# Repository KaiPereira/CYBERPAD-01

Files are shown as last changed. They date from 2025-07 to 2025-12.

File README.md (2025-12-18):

# CYBERPAD-01 - Cyberpunk Inspired Macropad



The CYBERPAD-01 is a cyberpunk inspired macropad with 3 keys, a rotary encoder, and a whole lotta silkscreen and neopixels. It uses KMK firmware and was meant to serve as a learning opportunity for PCB's, CAD and rendering. 
## Custom Features
- Custom lasercut acrylic top panel
- EC11 Rotary Encoder for anything really
- 3 Keys to program to your heart's content
- 14 SK6812 MINI-E LEDs for backlight and and diffusion
- Cyberpunk inspired case for maximum aesthetic
-  Exposed PCB design with custom silkscreen cuz it's sick
## CAD Design

I used Onshape to design all of my parts. The laser cut acrylic panel is held together using minimalist bolts and spacers attached to the top plate. The actual case is designed so that everything can fit together seamlessly without using any screws or bolts for minimalism and aesthetics while still being secure.

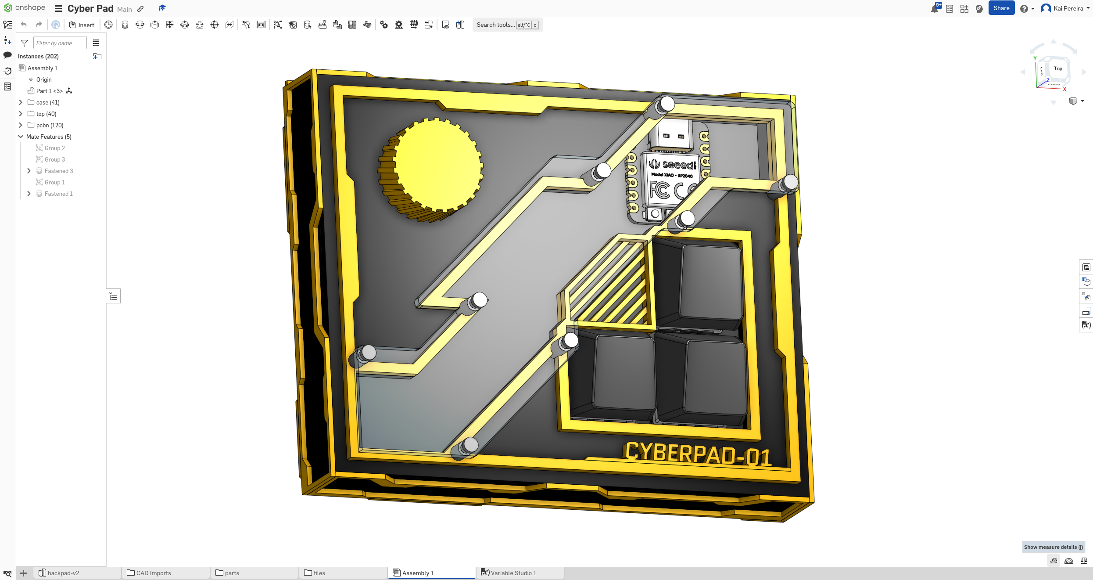
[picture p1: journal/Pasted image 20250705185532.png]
Pasted image 20250705185532.png


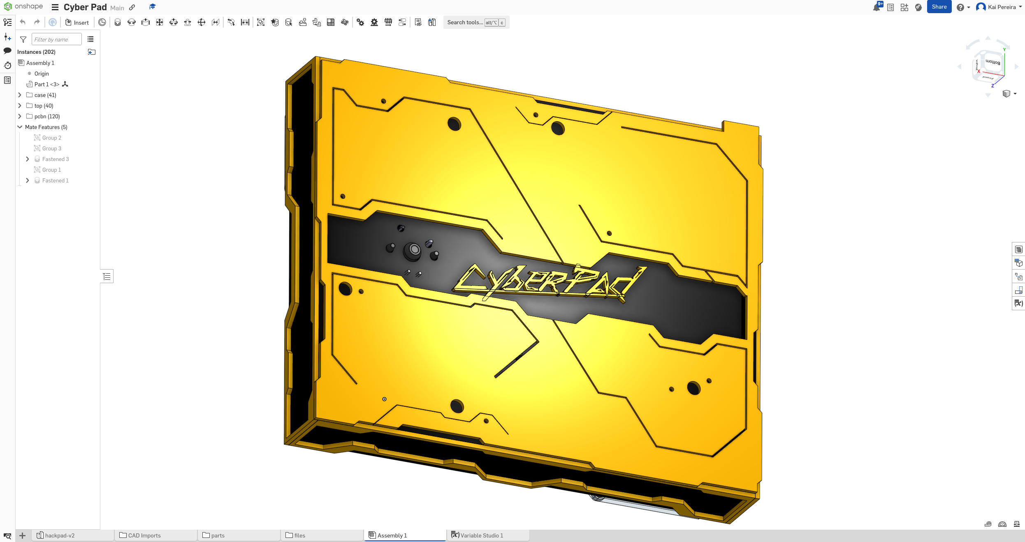
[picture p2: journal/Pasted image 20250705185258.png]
Pasted image 20250705185258.png


It comprises of 4 separate 3D printed parts though, the bottom plate/aesthetic walls, the walls, and the top plate, the rotary encoder knob, with the 5th part being the laser cut acrylic top panel, so it's a bit difficult to print, but manageable. [Onshape Link](https://cad.onshape.com/documents/183c405de5c750134bf8a1de/w/282fa5c96ffeba0ae16f58ec/e/f98acd70bf74a51e29d61d0d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)
## PCB Design

The PCB was designed using KiCad and then I used Figma and the KiCad image converter for creating the silkscreen layers. I actually imported the case design into KiCad so I could use it as reference for the silkscreen which turned out really well.

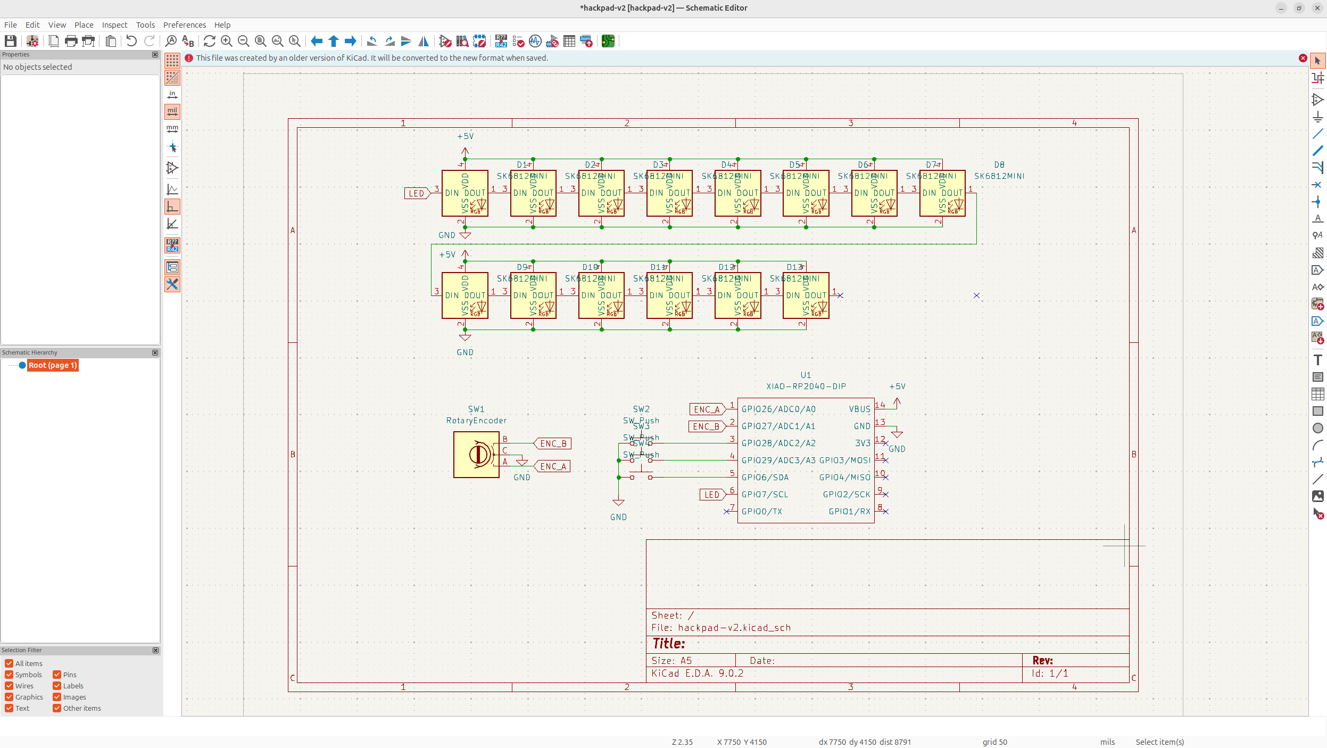
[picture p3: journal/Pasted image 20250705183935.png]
Pasted image 20250705183935.png

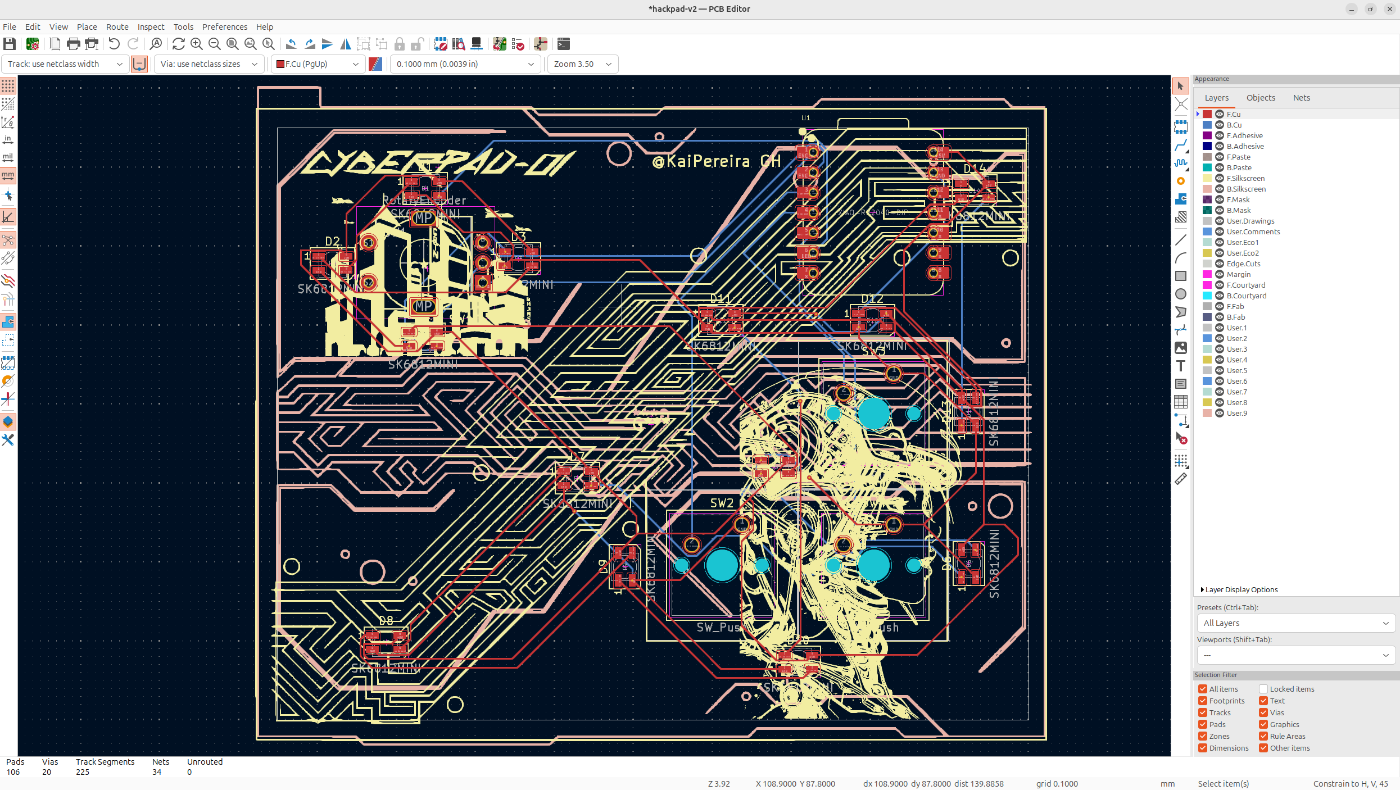
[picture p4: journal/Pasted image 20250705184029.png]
Pasted image 20250705184029.png


## Firmware

The CYBERPAD-01 uses KMK firmware (written in Python) and was relatively straightforward.
- The rotary encoder changes volume
- The keys just act as VIM macro's
- Neopixels to backlight and diffuse any color you want

I'll probably make it a bit more complicated in the future, but I think it's kind of handy to have a macropad for some really complicated VIM stuff.

## Bill of Materials (BOM)

Here's everything you'll need to build the CYBERPAD-01:
- 3x Cherry MX Switches
- 3x Keycaps of your choice (I would personally suggest black ones)
- 14x SK6812 MINI-E LEDs
- 1x EC11 Rotary Encoder
- 1x Seeed XIAO RP2040
- 8x M2 Nut and Bolt, 1.5cm, Low profile top
- 8x M2 Spacers, 3mm diameter, 0.6cm, circular, non-threaded
- 1 Case (3 printed parts)
- 1 Custom Laser Cut Acrylic Panel

## Credits and Help

Thanks to @qcoral and @acornitum for starting highway and reviewing projects. @M0HID and @jamdotjar for helping me with Blender and @cheyao for the firmware starter code and helping me make my first macropad!

Also, thanks so much to [PCBWay](https://www.pcbway.com/) for sponsoring the yellow silkscreen PCB's, they look absolutely amazing and I'd highly suggest checking them out if you need really cool looking PCB's and fast turnaround!

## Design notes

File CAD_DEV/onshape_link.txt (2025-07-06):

https://cad.onshape.com/documents/183c405de5c750134bf8a1de/w/282fa5c96ffeba0ae16f58ec/e/f98acd70bf74a51e29d61d0d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

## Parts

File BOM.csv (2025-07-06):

Part | QTY | Cost | Supplier | Purpose | Notes | Other Notes
From Hackpad Kit
SK6812 MINI-E LEDs | 14 |  |  | Neopixels for PCB
MX-Style switches | 3 |  |  | Switches for PCB
EC11 Rotary encoders | 1 |  |  | Rotary Encoder for PCB
Seeed XIAO RP2040 | 1 |  |  | MCU for PCB
Keycaps - Painted | 3 |  |  | For decoration
Sourcing Myself
M2 Bolts, 1.5cm, Low profile top | 8 |  | Already Have | For bolting the acrylic
M2 Spacers, 3mm diameter, 0.6cm, circular, non-threaded | 8 |  | Already Have | For spacing the acrylic from the top
3D Printed Case | 1 |  | Going to get my cousin to print
Acrylic Top Plate | 1 |  | Already Have | Decoration
EVERYTHING IS SOURCABLE MYSELF WITHOUT THE GRANT

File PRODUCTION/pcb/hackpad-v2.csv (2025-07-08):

Id | Designator | Footprint | Quantity | Designation | Supplier and ref
1 | D5,D7,D12,D9,D1,D10,D11,D6,D2,D4,D14,D13,D3,D8 | LED_SK6812MINI_PLCC4_3.5x3.5mm_P1.75mm | 14 | SK6812MINI
2 | SW2,SW3,SW4 | SW_Cherry_MX_1.00u_PCB | 3 | SW_Push
3 | SW1 | RotaryEncoder_Alps_EC11E-Switch_Vertical_H20mm | 1 | RotaryEncoder
4 | U1 | XIAO-RP2040-DIP | 1 | XIAO-RP2040-DIP

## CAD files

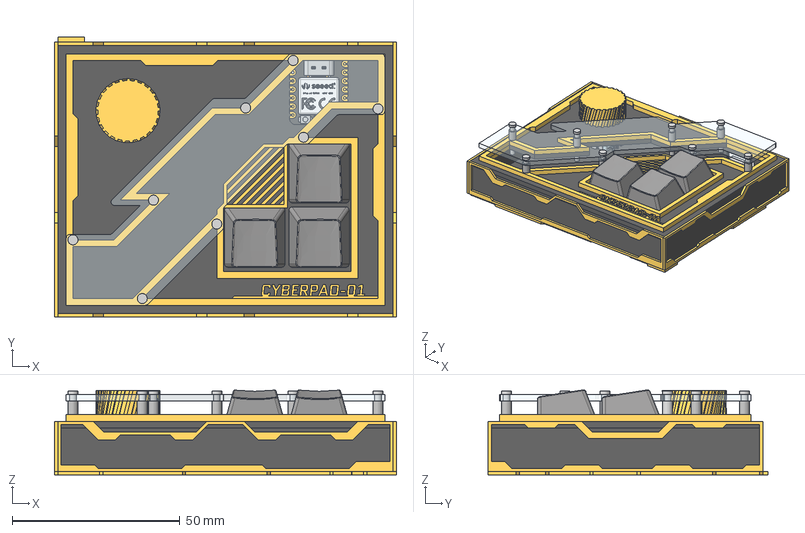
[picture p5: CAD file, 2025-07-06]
CAD_DEV/Full Case.step
102.0 x 83.5 x 25.3 mm
Seeed Studio XIAO RP2040 v26 x 83
Cherry MX_1 x 8
Cherry MX x 8
1x1 R1 v23
EC11 x 9
Cherry MX_2 x 8
_autosave-hackpad-v2_PCB
1x1 R1 v23_2
1x1 R1 v23_1

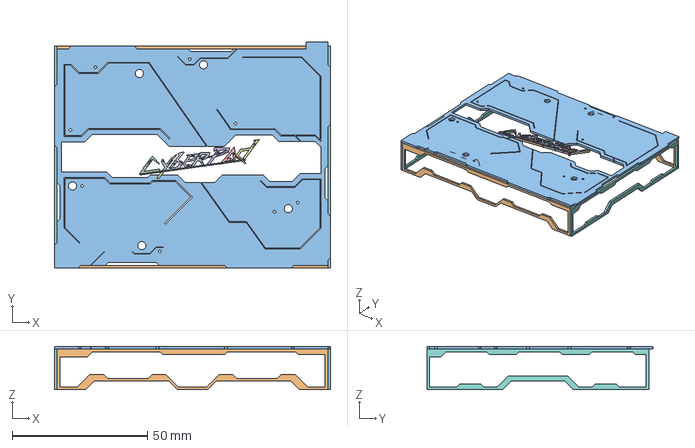
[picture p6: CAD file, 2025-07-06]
PRODUCTION/CAD/CYBERPAD-01 Base.step
102.0 x 83.5 x 16.0 mm

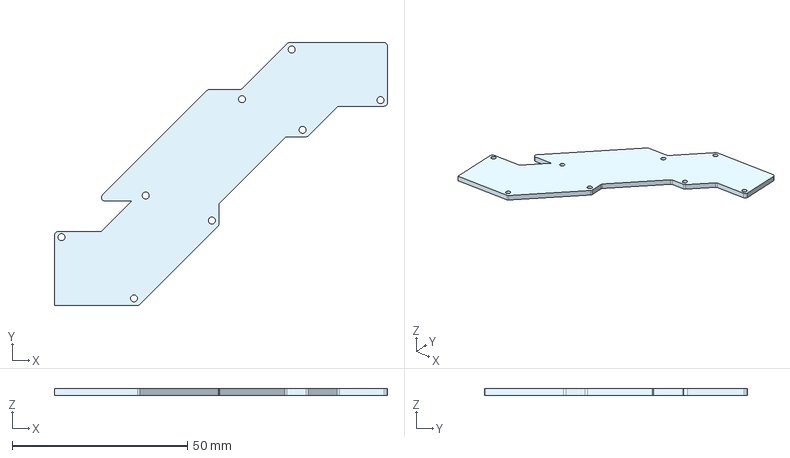
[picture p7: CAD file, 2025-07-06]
PRODUCTION/CAD/CYPERPAD-01 Acrylic.step
95.0 x 75.0 x 2.00 mm

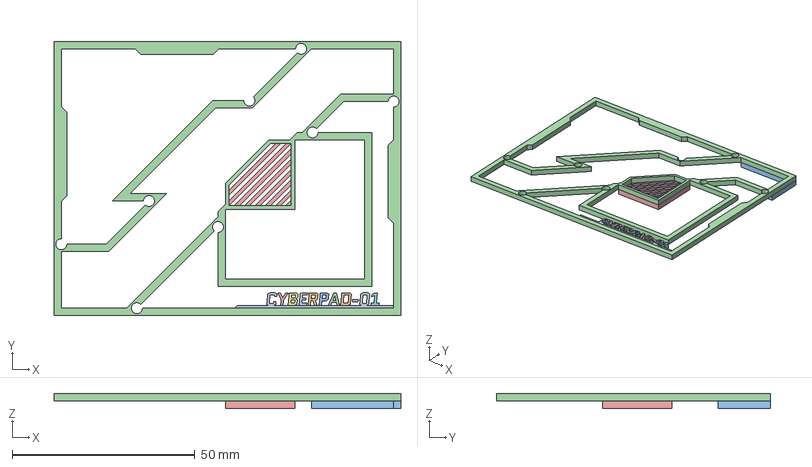
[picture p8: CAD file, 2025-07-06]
PRODUCTION/CAD/CYBERPAD-01 Top Decorational.step
95.0 x 75.0 x 4.00 mm

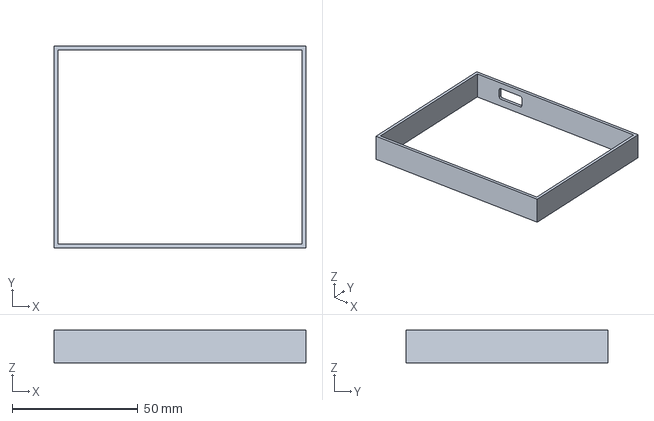
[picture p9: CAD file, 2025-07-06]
PRODUCTION/CAD/CYBERPAD-01 Walls.step
100.0 x 80.0 x 13.0 mm

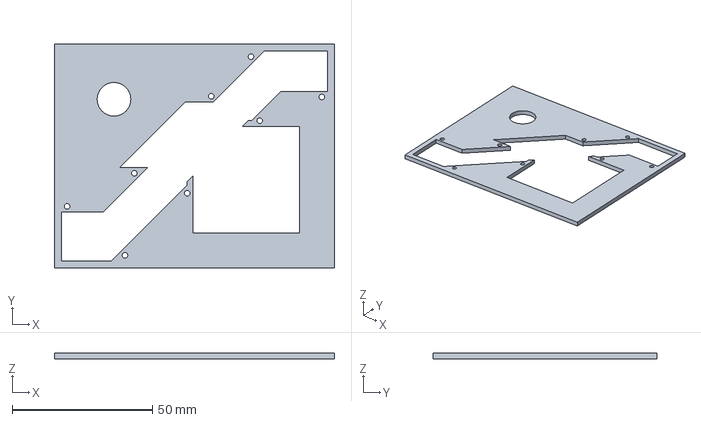
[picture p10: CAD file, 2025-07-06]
PRODUCTION/CAD/CYBERPAD-01 Top.step
100.0 x 80.0 x 2.00 mm

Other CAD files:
RENDERS/Untitled.blend

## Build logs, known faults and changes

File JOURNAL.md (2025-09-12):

---
title: "CYBERPAD-01"
author: "Kai Pereira"
description: "3 key, cyberpunk inspired macropad with backlight and a rotary encoder"
created_at: "2025-07-08"
---

## Total Time Spent on This Project: 29 Hours

## Day 1 - PCB - 5 Hours - Jun 30th

The Cyber Pad is going to be an extremely futuristic looking macropad.

It's going to be a test of my design skills and just a fun side project I want to build.

I really like the cyberpunk aesthetic and want to make a series of projects that go with the theme, maybe ending up with a cyberpunk themed 3D printer.

Anyways first I'm going to do some drawing and brainstorming on how I want this thing to look.

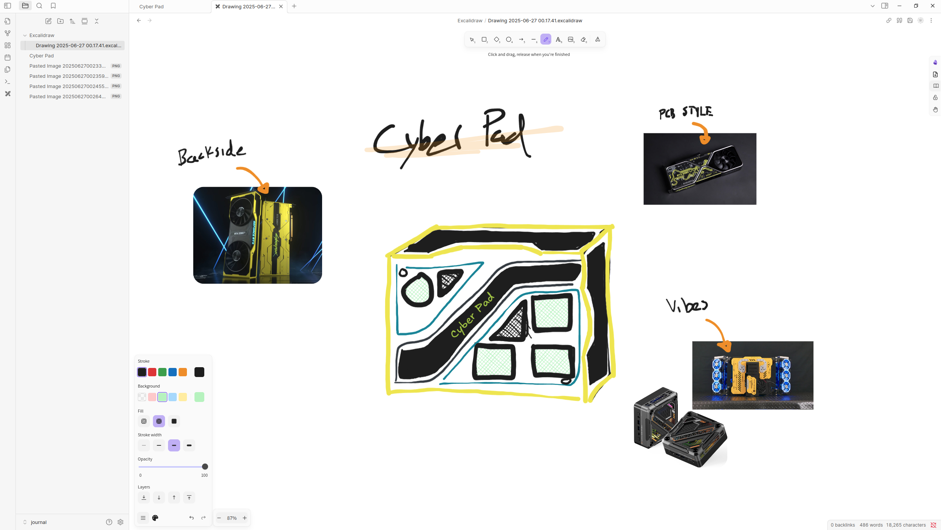
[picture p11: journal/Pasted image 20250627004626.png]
Pasted image 20250627004626.png


Anyways this is my main inspiration that I spent some time on, I really like the buttons like this so I think I'm going to leave it like that. I don't want any OLED's or anything because I feel like that ruins the vibe so I'm going simple with a major focus on the design.

Also this design seems quite blocky but the actual thing will be nice and round.

Now let's whip up a quick schematic. I'm trying to stick to best practices possible and I'm going to do the neopixels once I'm done my case!

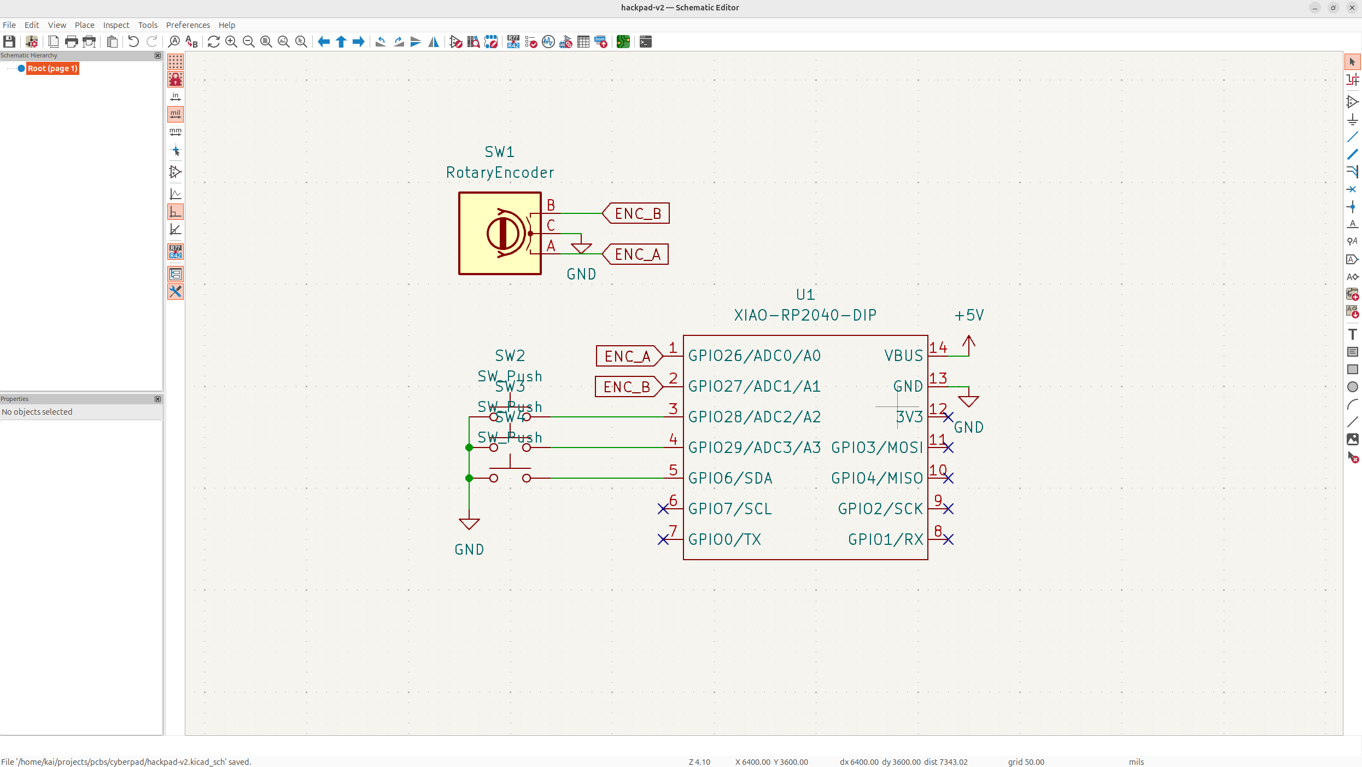
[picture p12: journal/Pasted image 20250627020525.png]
Pasted image 20250627020525.png


Now time to do the PCB, took me quite a long time because I was figuring out some footprint and alignment stuff.

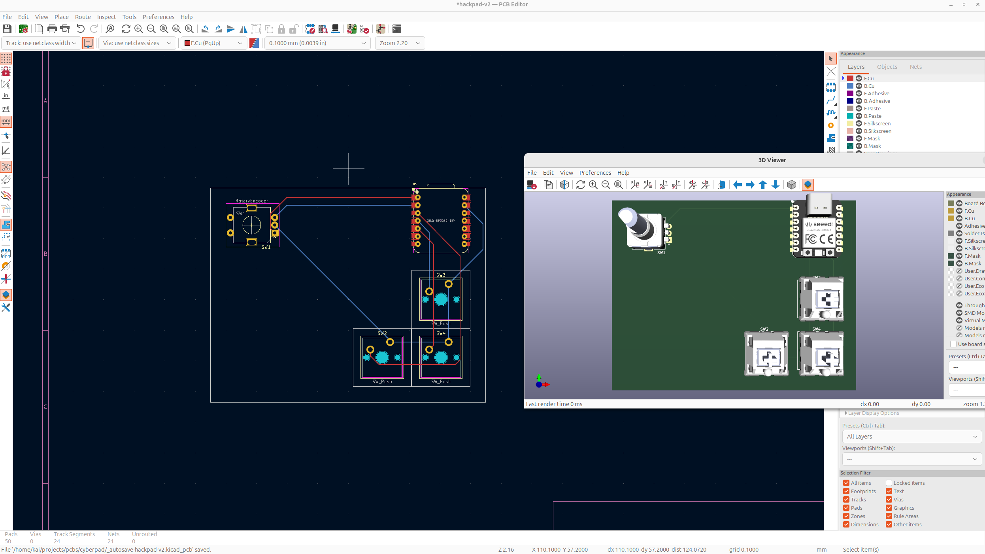
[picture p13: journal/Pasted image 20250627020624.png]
Pasted image 20250627020624.png


## Day 2 - Case - 8 Hours

Now I'm going to start modelling the case, I'm going to give about 1cm total on each side just as a placeholder and then I'm going to model the main interior of the bottom I want to go for.

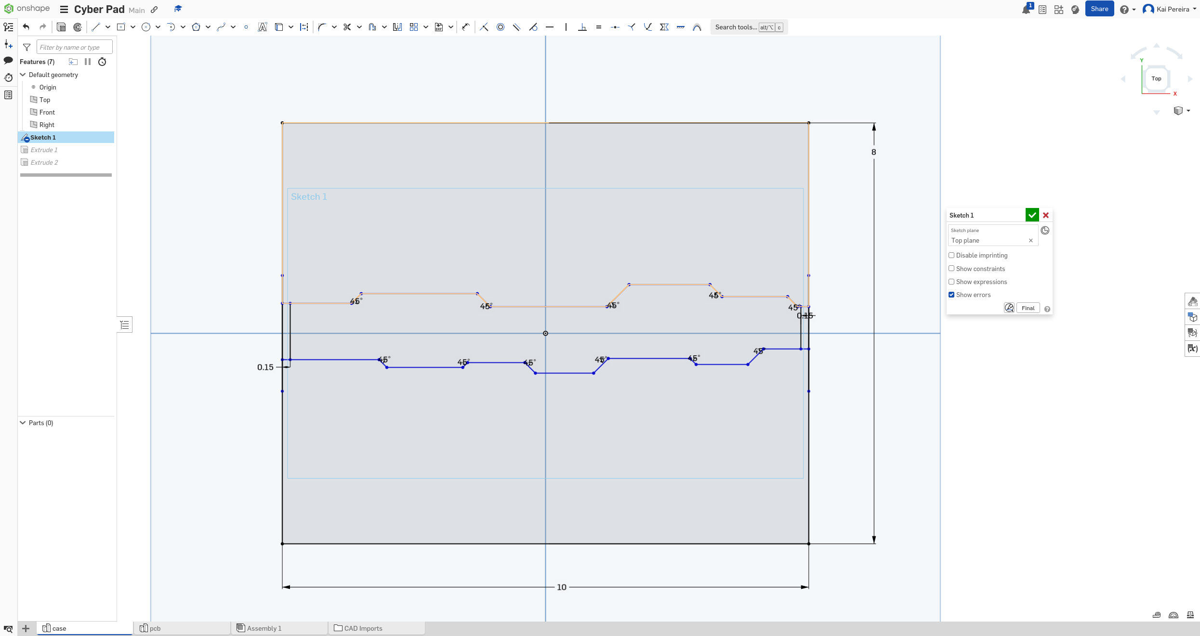
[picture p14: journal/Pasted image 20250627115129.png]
Pasted image 20250627115129.png


Now that I have this base, I'm going to add some designs along the side. I like the way the graphics card is done, so I'm going to do something similar to that.

Now I kind of want to go with a polarizing like effect which will go with the top of my case:

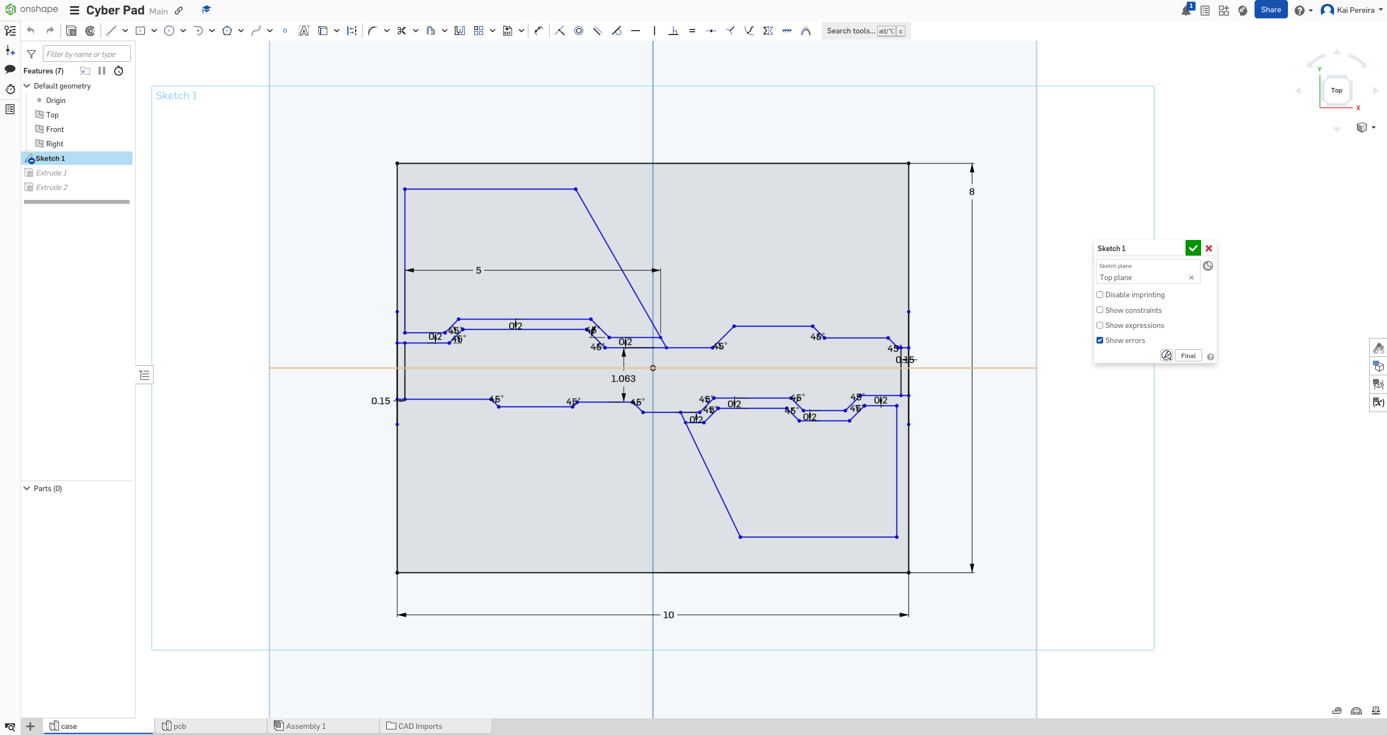
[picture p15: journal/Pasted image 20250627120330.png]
Pasted image 20250627120330.png


Now I kind of want to with with some other designs just to fill the space, I'll look into the graphics card design a bit more and kind of go off that. And now I have a really col base to go off of:

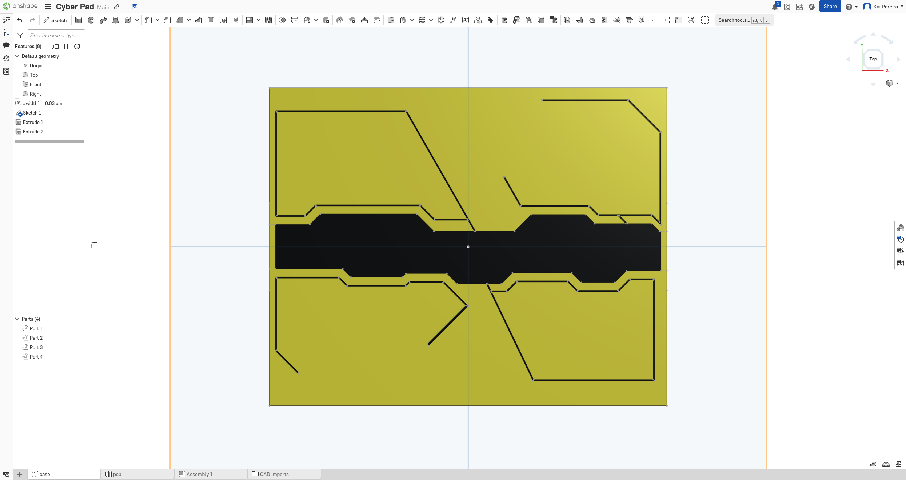
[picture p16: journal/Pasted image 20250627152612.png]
Pasted image 20250627152612.png


Now I'm going to make the shapes a bit more complicated to give it some detail. Now it's looking sick.

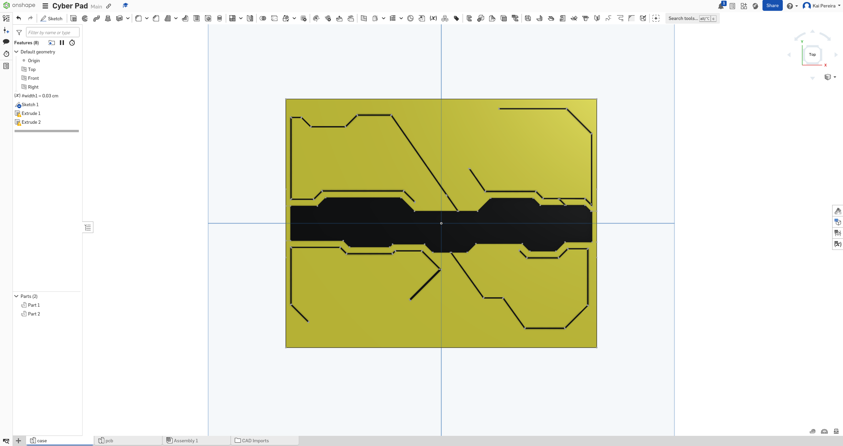
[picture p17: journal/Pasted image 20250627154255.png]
Pasted image 20250627154255.png


Now I really like this style where there's details on the top and bottom, and circles where all the divits are, so I'm going to first add the cool bottom and top details.

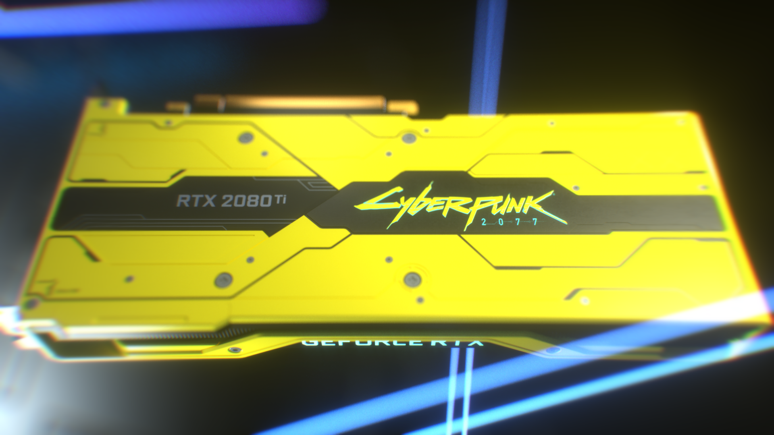
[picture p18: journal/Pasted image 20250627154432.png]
Pasted image 20250627154432.png


And the minor details are really starting to add up.

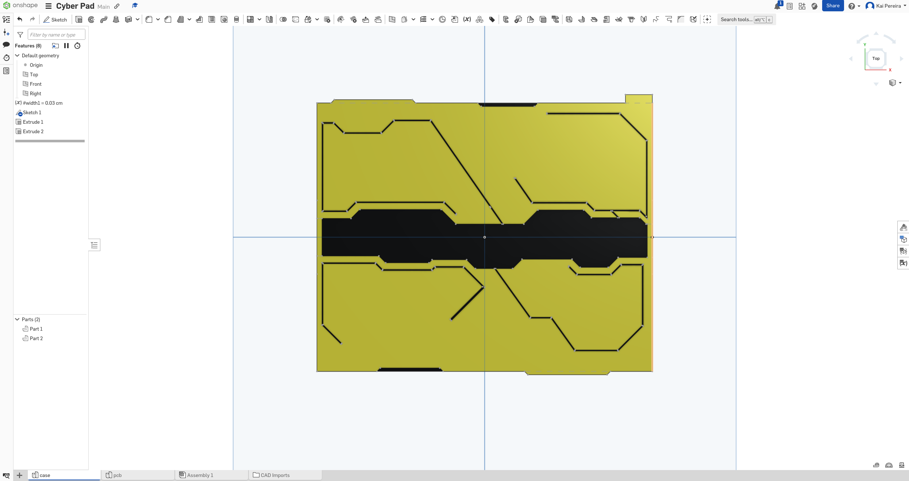
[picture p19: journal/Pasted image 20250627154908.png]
Pasted image 20250627154908.png


Now I want some of those extra thin lines. It's starting to look incredible!

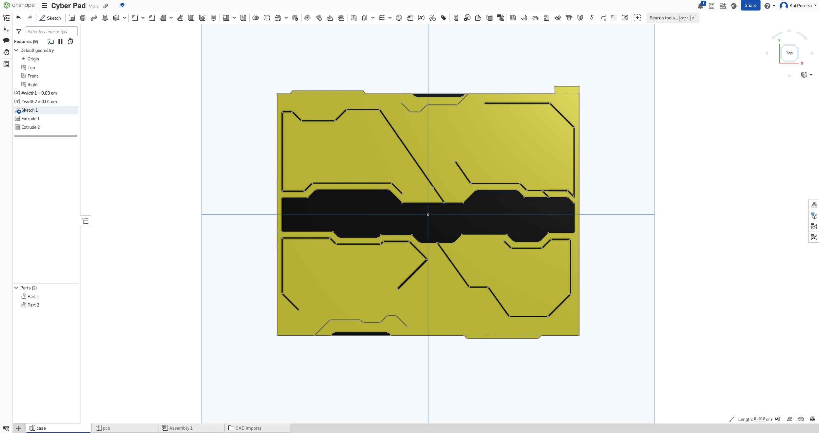
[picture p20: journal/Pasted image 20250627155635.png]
Pasted image 20250627155635.png


Next I added the circles and the logo. The logo is done in inkscape with the Cynata font.

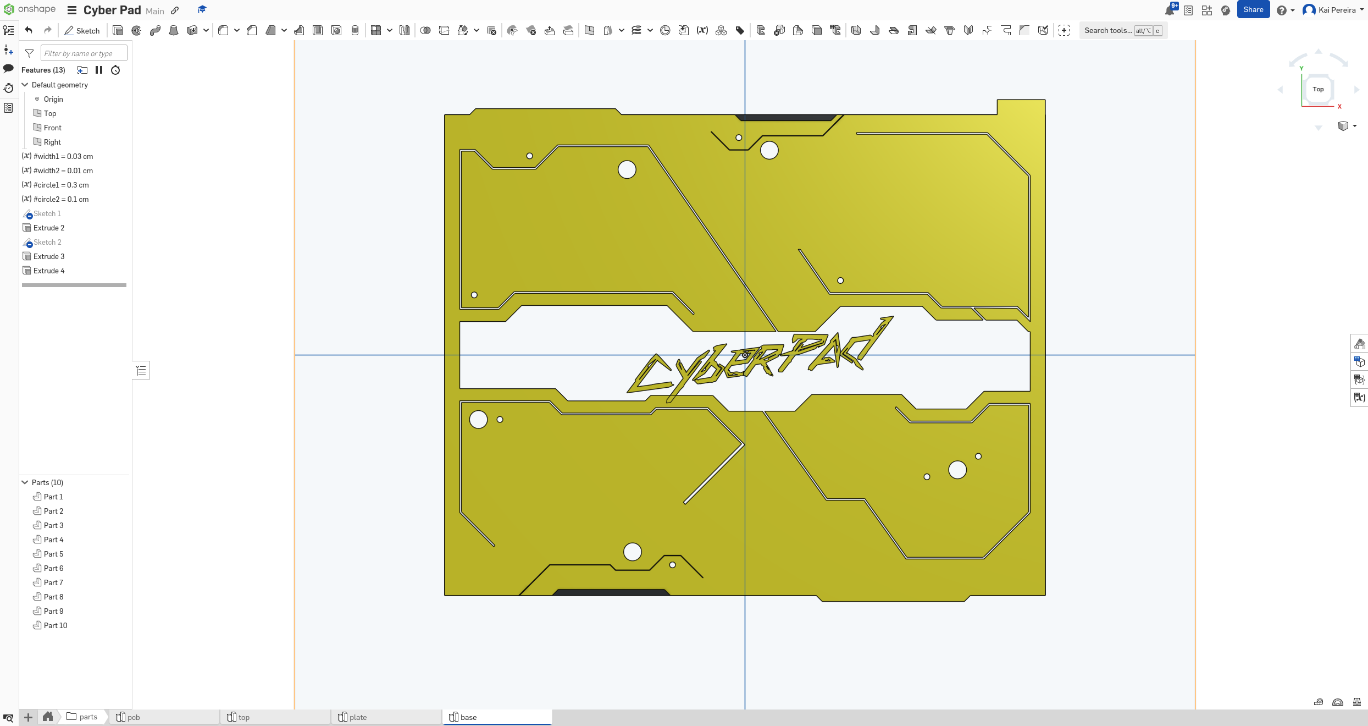
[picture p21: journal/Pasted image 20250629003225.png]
Pasted image 20250629003225.png


Next I added some walls to it, and then created the plate and top plate.

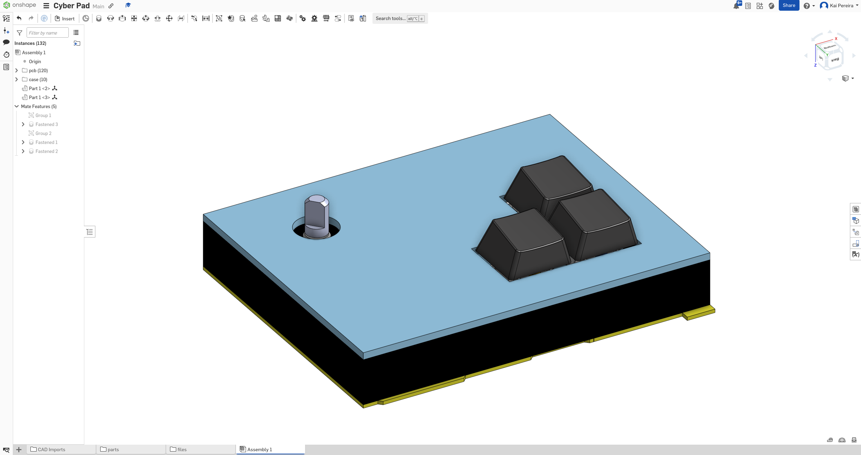
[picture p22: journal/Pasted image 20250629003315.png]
Pasted image 20250629003315.png


Now I'm going to start working on the side designs. I want them to be pretty similar to the GPU design and then make the top like the PC.

Anyways next I added the side designs, I've mirrored each side onto the other side for simplicity and it's looking even better now!

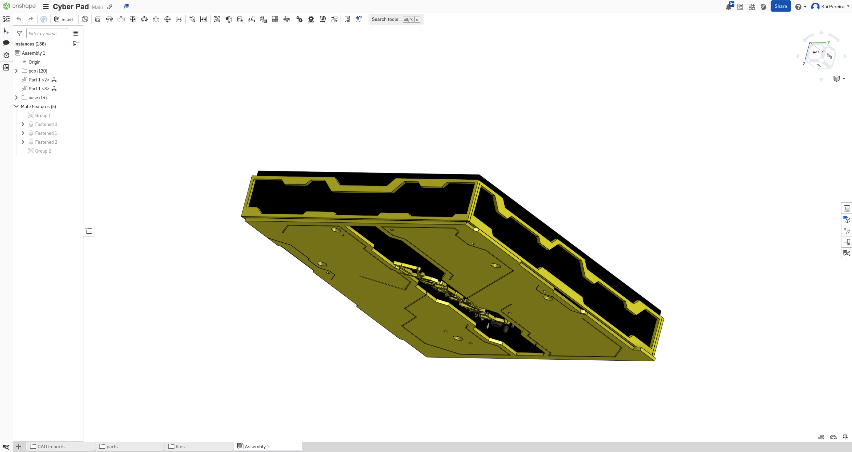
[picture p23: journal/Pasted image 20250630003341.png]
Pasted image 20250630003341.png


Now I kind of have to figure out what I want to do for the top. I really like this style and kind of want to go for something similar. 

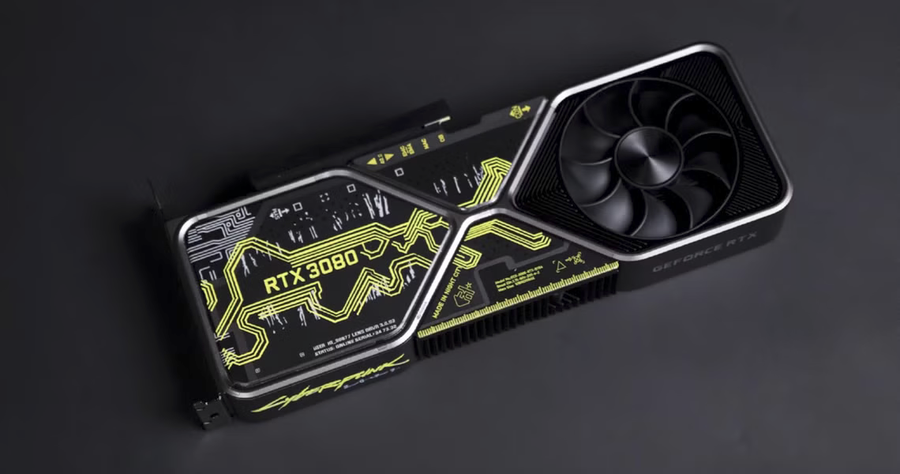
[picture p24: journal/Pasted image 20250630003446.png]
Pasted image 20250630003446.png


I might actually play around with my hackpad colors too, maybe a different color would look better like this green or something. Anyways next I'm going to work on the top. I don't actually have anything in mind, so I'm just going to kind of stick to the same style for now and add more detail later.

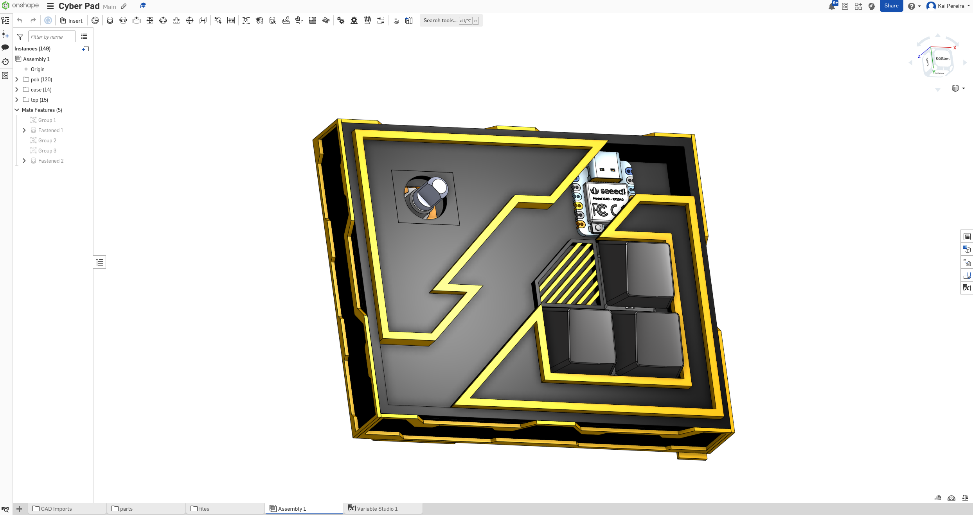
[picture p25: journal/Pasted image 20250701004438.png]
Pasted image 20250701004438.png


And that looks fitting but still now exactly what I want. I really want to see what it would look like if I put a piece of acrylic over the gap now.

This took a long time and I'm sorry I didn't journal all of it, but I added a knob, the acrylic and some text on the bottom. Looking absolutely insane now.

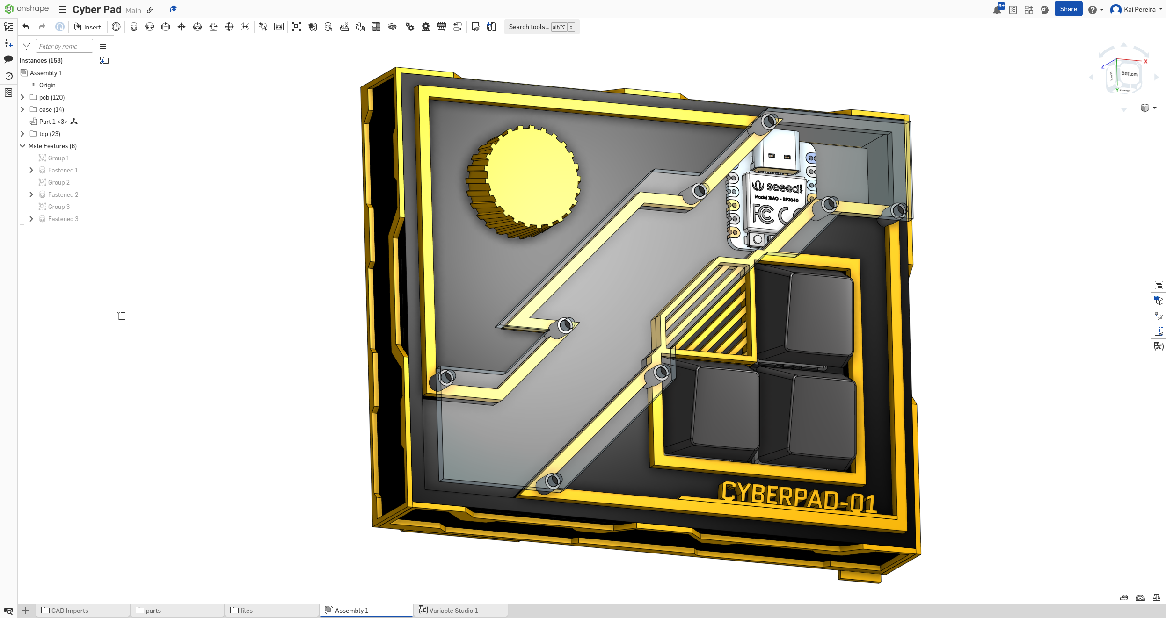
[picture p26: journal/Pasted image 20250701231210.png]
Pasted image 20250701231210.png


But we are not finished, nowhere near the craziness I want. Next I'm going to add all the extra little things to give it dimension. 

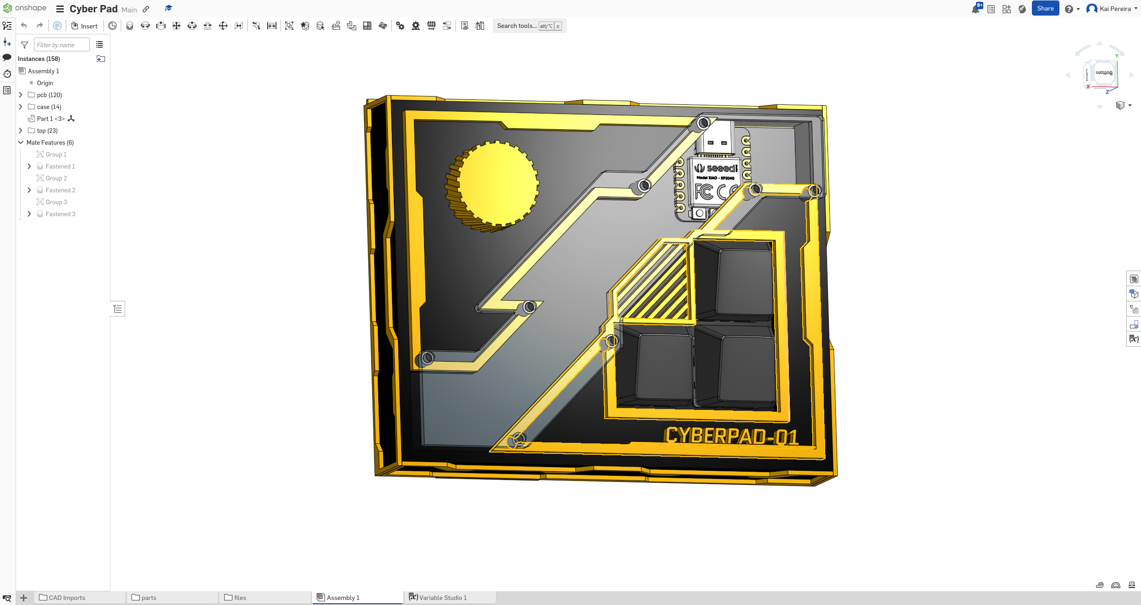
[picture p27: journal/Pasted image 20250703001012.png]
Pasted image 20250703001012.png


I also refined the design a bit so it's easier to print and it looks pretty good. 

## Day 3 - Refining the PCB and Case - 4 Hours

Next I need to customize the PCB so that it looks rlly cool inside of the case. I wanna go for like exposed trace with cyberpunk drawings style. I used the case DXF as a reference point, and then used figma to draw the lines. Then I just add the image properly scaled to kicad.

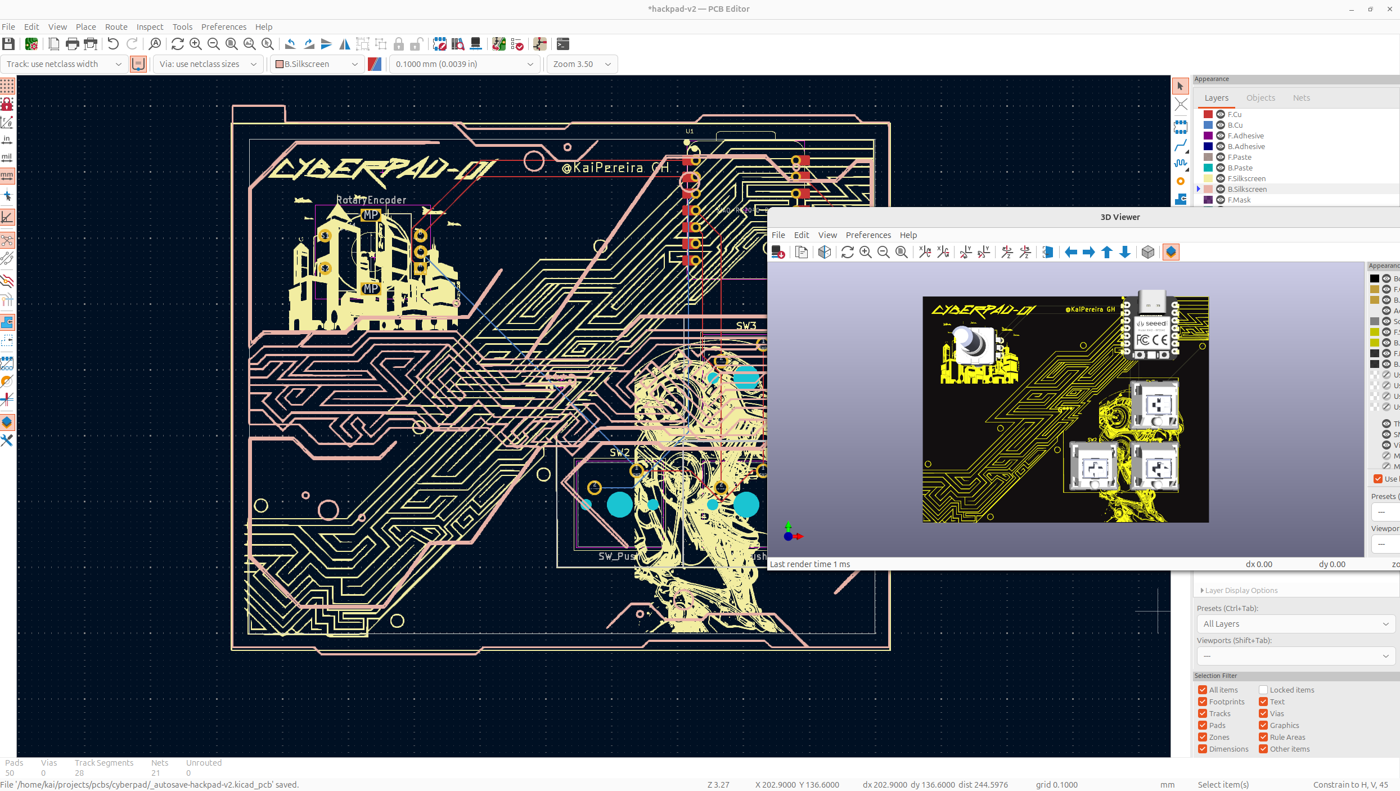
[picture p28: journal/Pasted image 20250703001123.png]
Pasted image 20250703001123.png


Now I completely forgot to add the neopixels so let me do that real quick.

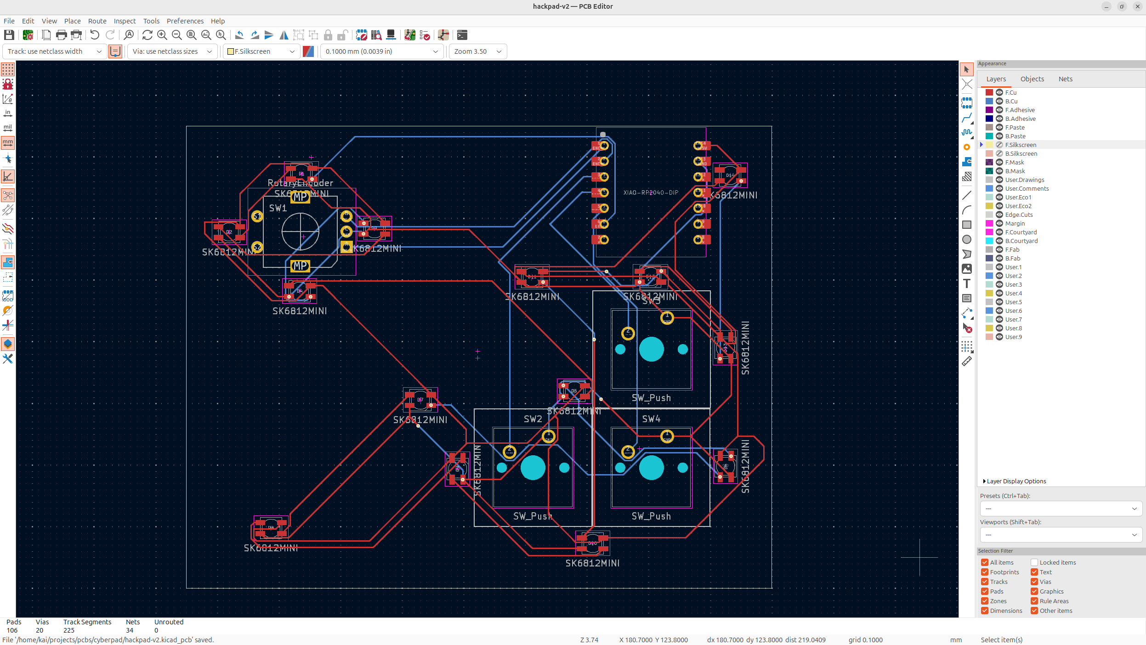
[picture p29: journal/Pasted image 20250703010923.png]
Pasted image 20250703010923.png


Rewired + new schematic.

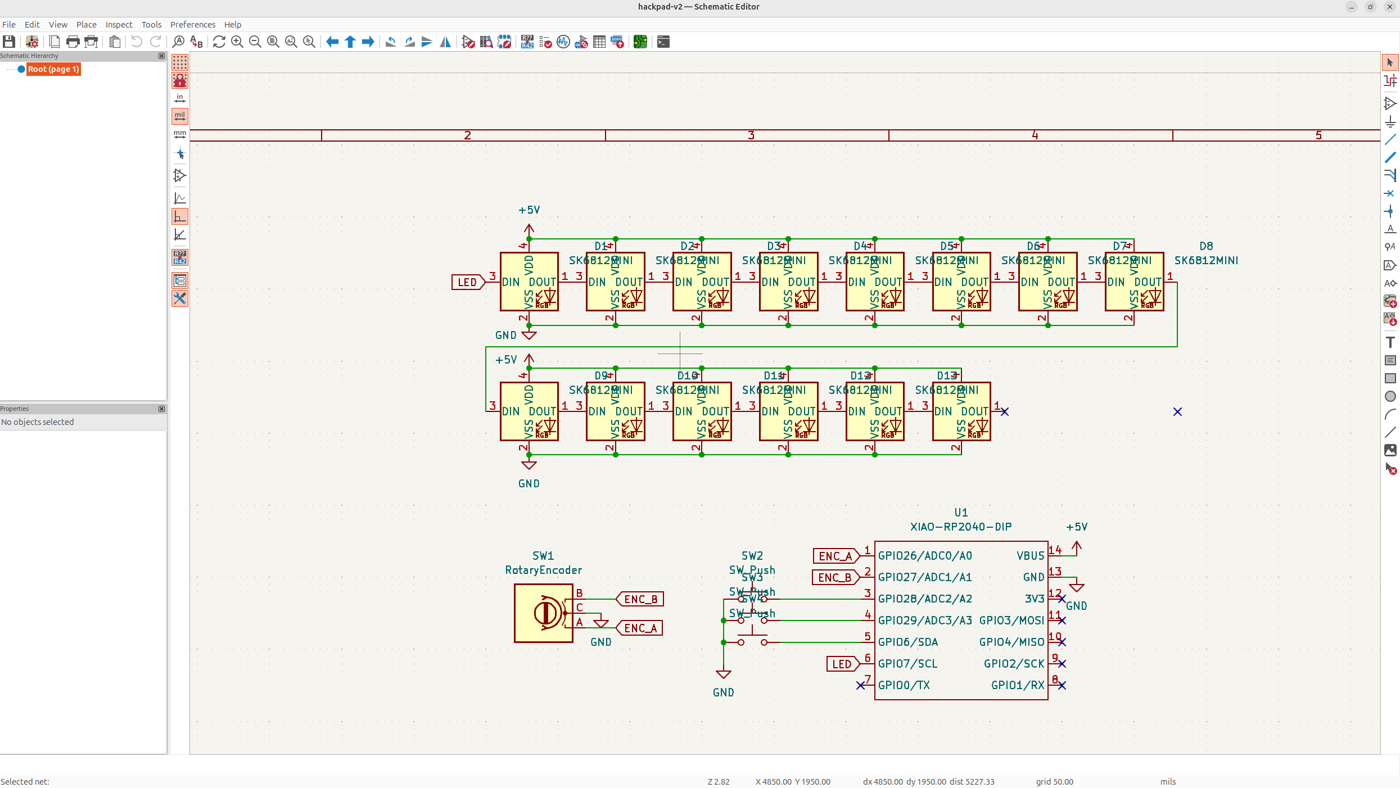
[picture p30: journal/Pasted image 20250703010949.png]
Pasted image 20250703010949.png


Next I did the firmware. It was really simple, just some python with KMK.

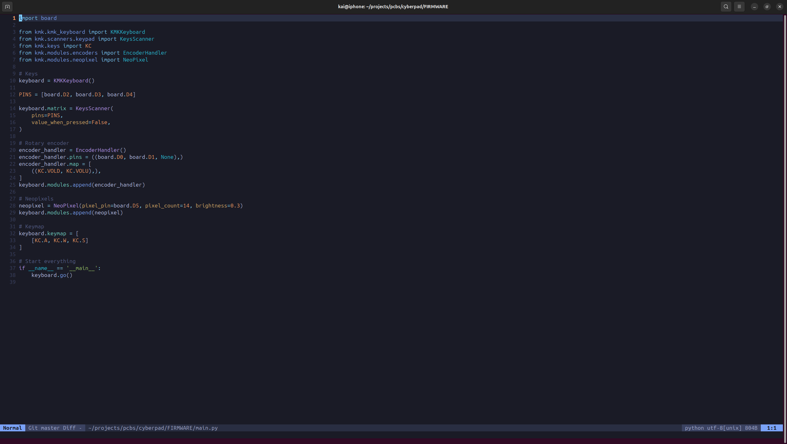
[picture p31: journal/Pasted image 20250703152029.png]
Pasted image 20250703152029.png


Next I completely forgot but I needed a USB port so I added that in.

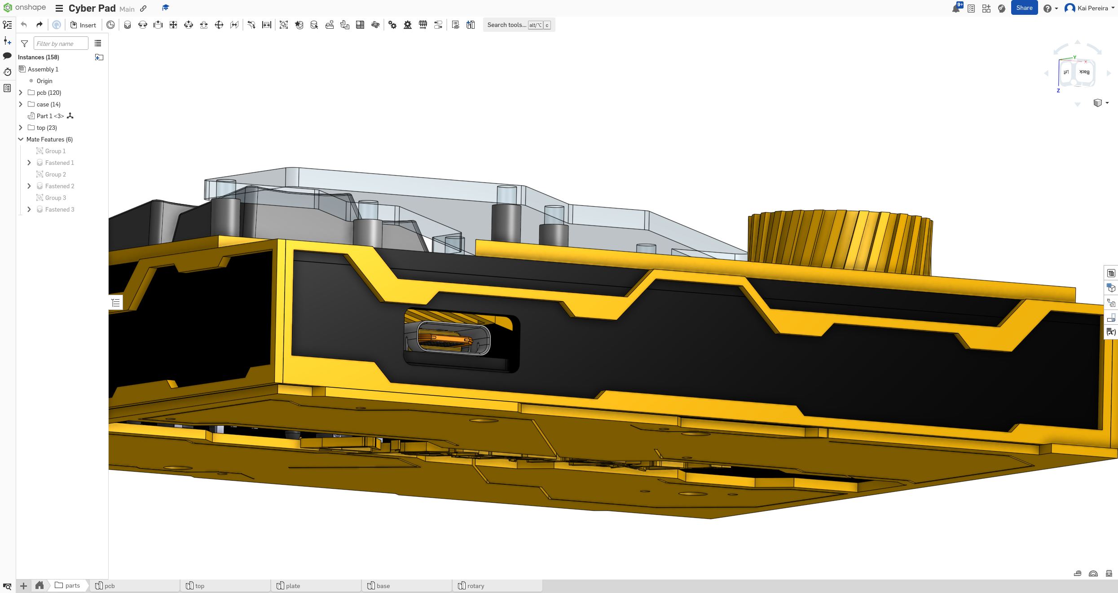
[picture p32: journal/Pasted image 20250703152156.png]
Pasted image 20250703152156.png


Then I'll just add the bolt heads and such, and we're done with the case!

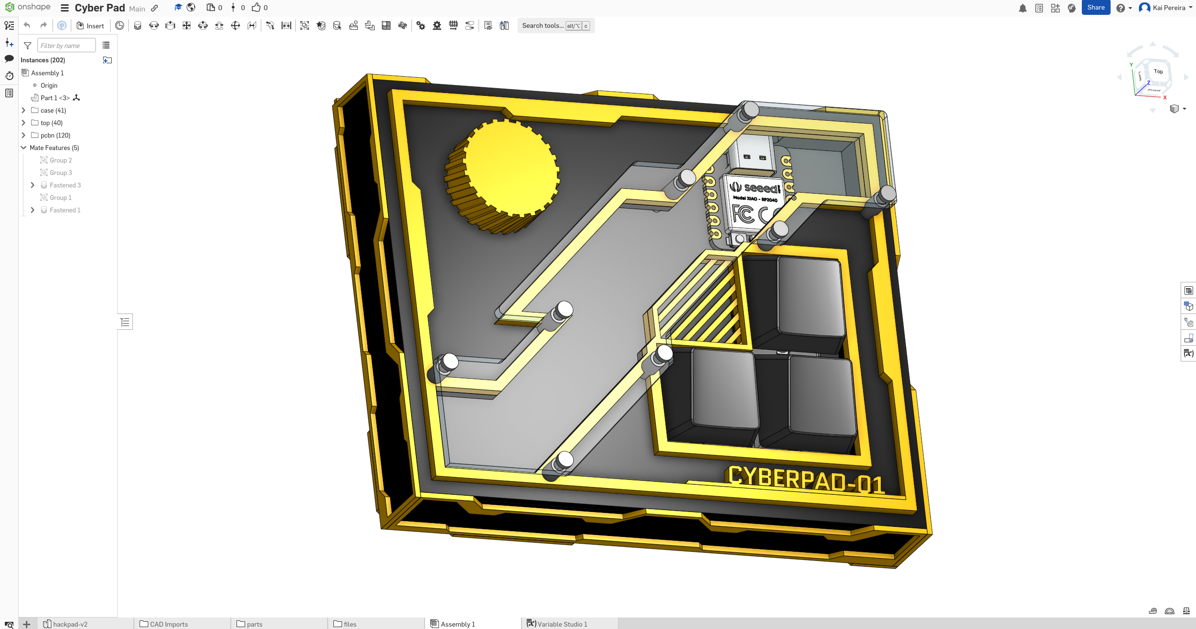
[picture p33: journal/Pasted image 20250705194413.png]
Pasted image 20250705194413.png


## Day 4 - Rendering - 6 Hours

Now I've never used Blender before, but I really want to render my case and PCB. But before that, I have to update my KiCad! And it may have taken me way too long, but after 2 hours, I've updated KiCad.

Now I can export the PCB with silkscreen (brand new feature!!) and add it to blender alongside my case.

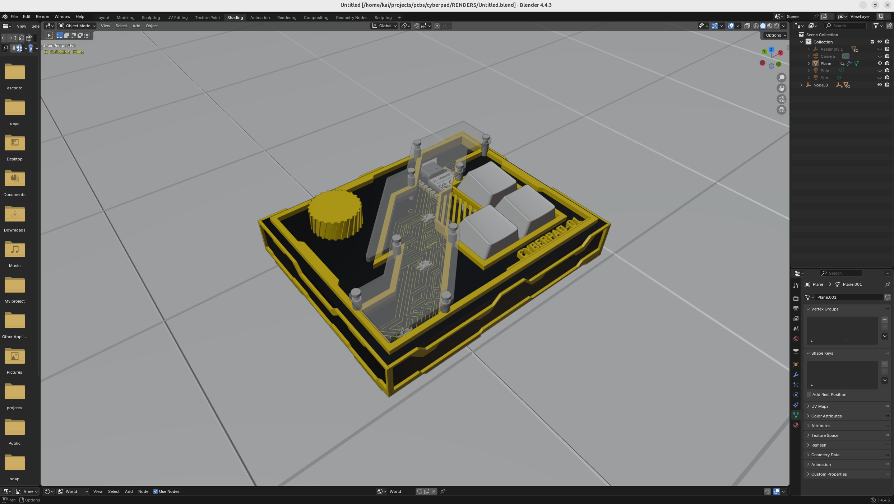
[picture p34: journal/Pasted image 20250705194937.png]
Pasted image 20250705194937.png


I've also added this cool blueprint effect on the plane I've put my model on which will look really futuristic in the render. To do this, I just used a wireframe on the plane and then gave them 2 different meshes. Now all this stuff took way longer than I'm making it seem but yeah that's basically what I did.

Next I added all the meshes and rendered everything, I couldn't figure out lighting so I may or may not have just used the photo's from the render without light.

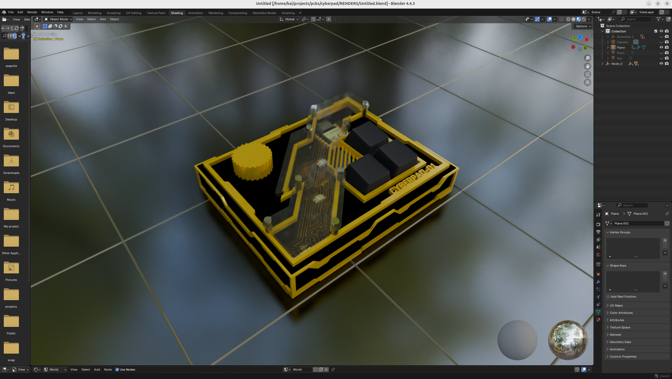
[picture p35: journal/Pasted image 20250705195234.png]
Pasted image 20250705195234.png


And there's our render completed!

## Day 5 - GitHub Shenanigans - 2 Hours

Now I needed to add all of this to GitHub, I left everything pretty organized so it won't be too much of a hassle! I pretty much have everything in there except for the production files so let's add those!

First I'm going to add all my CAD files, I'm going to put all the separate files I need to 3D print, I have to separate all of the different parts to 3D print, but it's not too complicated so I got through with relative ease.

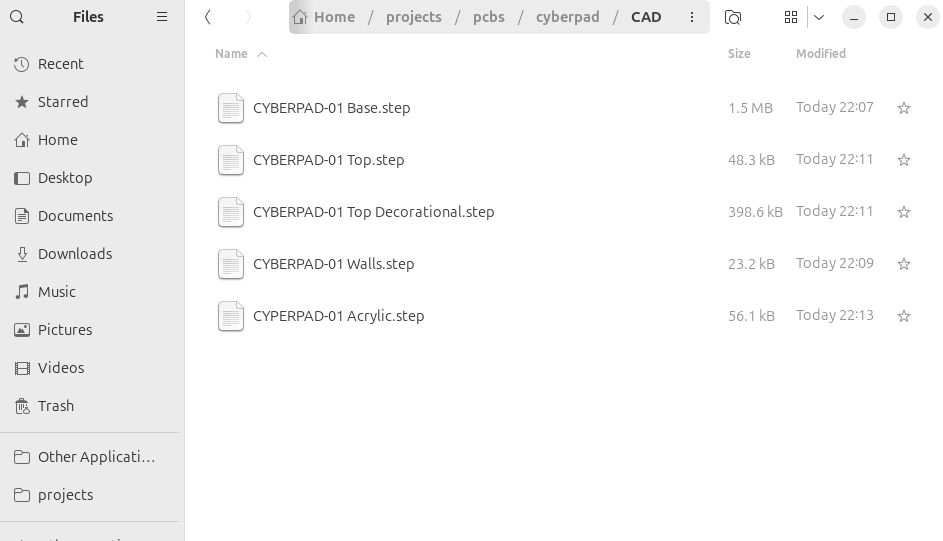
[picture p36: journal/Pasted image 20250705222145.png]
Pasted image 20250705222145.png


Next I need the production files, all the files I need to actually make my PCB. This is just the:
- All PCB gerbers, drills, pick and place, etc.
- All 3D printed parts
- All firmware

So I just moved my CAD folder into this new one, move the firmware file, and then made a ZIP file with all the gerbers and stuff.

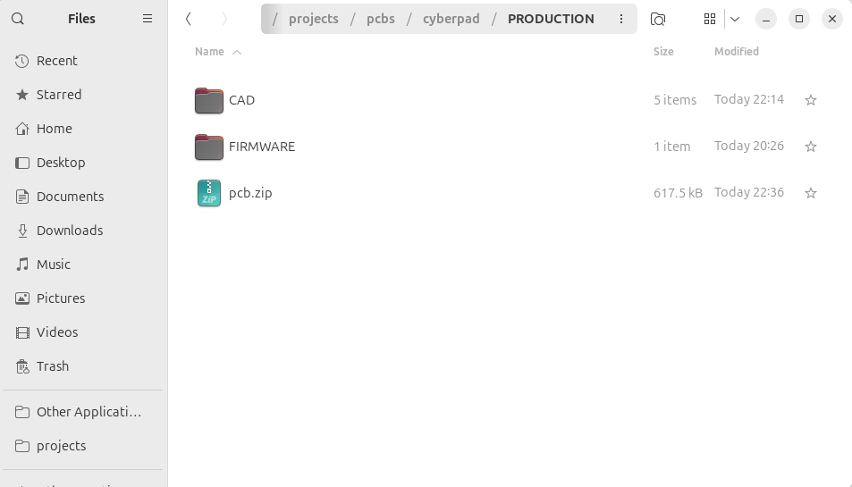
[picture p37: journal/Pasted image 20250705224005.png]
Pasted image 20250705224005.png


And then finally, I had to add a new CAD folder with just my full case and then I also added my Onshape link as a txt just for the people that are looking there. And that is actually everything!

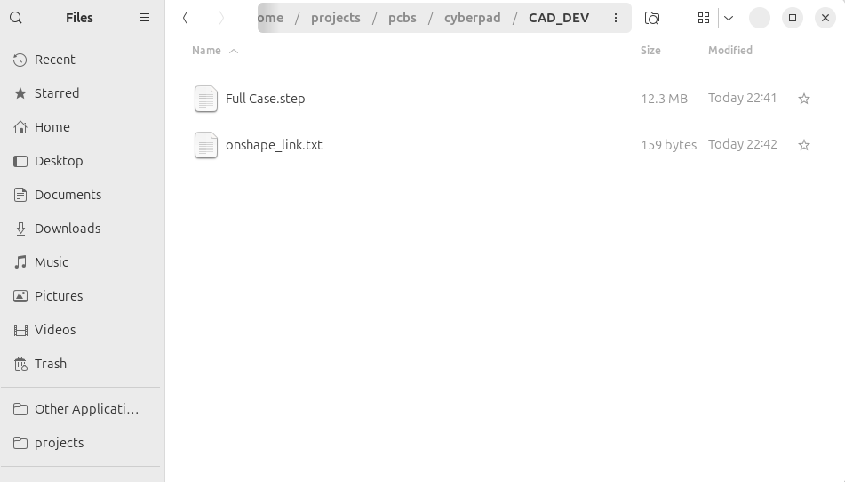
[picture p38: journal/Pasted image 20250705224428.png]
Pasted image 20250705224428.png


## Day 6 - Soldering and Case - 4 Hours

I like to order my days chronologically, but a couple weeks have passed! Now I've receive my boards and just have to solder them and assemble it. So first things first, I whipped out all the soldering stuff.

I like to use my trusty pinecil with resin core leaded solder and then I use some wire cutters to cut off the strands.

Something I learned about doing the neopixels, especially SMD like this, is to tin the pads, and then bend the leads so that they touch all the pads, and then just touch the solder to the pads, works very nicely.

Anyways, the boards turned out very nice, and then I added some github keycaps onto them.

Pasted image 20250807050448.png

Next I needed to assemble the case. I just glued the walls onto the sides nicely, and then I actually forgot to get the top part of my case printed, so I used duck tape to like hold it in place, and I feel like it turned out pretty nice. 

I skipped on the acrylic for now, but all stuff I need to do when I get back from my vacation:

Pasted image 20250807050609.png

And then I just simply uploaded my code, and booted up the XIAO using the UF2 from the circuit python website, and it was ready to go!

I'm a bit sad I didn't get the neopixels to work in time for my trip, but I'll get them working eventually!

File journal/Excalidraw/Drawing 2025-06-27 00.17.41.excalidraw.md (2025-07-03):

---

excalidraw-plugin: parsed
tags: [excalidraw]

---
==⚠  Switch to EXCALIDRAW VIEW in the MORE OPTIONS menu of this document. ⚠== You can decompress Drawing data with the command palette: 'Decompress current Excalidraw file'. For more info check in plugin settings under 'Saving'

# Excalidraw Data

## Text Elements
Cyber Pad ^jQov3WkX

## Embedded Files
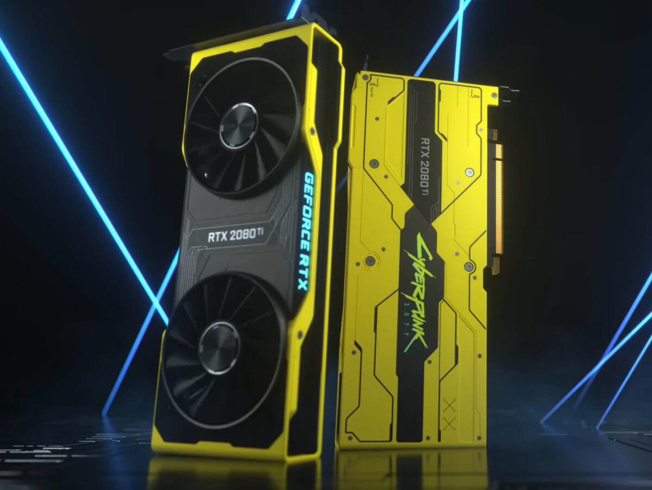
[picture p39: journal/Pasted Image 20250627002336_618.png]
3c734ac1590d5656ee6f02f23bb5e211e4fd1c68: 

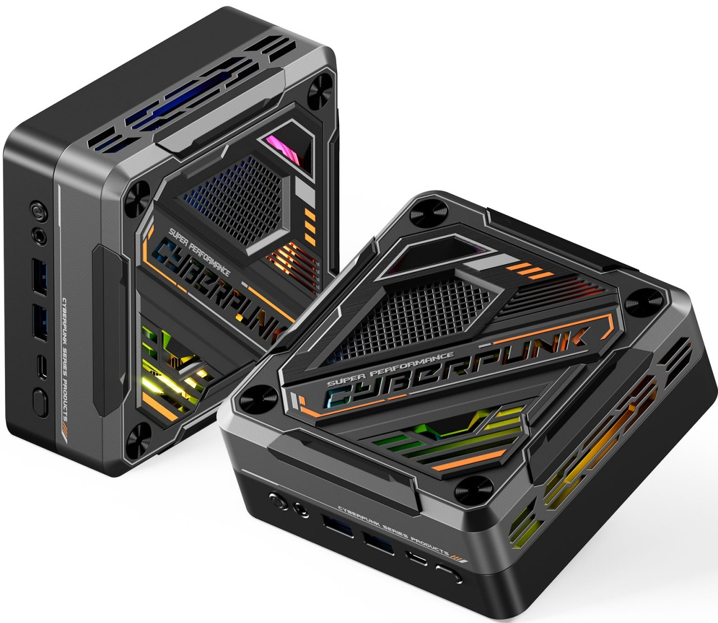
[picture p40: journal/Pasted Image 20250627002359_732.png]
5a2a00264b5a7e55ef661a0aa96c92caa07987ee: 

ac5a94693b64ba3ba6c5d9edc46453bc6e468bbb: 

f3ed05747cb9b0d085393de8ea968cdf033e41b7: 

%%
## Drawing
```compressed-json
N4KAkARALgngDgUwgLgAQQQDwMYEMA2AlgCYBOuA7hADTgQBuCpAzoQPYB2KqATLZMzYBXUtiRoIACyhQ4zZAHoFAc0JRJQgEYA6bGwC2CgF7N6hbEcK4OCtptbErHALRY8RMpWdx8Q1TdIEfARcZgRmBShcZQUebQBGOIAWGjoghH0EDihmbgBtcDBQMBKIEm4IADEAZmV6avpmAA0ADgBFACsATmikgDM+ltIAfQAhVJLIWEQKvsCETyp+Usxu

Z2qk+OXIGDWAVgA2AAZtJKS96sS97YgKEnVuRKObyQRCZWluAHYum+tlYLcZ6FARQUhsADWCAAwmx8GxSBUAMTxBCo1ETUqaXDYCHKcFCDjEWHwxESJEDBDYLpdTGQPqEfD4ADKsEBEkEHjpEGYYMhCAA6vdJNw+CCeXyoayYOz0JzyjcCR8OOFcmgtuK2HAcWpduqjsDJhB8cI4ABJYhq1B5AC6NzmuEyFu4HCETJuhCJWAqOO5BKJKuYVtd7vF

YQWj3iXx4myOXz213FjBY7C4aGqLRuydYnAAcpwxI9ql0eHt4kkDntfuLCMwACLpKARtB9AhhG6aYREgCiwUy2SttpuQjgxFwTeIj3j8QNLS+X3iXSSXxuRA4EJdbvwq7YuObqFb+Hb4rgbE9OXyILABUmJUNt6OV7tV5vD+2JWc8Sf79fk0/77AT9vxfK9AKSACgNvZ9b1/D8Dggr8oJ/UDnBXFDEMmaDJlgwDq1vMBHyQkD8M/DV8IwkosJKHD

P2qACeGAmCUJ4MjbxaRjsOY8DQJnDjqOYtDyIYoimJI6oxXIg4+OvFDqkTciumkmiknvSYYyUlCznoxSRM4kikkzUC5I0ki9gk28kmqEzb2cC4APOay/z2bj8KSHTMOQ0z4NAhNHI/Q4AOOPzAIC0CDiSYLbO8/CDi+SLnIAhd4tYyZo0igzEr2dLzNSuLdP4sSXNvL52PymSSMXRLSo84jbzo0CSuCngcpKeNgozQL3MozyLOi28DiksqcL2QyY

oosAqPK/qismPY8pq0TpoAuanxBKiIDgQIgxEcJ8nW1h9DdccEAABS25gdu4MEhAQVdQigWF9H0NQJxOs9sk3JlCgAX2WYpSnKCRu0wAA1EHuzNI52AAKVwYgeDgaEABVkbgaoAC1uWmcR0DmBAFnIJZxVWNBnB4Gkbj1VBbOqapTnOS5SxuO5iAedV6qNV53k+dN5NKf5ZVUiVwShEkEWRdE0SQDscTxf1iThcXyUpalaXtRkWTZHGeThBUw0lQ

VhVFG5eRFhBpVlHWuUVYRlVVR4bi1HVYEeA0bhNEcLUHdaHSdSc0BDbcay9En0Dhv0u2IQNgy3E38f91BF3iA4ug2Q4OdKbNU0ePDM6YHMOHzDhC31FoDNnecPXrRt90PY8jU7QliF7DIsgvNAh3FEcxwnKcywr6MWgODPIDXDcA9j8V4T3BO69uk93vb61asmVS72CtewHGyacM3qyhtAzesoP/DN66iaesmFKSkSYLr63iKT7qgDF2CmaSma4L

BNvHhBoWvTby50mNUQi/8Cq3hnABS4d9760zvi1MAcCn5XwQRsO+I8ShoOQTfDBiDj5gKmlfXBxkoJrRuJtVUO1vYm0IIdfAx0zqUMCFdUgN07q8kes9GQCw3rnk+vgH6f0awJwgF0fAY4OBHAALIHHRnsaGBwADy1QKAAEF6B6E0BuG42NZjzEWNyUOZNYqU32DwOmZwLhXGZkbNAZYXhvA+FAbgXQUoQAFjjIWpt+RizJOgFEUsMQy1xB7Ikvj

kQqxpNyBkTILba3lJOE2BshSsxFGgHKwt+RxIqAkiOfhJDRwdpqbU2BdSuyFh7c0lo9r2nIH7fhHoQ4+mluKeWhSJ6hiNOGBOM4WItCOANao39IBZ04DnLM+dUxFxLqgOSZkuhHHTlXBswRe4tjbPPBukcW79iXp3I03djo9OnAPcSXRRqlDHg0qeu4oSzw2eQxeg4V53gAqA7qLyCL0UirAn5y1IoIPPjvTSL994EJosMj+29L4fniMQ4S4L0J9

WAUCmFgFf7LQRR8xaf5ybLXmtigBf5xKBTBYS8Bf4VKJTJRfT5zhzgARaNCulGVQJD3imfd5tKcX+Xvq45KAF+WkLARtc6VCalhloUdJsjDtrMLQNdTZlz7qcJejwxe/DBGFH+pAQG6B0YaNUQACSaEYSQqjCDDBgNCbszgACqlp4jQi4Do+A2s8YE0oIYtYpYMlU1sl8A49MrFM3FCzNmvA+aQC5k47gc4/gcABJ4pJZtwnkklkE8U2IQnyzTf4

yJatxQxM1jKeJutEn6zNikiNGTvFSi1jk8teS7ZBiKUaJ2pSXb6gqQSKp1Ci11IQM6DpQcjSemIN6CQuA+h5IDPbEdcd9zxCrK4pILFlwTJTGMuxyKGCTLzAWHG8Rk5mQrPGZZNd7lHiVZARuPY+xt37Qc0cRy+4ziOHOL4blaark9OPVAgcdwz24HPR555nk8q+YfDeL8YNGT+aBR+iKSKAoBaC9K9FmWQdstpeKUCCXcqJf5eyWGiMhWWly4Fp

llpIfJYQ4jYVSMUoYzFAjVGbJRtarRwjzHyMNT/nRminGwDzjw2yyjaKcNsqY/Rvj+EWhYp47JqT8maXsacoyxT6mWPFWqoJkFDV8H6bEtShDrG4MxSM0pnC78wAHBkzhZFJQRrBQubNAT1meJH249preCCLh32E2WO+TmwDBewVvSFYWHM8Si2ZO+bnnM+bRfERLYW2MpbS1WBLgUrO+ajIFDLnzk6JQk8V3BXw1NoqAa1PTnn8LCYU01RlyW6X

3xaHlyTuD2URZU2xIr2HQtzkilF4bvXRsed86hRlnW6Wjda9h+bq0RUULlbtDu+0pX0JlWK+VqBFXsIegYLhr0NUjq1SUHVZQRHKCMAKI4zITpJDRoo5QuADhCGnAAJQADJfERK6mYEgPUGJuEYliUaID+r2EcZIDNrFhtsagVODjubOLscM9xibBYpp8YrPxEAAmS25NmuWkc82E4LdEjW2SORNtx1CataTeAM/Ng2un1tWm2wKfOxOjsSllO7e

7XtXsJVGl9kOhOgHg4TtDu45Qs6o68+l10+OjxNhnEuFGNxoy0yoATJugu0yj1RgGq46MkPawrIQGsg8Dys3bIfQOMXpRDm26jP3D9845pwt/eua5Rpp53JA/bo0p5wOXkg5vMrUeEJ3zjxFhBZN2oQSq584T9Kv4QVm5BmrgFJspfvqhO+tnnCouK6Fz8MeyM8E3rRJqSfl1NVL8nJqGfUtNUr6/RPlfa9NSi2TGL+EeAD8/on0fC2a+j5z1PiC

v9O9z7q750NKGl9opXzZcmze5/l8g+YnfDeD+J6L1viLqW58DbIyV5iBfPl57JtX3jA+owp/QlpyTvfIp57T9hgrPF390q14vxr6AEILmIAq4Lz69b76gQj4QH0QgHYbNQIEAqbw8CIFkakQoERaQE/5X554d6J62ZN4RZUpebBRmT/IRYHAIKP6yYmLMRfx14z5P7MHLbkqipMLrbWibZ0IMK7Y4wHZTwqrHZqrEC8IfTnYlC/TarCIVBQBIw8B

GqkBGAnRdBSJGCYAQiVaSBwDdhfbDAcBsBYxup6LxyEzeqkzlhAJQ5mJJDBqMyQ7hrM7lio6xpoAMFGgeJAis4U5E5Swk6yyhIKykgRJ9BUhRLqyxLs5yj06Vr8hM7GzxH1qlqNqc5GhKg86trqj87OxUzvrC6mii4ba1KOiS4B4AxNJToig2xNztIAaTyq5LqVgGhHDHptGG7ZzpI2G67G6PBDziTmL2Y2FW6Xoh7XodiO6tzO4lFdwvru4nJe6

BprqQ5XILo3LAbrITELwR4dyfLR4WYQKHFqTx6IbNYNRvzoYRbCat7UH0QAGQZRalhZ6wGX5P7YHIZsS4YRZpYgKubfGfGpT0RvGybCbgE4HAHHE3wPGYH3wgk0RF5D6b4QST68ZkwQQYG8aImYmyal7PF3GyR0E4RpbrB4FYlJ5DLwKp5sZkIngCFPqlAHTSqnQCEsJsLCEcKiHcLiFnYNFfTSFCJjoiLow+BfAcCSAgx9DowIxGBwAACabQSML

QxAXwAAjkcCYUDrjPohYWDvsJDtDq4g4QjkaM4UkZzI4jzKgC0DYd4WgF4gbH4Rmi0g3EEbmvjmEREYWuLjTjEVbHrF0skkjrWgbLTrEekaUJkfUW4h2oLonG7OKJUsUTwaUfUusWOlUWHIQIrvUSroyWrmgP0gMl+kuJjrrqKELL0Yet8AcC0HJOWCPheqsrXKHliFMbsgyZAG7kuosZ+mXJVn7v+nmaPLci2dsWHk8pHmRgcRFnvFCWFvObfLO

S/KibJmgUiavACcZjZLAvCehPZKuTRP5oecxIFDCWiQgpWGhmFLvpgQgqJtAZptefJiwcpggi0DiUeYyreRed+ewTxpwWtp2TyFtvwVwWyTehAPQpyU9GIRIejnyQIgKbIUKRUJUHWFIsyLgHKTwKormAjDwMoAaKqRQMyBwBwF9pqe6jqV6nqaTDQaYqTCusaRvpAGaR4ULDGlaZQeKHaagA6amh6emoEi6ViG6eTkJfmuEarNTtEakRzgGYyUG

akuaUpWbGGf6RWhkdztGbkZ2vkQmUaEmdUrMeLoOsOohY0rLj6B0Dmcro0fmUuv0gpguNUMPJ0durMiPHuluoXNWXYsWN+nNE2TbmOfXG2U3Dso+i7l2fMT2Z7n2V0JXFPH+hUSOZsXbuOaUOHjMcvLHtBsuehPOcnmfqnucfpJcShLfpBokBiYFhBD+bJkAShI1ThJcAhBuSUGuh1W/F3p1WFnXq1T5EXp+T5Lgs4NVWRglChK+cNBnmSaCe3hQ

aFueYtYFBQY1hQQgrxKQQQQtW1QQUNcPnnviYCTfFFn8T8VArNT5FApNbxnvKNSZohv1fSiRhhi9f+etKthdFtDFSBXwTtuBQqqwpBdBUdrBdyfBZqshZdnIRIF0KMLmESJUCPh0LmLWc4LgF9nsAgHsBwAANLjCA7UXmG0XExrCVTijQ5nAsVOFI4dTihcUIU/q8XY7JrJEwiSWE7OmBE5oSWhHKzSWRFFq+nyXhmKWghVrBms4aW5K1EtpWgxk

C5drxk9pFEmUpkDplEWXDllCZnuLaJc51H2WdKOUJxdBzSVb9Io5Jj7p64Mp22+V9HqjDw0EKZWIhW26gYO6RVO57LrTdnHIJXzhJWbCDlpVQWjlXrhWQA5V7L7FvKRS4JEkoRRavXf4/L3wnkVQVY/KhY7VnWATn48Q3Uob3yEFF1kxgGvUwHD452b6QH3VvlgF7nl3Ak/JPFt02QnXN1Cb0R92yT0Rl0/z0QN2TBpZj5F2QKwGp3kQV1HUQIV1

PVL0vzd1XwV2D3z0rkwJXHT2bxLn7173blXwH3j03wH0j2n1r13xoFz0QJoGrU4Qz3D5X0X0fEn3v2wGL0b1QL9W1VGRP3/5QL7U8TEKgPkS2ZILT3CbQOf1bywNqa0lh70n/VMnbYsnA37ag2HaqpQ28mBwXZFDw3oBfa+BtBNDdhCC4DoxCDQxfZ1hfbxDED4DxD6DEA/ZUVmGepExGihyNnU37BDJ002IqVoCBpuFWlwpCx8UCV46C3+K83BJ

k5Nx+FU5RElqWzy2c2JHpKy1+naPaX5K6XFJ5HlKFGeya37KlAS660OW6oG0EB2XZGWVhgFnxnORyTmIG5O0FzcB2S+NTL+WJzhTkzhQGjeWjHNkx2QV3rNz+3AVB1voVw0j9KrGpXpmXLR3jGx0bSTl7H5WnyLnPk/wjb2RZ2Mr50vxAMoaX0ArEE/0fgYqwG11PE1Ob6T1v3oonXr1NMnUr24onWNPoqT3DNkxPFjN10/yTP3zoE/KQHn3oqQm

kE71n7+Z3zP6H4oQDMfzP69NgDoFz6LOHOyTtNqQkkqRt4ok7MHOl7hZF3IEzVdMsTZ43Ml0kT2YbMQSfNn4D5BS/PZ5dN/6mRnPnUomLPAs7n7NU3kRNSb0L5GRb11SbxuTtT3wBY4HCbDztRpaxRvybwpxvyXnDMbo3lvxRaEvCocE/XiqmWMmgVA1rYQW4NcmnZ8JSFgAyFw2oUSCVBQxaFIw/BNBGrODdjKInRzSEA/ZGoE1cPA40W8MrBrB

rp+rKsfkiOI5iP64LKSMIVMoJpJo+Gc1qMfrYAGh80qNhLc0UjC3ek2Ni1aNxGBnS1aszSZIpGOsRmQBRm87K1mPpLq2WPAW2NS72P63WVToA7G1zouN63dI5wlQJg2nBWBOeVwreVVnFw4ylmpw/A+NjrVzRM5OxPtnRV0uxU9zxXvofltGuJuZQUZOuOB7ZNbG5Px0QbTlJ2J5dtF22b32TB579tQo9vwNuVz4UEXO30klvMBO50N515944HNV

iQQN1RfB16bBvwv02QVgUGGUcb7OePfP9XOT34/NF2HAZ40EUHnpVWgthYKbfOLMjRXvPsflPsTtnvPs6tVVvtfsTsknhQTvjVAfXH6u/s3ul6gcXuhQfP3sXB3M3Mw4Z6+SkELjZ79WWRJ7LhEsbtIvAI/AolDuIIbCp5dMgKj7DMj4LvHMVhz7EcsRd74cfwdHoQQvgdzu/PjXHqBb348dn5uQNUl6V7DPlil6idaTbMl4Z5vN0dSdn6zs2TQv

uVp0JYZ77O14D4aesUfgae1lCc4Gw4GdF20zP79VuXcervAIdYIRWddXX6ce9tyQISLNnCImucpsVSucqdee9WIl2dgAVh15wpvyec7kBfnCIn3uWTP7Re+7oTme20kTDNyR177MbBpftRHB3P96V4BfmLEF3xJf9QhabVn6M1CQwLEEBeW0vxdPJXkRdPHA33XEF2Hvp2HsEH7PhQvzMcibEFdOuLH31ZL3CaidjsXFn6eEWRNQfoolNRDIQQac

2foQBeXDP4pclRz59cqSl6XVOfzVdPnAUn7MVgne9V7c3MVjjUZi9XnekGsqFRvwkqyQRcCNiSYf7u4o3NDJ4l9cbDjVT2jvZcIR6eWdwv34adGdVW8ffJrObz7MccQJ9f9K9euYH2I8V2I9pYv5n4g+xboLEHKe4K4/T3nJo+J4gLVOd43EMeEfkGGe4vtQw5UEmcs8+RfXkKoPlsA3Mmyq/WCE4MckQ0nbqrsuIVENXZ6oQAQj0BNB7AQhJAdA

gzxDKDDDnIQgE17CVDYDDBHDOByvoC0LRCiWQBGKlnaC1llhucxjJxDyMXUxDJBqWKOGiMRrFjxAJAgIKZHDFiuJwpuLM2ihLgGs47Gvc1gjWDMDaiBAfTKPBFqO2uyWaNlpevuuGyuv6Pi2aXNpZFK16VxkFGJki5WM+zmWhtm0OMRthxCDONWg6pTCmHpgghcvm2PBu1LjzIZv23cD2bd/O3BOxRlwpzziROFuhUxOTF+3TEB3DhxXB3voLLlg

flutrFNtZMZU+2BnjhCBWgbRZCOCJqyXlESDVDYCVZJA4jLoLLECXsHD4wHB9Cw59DmKaCaC40sSoj9DEDxDYC1ncjMB3AOMWCNfAojrRsA4IOADDU5aCkAYIifANgD6DVBuwBoEIKogOCqJVEbAA4PoFVJsAkY9ARRIbzKD6ATelhWZHOG0BtF+kqWagW0XnC7oqYzUL4NoAYELIkqzUTgXik1Y1oy42gBTB+XQICCBBNhIPuklJZeF2aRrZ1vI

yVjoBI+HAaPrgFj7OJ4+7pBRpTiT4aM5aTrNSgkSRxus60bObPoY0jI6VfWBfVWkXyMol9g25fSOuOknRhx6AdfbgA32gBN9ZkLfRdD0hH6w4QEx6DynrguCVl7aLta0l0BoKDI4wXtMKiW2n4dl/qSTdUIsXNyWRfeEdTJulWDyttIKvIHfnv0QBEhPQCuKIif3QB7BcAPAXAAaF/hJB3+uAL4HjVxp9ABo8QGobgFwCRDqQPAPADUJ+Bzh8YAA

oAVORvjvgwBNwCAVqGgGt8peIiAAOIHBmA8w0gMoSSB1AYAfQRQfQARBRgjUpvDwVqRIFkC6KqATYCwOXB1laBsOd2g51KDQ5iw2gOSCVBNKlB2KsyNdFQMsgWcaQy4GLm6zEG8Bk42gVxKxSxyGt7SvhCPuQEUEx824FrBPta3Uai05KnrSWun10ZnCs+aIrSmYOMYWDTG+lcxsXw1p2CdaFfUdJUWr7uJFW3rSOLmTDbxtxGTKNdMv0hzll0kr

NI0JmxmTlhLgGwWKPmwBjj9varZW9KW1yrWMK2r6FIZ7gWRmQDQ6Tf3FkKjqb8xREoAoRUCKGH9ShKI8oe4mwCVClwKcaoJoHCjYhTR72Q0cQC6ALBsAFYBmJoD/4IAKwLQN/poGGEEBgBV4UAcg1KBTCoBHLWYSQwgAChoQFAPoBQFYbhR0YXQPoGaJ+w8AzQ9AfAE0F2Ak1uGoOCmqTBpBCx/UBkewi71eFsUkcu6QEZJ0kEQj+KUIjQf4UzSu

l+aqjJEVoJREp80i6IowZiLcRGCdBafH1i4z9ZEihcJIoNv9RDYODHG6Y6NkrljaMj3GZkEaOcmag64e+6oDJDyKPQGRayy4WHG4iiYT9i2U/e9DP0Sbz9kmRwBZOFGODeU1+etIPHELAySjE6BVIugfVOINZyqECRZiT2GZglfxUCRZqFkpIEl8IxYYKKFjODgSDynPOklwWAroMwKTLEGuyUDwiFIabLSQhL1hrEMeW6AO1GwDRD0BiAlQAmso

GYDxB4QjAJGEYCSA/YpEXwYgSDl1LZjqYNINxPmL4FFiwR7wl5kzUtIIUJB/MKQZCPD61ilGWacSk2NrHIifSqI1Ph2OUoRpuxoZAxroLpH4iBxlggyoGz7Rjj7BKoxwXLlwBGBXBKopkagHnBlxNgkQ9kauP1zriwhwTZdIuEDRlhKwsQyfr7WPGJCeeyQxOKkIGRzRFkmQ9ftkIfE7EnxhTB8O+J3KfjcUlVFDMFHvwQsk8QLKDvVRh4AtMpDz

OvH114kfM4W2eQqYwWPwJ4cpUCWbuUyyn4RRONxALoEIJ549lmRdE6sR23ZqQ2pszNqWATam2ZF2MDeiG1KeL/02mOWWAvVJOpAte6RXD+iNyvhDMZpRkNqd/n/rf5727zOqOtIur1TYGQLYhH1wamgToWj1F4q5GI4QTiOwmTdis0+oQlbpDzd6qVXunwNs6bU+yJRj9Fx1ueWtLpAy0wZITsGKE5VDBVF48lxehDbCXMIqAwB5h0II1OjQ6CjB

JAICI1NgCgDEBno0MPYHAEqCMSFW5AsvDxSND5jayGrU0gzUD78T+iofDmjINFjWtxJDYy1iETkGaCvSyfXsQpJdZKTsR8k3EepMVptpSgsZKwV92NC2C9J5IicdSM0DmtaiMbGOJXx5DuNk4O4jYMuKCH+MeijkrNq7ETaRC5kHkw8V5PiYnikhZ42UYvwGSxRSOKVZUaFNVE5DMqbbfJnlU7Yvj4GwXGKX+H6pezesiJEpqvGTqwZesYJSKFli

/yJQKmbKH5NtWI6fhtqr1eLpV39kk8AutEVZlXWTkQIumCcinlnKx5iZyI+zdEo1Kzktdp6Fc0dlXLmnOZ858DAun13TqLMce97Agv1QIJtSz4t9KOU1LCg9z4Mfc4fAPNhYRZB2/xD2bXLAA48J5w8iLBdVOkzd55rPeBhS0XmpR15JQYZunX6o48O51PIeRAnqkV16p21eqWnIynkR6pBdeqenXqk4975w3G0J9MAoC94Jf0/npdGQlg00JoM6

GkGNgG6oREIMOUk0HmEgwvgKML7Koi+ykAvsspDoNCAhBIw6wKQDMfKzJq0iIA5vKZjsGVbzgyZbwpHNnOjRUz1QkOWRjWNZl1iDhpOREdJJbGyS2xClfmRiOIW8z2xrC/sfn0JGF8xZxlMkWmQdmGSKgss+IKZIdnmSWIQyOcM5X75+N0ku6DcXGmy5tFwodZI2bkKPGmyfJP013BbP8lyjiya6G8Y2zvEttnZkFdtqMLXIjsp5b4wqnPPLmDyq

6CCRZqXI/G9ZcEfXN6pNyrpjdIoBdV6gXXvbTZ/8ZTMBhEsgZRKc5gSurkXNiVeL4l/szOZ7NSVTyT5r+FORexfj9UC650l+B9JWzfSpRvPDBp/L2xCFUJIMuCgQy3CS8QxBwIimaDBCJjAgZoOEHGBgDdKfsUAThugu1KYKCZriPMcqySqEKSxWretoCK5FCSqxcjemWJJEoIj1B1CmSfazkmcKABiklwhwpYW58TG7aFWtpIsa6See44gyQbVl

k8AJFcbFWSPjdrhR5FXRROM8oPS6zS4F4xZL70xz7jRRWVcUQkLLZ6LpRCxIxUPxtIhTzFaogFXk12JuyHqdi3zGgTiklB/uuSrJUfISnI9N5BzALk8Rua/FiOvxe9r8QC5kqYJKDOCWgw/mslv5LLdCWL0wkQyYBKFOARUEkBWATo8QAmsrx+zvZ6AXwMwMQFGAUAjUbQTGAMogBMTyafDNYDaUYFjLne8ObicQrLFkKgRNM6QXoMWXULGZYlRs

VawYXsztBqktPp2PYWc1OZXC8wZpN4WiydJyZUpRcuEVXLfetyucfuDcpwpKsLkzWZyKCHhDFwJYc5BmEsiaLLF2iqKpKMDoGKPcVs2spcF3S3iw294zyROXhWwRd4SKtFA4tfFw9nFrkQOa1GDmgQxmxBeOQXXcWNyYlV8EuenTGZPF45k9ZtZhlrVQo4lLTRcil2anwMbi+zdOij3rlTycek2F+TSz+o88EJjLAXsy2F54MMJCFFlcGNwkQA7U

Z0MmL9gQAdA6JUiYgPQDgDxAzQcADoB0DlJ4yhlpw5wHODdb5ilwEy24KWN1aigKFwk6saJL1XLK1BAtNZYwo2XMKJarCi1Vq2UnqUzV6I7hULMgAiyTlI4s5SCulX6TXVMsxZB6qVnmTj0kQkfum39VeVA1TkwNBbjLgZCawIo8KVsiBUxq5+lbBfgaAWTrt1uUK1NRYq37ZVXZWaw+DmufGjzC1pTR8i4vgYeKl5VdXBLnNsw+LhMJcsrlXVsw

3N1glTfjfJjMyAJlNp9Rcm9PCVPSr53sm+BC2SWVyeIB0mufll7UZKX4onQaTpoOa+z7i85cErxrUjuLZmucsArnMgJubh6lK7KiUt4J886VgMn+TUvwbgz6lkMkMaqRaBGADCXQTQBwDlJSJCA7AeYcwCMA/Y7USMfAJRSlUyqsFRiDrDYQ4ldAH1PE59a7S1UiS6ZXNJZcTm/VSTf1Jq1sdau2XczdlVq8DTao0k8Kjl/rNWqcqdVl8pZlylDQ

cDQ2UiBA7jOsnOErADQyydkgBtyJ1kzISw63FiCMTI3pqIq3k4FaUr8nxq6NcYD9MFLtlDlmNMKl2Zmu43RTHFRxa7ScS023ggWvcgzTVKs2F0XpB857YkoemGbUVW8MdcUupVTraVWDKpcDJF61KQt/JVldy3ZUSAhAQgOsJUC6CEAKAGweGTUA4A/YIQmgJIATVzD4AL1PDAmXWUVWkw3IcOENPTS1bNMLSaObgI9zmVh9KtTpL9RJMNUsyCcN

rBrUwqa2s4uxeywDQcoJHdahxvWuDf1tTLlC9aIiiQLLIYnyyZxissbcrKcoGR4wMYDRamz1zTcRki2nGCxHQLhRMNvy9bcbIo1baqNcxGjeePo2LhNdgeMxadqdmsa467Gy7UHJSWTypstBYtVvFLVOLBNxCD6kWtDlVSq6oWHxWljGYEFQl7Um+LnMOkQI5Nie+aT8gPpjMce5a8zf7ogRjMF6i5N5sOpM2l1ft5YUvWtwxU3SXtVe4qNismA7

cKpNeu7b2y42QZS8rnIqU3o/A9q2Ov2z8DcyTz2b4Gg+vTcxEe0CQrNxiSfepHu24p1pc+f+ghAs3oRoWCEeffJ0+1/gjNXulLGHve1+Lh9gqTFUQjr3x7T9f2qCTxBuYNrZ5P8Yjq1JHl36qSXa8rm2oE5v6BpL+z/cPm3jjqfNNCQGv9NnX0r51rLJlUutC3Q6cJsO9AEYHEjoxqgBNNoC0AhDxAot9AKRHahBjYB4gqpZkG0EJ1Zi5VpMJlAa

XwVFauJVOmtOqrp3pIMklCj9Zzv1W3pJJRq+rTJVNUmC1JbCkDQLpz4K08+UGiADBuJE2DSRksoRdLrdUtBRtPglRcei/Q2k3lDtByQPw+VnCYwvvTTibutz/LcmcTaNbPyt0yjDFVs6MCWSY1Ky01ZutjRdqike7N9sKPvdFzKogSd2t+pyI/r/DQsk8bzcauNwQi9SeqCnNfZfPC5hGfZELdvEC3bwHSW8cR0HugkSNrNkj09RvH1z474rjODc

uqtcW+bH6PwFekqY4b92z6P485ALii3nLkcV5U82zIN1qP5Z6jlUs4qVNaMPNYGCLAPVPJp18bMIf+wHQhunVAGv5AWhlX/LqVQ6V1MBiAPQxWHcqEARqTQHakWRtA9gP2eYbROqAdAst4oXRBgqJ1XqWRDvelOJGK1I4JGfE2g/rlfXzKqFnOp/i0DNYalatbBh43+vpAOs+ZzW/QdTr4OmCBZghnIvatg1iHRx5ypDVIZQ3zDZDbjfcJVlrznA

GYuGyFrrrUNLbFwMOAyM51I26HyNm2nRdttjXW7LZ+2oeFGFX6O6rDLG9UdYoKbuyimZR4un3ryVlSXpAcqbmyZ6Mk8rmsBLLnvqnkTclNpBKteBNQTEcv09kerqFnizzyZTizS4w1h8wDGgKNKwAxUsF5AzR4v8iHcysgPTGgFFQdGH0EwCg19AIMSQLmGWExhlAAoOUsoDlJI7CDzE4g9TEUMnGhknvSg272ZxgjARvRyAAweZ1IjTWcstnczI

pwKClBKgjme1p+OM4ZabWrg32NtVdbhZxy0Q6UAEUSGpdYbGXegFllmhYTTRHpLTCXBXAwuaJhRbMm1nomj0sUC8UuFcSW5TdWik2YYdPEknTD+2uttGEsPK7rDbZjNZFIZNXaSjDHVvWRm44UEuTvmT/CkeykvSB8VHYLve1wWwpjm7eTcwhGeZbneTjnYfe3jXPt4GOpeAfYDwW4Cnl8edSngpoea4IqOJPBjiT36qPN56xU982fk7lfMGe3+l

Ta/pjlXUD9I69ankY55d7Auv2/LgWv33dHi9cFlU2/LVN+aQdQvapeDuC16mpjgC67ByqkR1hOgFgUgPQE0D6BRgcpaECr2GAUB9AzAXAM6dlVKs0AFYIrYzDaLLpyYltebfcLWDHAWBrRd2nNAFGKdJlEaTihqpjD8Dvca6Nzp319Tlb31wZ6rQEVeMc75CMI6M/CM4M4j4zGfHmUmZ0sCHDl6ZnrdYKzMSyITg25DU4IgCyzZWCuhkehvcaxQa

CM4JlLWerMp6fKRuYJoGiTVuRw6uJsYkOYJMdnzZXZvbReMw2W1KT9s6Fc7tpNu77D68W7XeH4FzRh+5MdosnHMQ2aeIrA5dCnFLAKZa8/IqAvmqMinB+RHWVWSpCiFdMD6nvDiwaCjBlxxIvvRZIuRYGFWSwI0ZqL70SCH00lPEIrZVmy5XjLatMF9oszQJ0xk4qWNyPlq/QG67N9hT9M5BjDWTjuspiq/XSkvxgZLW1hcVpkQu0shjwOgGaDu1

NBbF1MwnC9L0IBHBiAQgUYG0CSBQBFE0MGAAcCRjMATozgOUhgeUD2W9jngxDZepYkVgg01tZcL/EOBXjpqxM3iwMgSBroSozUBTBZ0xzvDl09MRILTHMRLjnKpWxOHECHiBolwblSsAVwq6M7aZOqqrZ+pq3hn6FrMqM3CLj6Na4zfOy1ZVt53G1BZwJkXXwsdWl9JddjJWfmdstHB+l04xy8row0bBEgbkGkLNt8qiglFeu+nVGFXSw41teJjb

YCot1GHn0EV1IU8ErBuIU11Js7VYqSujmHDw1kiCcA6wlQzu/vNRblY3jpW3bNBD23CktokkXbGV929lZoLQIz8BVw4L1ZKsdWYWO5KO0Vb6ulWYw2LHAlVbhQ1XwodVuG3Pm0BCWLgH5SrCAmXAJhTu2gdAstvLAJgYcgaezHnYLsZg5wtMbLvGBWjUF+BNBecFoY/JXAbuGdjMG5LOADI4bSUqq8PAvG15P+C4Ps5pArs2lcr5wBMHGA/JvMmr

Co+gW1drxJwUS89qu0vdrur34Endim5ZAGhmQAeFzPe4vZrsr2PyJefO3WQzApw1ddQ2Dju2vuXAD7d9mdnjfMTiRiwAgubnPcrs33l7JUe+wpz/sE3AH6BYB2JAHtZ3h79VwLNA4AdE34Hm+fO5VkLvN2S7bd6FnsDQeE2gHJJT3guGjvFX+r4ka7qg5t4wOMHQdn25lf9vh3/6dMC3M5ECmBoNdsytSNg7khN3i741tdMffJsv2qbF9yyGlnsK

gOv7t9+cG1Dx4V3yzCYb9H0kOC4sqB2XEsCpCGQLgvl+zCgxZ0nu7jtcs9mKNo/J16P5wM4eja5mwcsPsrNdwKJ3ZHwMahByt0ng3Lcfd3xIvd0sBVlYG157MbQticWHKs+ODQ1jn5QY/o2MpHHodmcMulQ4XtUb67RR1DcntlwEnIdv2849Sd9r0ncYecFk5LA5O2UiT/J8k5rteavpgx0pcMY1Nzr0LC68A3dbZWGmJAqpdGKogQAQgzQRqH7K

MEwAUUjUuYPoGaE0AtAYAdqfQAxdy30771qWS2hcCSorOnlJx44C0AKvDxP+CYAaBU/JlTKqnWVmp4o5JupYpLv8Ba9lxpuO1KxTOhmyzuZtMzWbBOdm8oK0tc3kzXM34/pb5vc2BbQJvnCCczOQBszllyQ3mbdVSJizbfFIaGstoxhbJ6t9MG62UUBtOLGYYsWUFbORr2zCTcKyYciugjl0Qpy5FSYHM0nYVdJhFbYp310pg7vts557faqMvf8i

dmO9Q9Tsp1mHSTtojDktoAoBHuD4Rw6O2pcuqHpVuFJE6nnrBEHQ9nO+5PysUOk7sdsqz4tkcL35H4D1e/RFFdCOW7pd9uzJs/vV29X77Sq5ZEztKuR7V5UOcU8ycDRsnUDRV7Vfte5yiH5YDJ6U5dflPbM2r/ewo+9yBKrHuj2J3Y5iE+QnXfr44KnHORhvonEb/R1G4pbhvNDqbwx2G6HjuOe7TKQJ649zd+PPHgTnN13Y8cBORLrUYJwMmTjD

Fdb1a3x5W4LfVvp5pz/2/DfTksDowdbsJ6unJdjdx7ICEsGY5nuhKe3IT+t8GvLCDvClKjzYGo9Th9JayE72t6E4bezuLgNxOIHRrLj9IDrfSMveNnXfTu2Ji7nE1fOCdqPuHNBAK/WtPf9ut3l7r8Y/dphDwlwc4OGw+97cbuZ3F7m4kGk4txhJrk9y2o2sfebuAPwBKgT6+jDHoyrdZXOZO77dQe53V+65/ZmI0mLLIDkXrEGmLctu+7MHr91h

9273Pc5QaZN5m9seGOSP0YMj3c4B54f/Fsbr9P6/QLEEdnpH25zh7TjpRzX39iBzj248MfePFH5Ou6+zuev6PNz7DxJ+gKGui7xr0JrJ8Y98eWPgm8hz1eldaHruan8T8x9znMunHyTthwZ/k9GeC9mHwz7h4av8vqnbL5ejZ8s92fvbrt0z054s/kerPVLAChOu4KNOLrwBsY6AcZVgysLSFKA1DIkAnQLUrCYgKqSECSB0YqpOsIQAQBCA+lcA

AUAgDtaN8jhOW8gTDk96LJzEMYEBAdoVVbPEg6T9dns4NBfpsbxCqV8nbjuiCNVi4VgSXYmsXA5IHWN1kGeecMzWdbz1ZR840sc3VBPzwyzo15sM3+bRjQW6C+FsOq+tYt7WtC8lturcw8L8bfuEvGB3lwatzy5rbrPa2Zt4dnQ8FYJfm7CTlu02yS/Ns8v+zQGBK7S/tuIqOXDttKx54Fc5WI7u1iBK141eyu+ue8KT8g9HuzkHPrLgOyNHsiCe

Q3Sj18bD/9vFgEflTvJ3D67fufsf6PwO/O/JiLvT24kVLD8HB9o/srGP1uSfYkfn2abNzEz/95p8rk33z9z9wx9NeeyqfyT1n7FgSCUO2vjMIa/Yt59tF+f5EHZ20WO+f9EPJCVH398c/w+RPLnnz255h9K+4fkv3Pd15Ecpw+v01u+CD+oe1tzNevh0Qb6msDfjfar7l6VbN8jWLfvX6385DqevyzrQX9U/5qutQUdTmFiA9hc6e4WJAAoeYcyG

ZB2pqgowaoFIjaBQBVEmgRcDLdVJGojgRqBZ8V4NAJAlwlwujXxdtlI36Kx6Pe0PFqE2lfVPplxMO9MfT2owGSf00Q5wdGuevc4W4086lqyCmDo3g1RGehFR8pvsZ350Bp2VCGexQLpbyC8HEi31vgi3M9t5Q1ECHLptBWxNsw1xg2huGuTgtvO/qhrC1/Tf0FaLYhWjb93k2/orNtyjEg5MI55S7itO78Truuwz94Ih4+WXrD3K5OaxIm+Hf8dx

2z0aU88HERyTxmfZXzYd2oSH2VcM8UALh9wA0giR9LXJhy18P/QHyKcfXEp3Y943TjwggYAlALyUM3Gxzido3RkyLoqPHRxo8iAqLFwDnHC8Sa5m3fN2I9D4cX2XRaA8CXoD/HVtxJ4f/Aa3Eg+uAjwrcGAwt1gJAA8V1CY2Awj0EC23CxGqs7XezDLA6AiQI4DGA1yAQDa7UNw7tFA0tzbdvXHcWdd43QB3ECBApQKEDLHaj0IC03NgLMDI3Ojz

Ch2A0t3OFLA8gPMCbA/CBQ8/3c92y4KCNjzKdsAstRr9R3OvzSh4AuRwtdD7K13IgTgYnxSd1HVLFXc34VQJ/tclQX1rxN7LDg6tyOSAJk8eIdexSDWrNIJAQMgm10HsPXeq2qZtHc5HLhD3VLGPcHmEQJU9uqf/HKD93OMA2tqg45jqCevBoKEg6fSmwZ8Cbb8UyDSgxoPEdeg6m36D4gkIKE99XYYJctRgi+xocvA9AL0DXXMoJGCz7MYIWCNA

owK0CSeMm1mD1g+YJn0i6NwLPdXECJxvlr3Lh0rAeHe9wcd8fApxuJ7CEaHfcX7Uj3OAUeDtweC6uYh1gdnKO4Pf8vgwzRUd6NUDxDVssMeX8Cp7BQ3r816QX3VdqHQazblIQsdxhCMPGX3nA5fWVyCCWpZEMCDtqUa06Crffrzd8IQs+xHcoQ8xx6lH7K4QvEh4f4QfIcQskNr9oQixx/gvTCsGXRzDeMAzBzkIx1xCWQsAjmsyPc5CrBlrUX18

wdne4JqchRNSCFCFrEULDoVrH4k+DpQsEnsJa2FODkCP0MkK/hIPGd3OCx6WD0iFIhFgLas07UgLsCq3BZn2sNrWS22t72MgJics3eJ1gI1raS02tFwe0McCnQ2jxdC9rda0OtPQ463d8Avd+W99ULLUz98brdpwAVg/aXghBoYSoGZB6APoGYZcwEGDgAhAcP2cAcwpoDrBSwTP1OFnIHZ3/s5wAa0SBP3Grx2cOLCe2eFE2XdHeFjHCewCCBQk

m0ksAwj0LksiZOm21VO/XVW79XnXv3ed1LAfy+dObHnQn8GbfnQMtvjIy2F0TLUXTMsIXCywQ0XVKExstZZAg2X9ZxJy33BC7Nyg5Ct/DyyCZ1DRcGKth4NqwjUXdWywlFz/UFSrY6NK4AXBYrE7Rtt3vc7RHMvvEgKdsHwZgKFdjPZgPM8mA5AJoDhXf2W4CaHHzl/CQImp1YDwIu3109IIrgIQjhfMHxFdG7ZTxLsP3Ygggi0IrxUGDc7YQIwi

gAk1xLkg3MBzCDJ6DoNbsy7eKG8D/XMsGXQDXYiPFcCHOiKWC43WgOPRYGAiIddw9S0M4CoEXiOQ89Q893Q8VAyYOR9c5SUIBDznBrge16I/QMTdesJsPJCUQ1kNmhFIi8QMCVI/kMpDXHKwOdC4wcORVDBXC51sDNAq0JGxRIgd23ci3bYKsj8PASOUDioGyPLBPApyMMjbHBD0k03I3biTcnAyNx8jcnWSMFdBkAT0kjEAwVD0jx3STyKCkHKA

KJ9VHUnxXcmsfCPijZAwiPnpkglqzdt2rAoPQjm/TCOy5sIsoL3dKg1oPKdCowR2KitxEPhmDT7SR0Z8fkCCN5dQUS4Lqs5oO91LIWolCI1c2oniCeCn7bCNI9ufeV208hffqP09S6H4MYdeonT2F8BoySGBCQPEIRDUGNeaMmieXaaOLk4Q+3wGslQrOVaidopPVg9ZfBD1lckPTaPhCU7E6KvhRPOT3V9+PRTxYjjXUqKd8xrS30mtiQ9xTiBX

orCJftBpakMuBaQp5Sa8S5aQNtcSgrKLZD6YOQK5DC7XkIiidXUIMSDYCOIBLsImTR3CZz2QTXIjdXSiPog5QsuAVCxQ0JR0DfXTAK4imI8aQSBhQpa1ZFyYrSK4saYvaw1CTQmHDasv0dOUdCU3byLhQ1Qm0MDCuw0JX4C83YwLbd2w90LtDgwk91/dTg590FiOwmWN9RrI+WKfdoPV0KNDNQ00P+Fu3PyPEif4YmMWtRQxmLVip3DWMNi1IDGN

UVfebGLqtXqGSM89OQ+SI6lgYuxzpDfuBkME0nY/7ytoG1Z3xYtDfG316xfY5X39jzfT6Jd8fokMP/1JUcMMus0LMHTacIvQPyi8DTEP3QB8QDRGIBqgWGWhAToSi27BelYYD6B5hVUmIBjCbLXxkiwmgn4F6/OaF/hahEhVsJi/OmEVEEwG5wUMGKHgWZxxLa4zhQOo29xjBSyBSwWVGbAcJUsWbcbxHDYRMcOm8Jw4f10tpwwFyXi5wu1VW9QT

cy3EMoXef2V0pbWWV2MjGBWUjopFbUPJtOLFEwxctbZiym1h+W9gLYDbGw1P8wrXyTjVnvPZxsJrbal1ttHxBOmStX/VKwIg/wuCKB9+Hf6OACKjYSPnJ8Y1GMUcGrAyMCijI/ZgR4/IjyLASt5GKPr91NBd2iDl3WILSiMEvzCaCKo1kRZFFyPYMai+g6R0XIOHUsCuCuokeJw4gEweM4dOom4J6i/Pb6jjjfpBOJC9ffcGhTj/5LCWi8QxG1Gh

hoQAmiEB6AJKhgAzQfQDYB1AGQCqFiAGdGriIbV0wOd64/+0GJcrfHiL9qYYYlg9W7AaAMgi7NxBxsiHeh3QdSHNsOoiJXMePuMJYHvxYN2dSM0m954of1m9KtFeIW9JwwE2MtoNDM2HEwTeDWdVITGFxQ1mQPbxV0E4WvDnAkqOsnQ4tdCsnw11DX+GXdPTFsyfiT/G8Mo07wiAF20P4z9Fe8Nid8Lttn/L8LHMefGCIl9Cfb72/8+o03z/8UrX

tgSC67e+HOkCA6wL9DqkqeROCn3A0IaTZMMOJx8ZQ1pPgZVI5kP0jhk5+kiDkomII6x9OWZOyCco1IPasd7FZO6Dyog91aDjjLZIgRKE+nzGDpHL/1kxWE+hPYS73J+zOTn6OhJvdrg65L4dfvKUMFdQEl6SGiXgznzftQsagNgiwI6ek+SOfV+3Ch37K+Agja2Oh02B/7EhzgcceCFO7wYGWaNsSiIoqJIixAqB2sTYU4m1RSao9FNEcuErngad

fNcpR98k466wwtbrWMJh0undADNAmgLGjlIKAGABaBoQaGE0BVSRRFURXgKRJ4BVSJoELCWJLqPzs0bJKnNwrxdiV4tywYJ2VsywVOCGRiuUS2ZxIY4oOk8hg2nXcJkcLBI0jwRDv3T4XnKeLG8f1Cb1HCYzbS1nC5vXgxnCtldeLTMgk0y34UVw8JKst1wuXFlkkYGJMVsR8K2g2ATvF5W4sqzE8N5FLEG4RVsrw9UQMMiXN+Mv9F+RIC/RWOB3

Xv83wx/zhVPwhl2/D7FF+FwjeAt/2digI4fHsSMUxX1eSAfWBGgTNfEtPzSFIjiKpiE3N5mOioI+vW6TkE23wWipoxtLRVnI23g057E96PkxTIwq3NDh9XtMBi/ApkJbDKQiAIyjoYlVxqltU+9hVSEorILnTx0ikNijCU2CVVMgdPhNGMBE/3ypSREjOOl4hADoCRgEAAmhxoCaJGHRg2gUcGUAmgIQDtQ+gB6FWB1Ew4yFSFMEVIxDMTbd0xx/

UOQOwd2BZfjOAcU45zEtmAnX1IVrjKWMPcVY7sMDM31ceINT6xIcJniJAT5zNSZvC1J8T5vPsOMFvEvEWW9p/Nb3F0NvMyhdTIkjcKOA7UT1PcZveSsHWdUXaszfM84Xf14ABkC8WfChuI/wPFckyNLNlo0p7yv84HBNLv9Xwn+PKS/4jtiqT//ZFTeQQEgFJ/DwUppN/9hmNAkLSCUohMXTZA5yQQTEMdpPUCiE3mIoCLA3rD+S6kzH1cC3I84M

ihzMlX2ijV09SNCU7MyDOhISE3ZLISagwTRcz6kq9zYTh424LMyIM3zJzlkUuFNszgsyzOR4VovNnJDwPCLNqT7MtELg9MQ8SGxDvMyLMz1A4okKN8gsxLNcyDmE4BGgaQ85DBiDwhLJLSCs5qCeFbYuSFrJwmNyB8UfMqLNlC6Y+UIZiUgprMyzDQ9mK1CzQ9OWazJ6N0NgyjrVWLyzKskLMc0hYzsK9CN0qlS3TzrHdMqVyUqMMpSYww9PusRE

YYD2A5SAmjlJMAE6FZBmAfQGhB6ADoGcA+gSoGEA7Uc9TfSiDJi21ZPeCoPLC5oP4VVZi/asLMhawq2iWSq/CrVKB/TY2NJjGYxxMYNnEwcNcS+/DQQwzvnReIIy8M3xLwzFvQjKn8tJcF3Fkd41cIiSF/KjJBhaMpdGPQl7YgNYzPLJjKDScYJew4FKwMfhyTbvUKyjSENIpOEyBiL+Kpc3vFNLpcONU+FuTONYCJLT/wxcmzS5XOTNsCvIygPn

IBkqD3QSlMm+ByDcore3SCKE9zJaDWRKqJYT7khhI4TmEohKucePVz2eiiE2vHdjQY+kJQTMMOGM5D3HRGLGxDcm2JUg7Y+rIdi7NIHI6zxQ3NSJi2skmNdyTrAHQWyvfFC0TjIwwRLANU4jpxpTM44Q3oAOANoHoBcAO1A6BMAeYSaAzQL4GLjlAaGDrBEAaoEFTNEo0meytcV7OWsTjKsHsJcxEqB0d+kSyCoMXCXd1pDSE/qy6CAcjVRkZEMp

xOEoIc2y1YM1LdDI8TMMuHOwypw3DPT5kcgJPnD7UxcMdTMc51K2994t1QFB8c0swUwjdUFJRNlDcIXKduItyD3F8Xa8P4zdFHbXfjmcmkAyRv49nMNtU0/+Jf9iOOzKrTZMlLAbSU6JqBHT6ojNN8xYEqYPCC+kuc2bT+Yl9zvzPkSXP/crYiZJHUB0iOIOTT6XBKXcyfBJN+SYENZLyD2rayR5ztkuvI8yG8n3TWZlcw90RNMC/o19ykLbdIDz

+ElbODzwvYROXVNsn0D6AhARREBt9ARRHwB4tCEDYA+gGVnwBJAM0DrBoYHPIez7MYO1MTLaezHXYVuAxImppU+DxRdFwUzkVTH1LVkGzLnaXxSyLotLPoNW8sHPbzDU1DONTZ4zS3HD/1EfJ4MAXPxLXjgXQJOENgksXVCSJdTbz3irKKjIFTtwpXTkN1QUNX/th4MnLTZ62TFzVoLcC/mu9j/OnJfiGcg/JjTHw4nx65jtSOkHMgii/Okz00r/

Pdy+c0KJYDFMzNNVc20hEJzSgEv6LRTRAzTJlzEEctKIT38qSOqNmYnSKMyu0hwKATACjwPcUFCsdJMcJ09dKrpGiiIKgKUoghOczushqOOSpHW7nGyUigrIuSHkxhMCy2i3osgZ2fEaK58S5doogRurLaJldDojLPyzJsm+CULzogPlUKKs4Yo2Kt4LYu/SdikfB9zqWHhPpYlszU0C01s0POpToDWlIgAQYL7CkQ5Ed60wpnAeYS+AQYFoG3UU

BbAGcAPUu7JdM+CuMFOBfUJ5SSoQEXBVbjDEq5xrCQEOsN+ze4x4COS5gxn0uchc3dCG88M5DNoUu89xNNTYcgwv8SjC1rVXj4ciAEg0hbBcJn9SMufwltZ8lDVuy5bFfxcLE4M9CkKUTTwr8pTwlSBhxYcVyXDTYVPfKJNqNITNjTOLfKTEzoimlw/DL8mTJALkVQCM/8ICm+AfyUCuqGEjNSyYFKKootUrswf8hcGCiDSuotsi/8pUrRRRkzt3

MjX8lLHmSSfRZIp8dS2XIQK8oxExaTgExLIFysCnZJVyMC+TO9L3kjJTRKDgjEuSLnYn0rSMegsMsvss0lTJ4DhclLFDKmouMoyLlixMv+1zi4lIANiC3dNIL909bMoK4wkRA0JRgBAzNBCATAFUQ+gNoAMBFEL7FVJcwGoHoARtYEsYszeXvkHj0hVLDasSvQvx4t6KRZHnsgqNiV/gWMpVN74u0xErsSIEhxLZo7jDQsUYXEzvLcT+/OeL7ySS

0wpwyrUikoHzR8jeNpKSM6wrIybGbHKZKqMyVVZKdw1f33Bt7YeH94/UtNlUMfLdJIl90CYsACLeM2ItFKHvC/wlLHw6EqrBSk5tl/iIpBUoSL/8qPCmLEiz5FyK8U/IrwLR2QYN940sOzKjL4GPUtrtD/U+AUyumCmIwCfA2/1Xg8K70L5jKAwMv5zgy7/MsiC3GcojK/Y6irRQxYktwCd6K8iCxLDA8WNLd2Kn+A0yHQ6cpI0C0ucqLTKIU60n

VFsvMuWyg8wsruKNsksoqBRgHgAoBcAaECgBuweYQJpoYeYVzAmgEGGGA2gOhjYA5SPHPbLFnDwmBFyTAu1+FPQ4vOWczkdWQGRyzGwneFrS5x1tKm8643QraA0HKUsmbLQshzhwnvKJL9Cz402V9lHm13KTCykupKVvI8q3jlwqfIG0Z8+wrdSjgeiycLT49xlTh41D8h5KiwNJN5FGzKbUFFhS/Q1vDOzACqisQEY4CVFxMs/Ofi4imxWzUDSm

/NVK7S4rA1KDS+CrFc3o0dI6rIMbTJnThMYjiwq0YgarIxjM8wJNKJq3jBYqiPEwNgrHiA2LsiDStyrkiqA/4MjKPKkiqDK0iiULAKdql5JSKMKiaHErAvElMQkSCmSujC5K4svDzpedGEIBoYXMAFAWgKRDNAOgS1EVJnAI1D6BoYOAB4BNAFwTMrivUmRKtqg8mFH4Jy2EqigdnT8uchnIa2i4s/sms1OAsAhN2LJtcEm1pptnRrx9V0CdomxL

1CvyoeNQzF42nidC4Ko3LiSsKoA1+DS1JrR/jbg1iriMhKoxzwTLHIoycctKo60T4syXuU8q4sD9tcNMER8KBY1Jirzskm713yKq4lzBVY01NxfDZSsCuHMIKlqtmrzkhFPHlriZmN8DNaxzC7S23LuU6KnSyIXjLMimV2yLp6IDzLzQQqGqEqLIAzJR9h9F3NNjOsxBJ9Dxc8fFOB+4JlEuBT0c5BfzAEedLRZWBPRzjSMnH7O2ogU2Yu/d2oew

hkDoYmS2+CsU34I/R2oKj3JhnIFVnqsKxU6L1ynozT0FMCPZu3lEowNynq8VqIrI/IQY0rNNz2oHt2O43KZyldEU4e4hqz7curLpC63RuvDqL7Wsm1D6sk6mGzbQ0bJ2tR2JuoHrW64euBJfatywD4FxVoh+4p6oYhnqP3KBBOBYcM7moEOsZyD4jJ6/urXqh6jeqWl+BBTChtlwGyVCccWS3g6s6yRsyCkP0RBl9rjgRZC8ZIhKK3I4dna8Q/QR

3S2nXZn6u6nPrKscusqxYoSulHYf6++v/qn60QrqgKDDGuLAsawhKga7673lgbAG+Bt1Ld3DYFdFf4T8qvFvxRBrA9kGiBuSTXIDhxK9tnDkIp92oEhpDUyGme2zp7CPGrjACaplBnB/uBhvJgmG7GsQxWGw7XYahkQmq4bY4nMvjipK64vGNdTNOIaVV1OUlGAmgCiWwA1jSoBmciaVRHmFcAFoFwApEPYAz9QaosNThLeVW3MRQG2KElNBGJih

HwK7WvGW0SvWHEdrJy1wuyzvoqsGWSNUq0iGq1UmGIQzFy0moiRyalZSpr5BXvNprpVL4xtTGa302ZqUzTrSEMRDEJO3jOa6fLsKZcKjIOE2kNkrhNfBFgJtdicwNM8oYa8Wv6tTEv/Lxdac2WvyTKqhWsAqH65NTZyykjnM+9IKy0v2IVS9lwNr0ym6Pa8XSg5n4r+msauE9+mgiuWCA3fpvmrJAvl0Sy4AounWrBXcZK9LK0r21JDmitdNRDcK

2ZtWb96U2vwTYCi2ozKkI4+z9Kqg/ZI4qEy45qwK1g1MtOSem/aKubp6DXKuTeHZCMtq9PIdIyUrE6FIYcUU4SryLjXNiKm4Ys+2qSpnGj+HsSgW6eiWLemrXGYiAW/B1oiz8I4vg8TijSIha5yqFpekHo9Two94WhCsBakWsnjcbDfSISojMWolpekCQ/X3cayWoSOnTfGg+oyVqWr6NJbPGrUoZaofJlufkCCz30uqZ1fMpurbiigv1MqCiQFG

A9gM0DlJNAIQGrLHsfQGj9MvSoC6E6wPoFsojGoVLzziNAvKa9G8vBRsaWBfqwca2iJxu8oeJN2sVD/7RQrOjji+X3b96bXEpDMnjMMyNS6tE1JprQqyJvCrBdSKqZrrUiKrMKx8iwodTRbBkopFUq0RSOBdRY+MV0sqpdFcRLafwUE4UklIUKqj0OVJqsRoL8r0N4hY21qaHwqK2sl7EKIpVEYi68M5z3ddpoAS2q1APSKLm95seaaklZq6aOWp

OsZb7PbZpbbNImtLKdGIoFi6rLHWir7sn8ucr7SH6PZpgK6G4IJRiP8nHm+b8bGxMJq3KMipMyZqxYr2jEIuNK2q/Yo6sOKbW1FrtaxHfYNubabe6P3bUsj8qBYcW2zzThVg49uoTBih5jtysYx3LrdEoFaoV9Xaz3JNjLW55MC52ko+0p5v24HOag/2nqpb8aIsaOvNgOjrKtbcU3qsRaoO86rDCpGlp2TiQ8kVqD8HqkRCgA5SXMFhlsAKRH0A

kgM9JOg846oAhBeQRMKnEjQfYyN5SBZQAOFQ4Q4DWsW6n4BxcFkCpqpgjSNOBScWREZWa8tWSuvnsMfOt0Hg6rNsJRtRQrgRk7uBR5wdb9U9cr0KF47QrdbdCwf3NTomncr9a9yrTpRzzCpJqsKUmsJOSr0mjMhQ0aia8ucLcm9vl95ayBshXE0XLyhfLycx4AuAfgLK3jQeMnNqjUQi4kyqq0hXitHgmm0Cskz9YTUQkBtREoWP4LKaVWqAFgRZ

Ca9sATQBi0nrZ+uLBqgCdF+KuhWsmwBVE33ni7NgTQHl0wwEYXpMxhH0RfkAxMPIeKI8poEURcAOsFwAYACEDrBnAbAC+xoYRREqA4AM1E0AzQbsAyrQbQrxrjIbSgRqrBXBayGRvKf1DkgnhdgU7jIhFIL4c5CmtCIca7Dbs27w1K401ThGRR326Du+3R7D/sx1uUsUMwKrQywmkKpU66awwuA1jCpHNJLWatHOSbEq1JtM7GSiNtl0jgdVqs64

2hODSzGI83Fw0qeLXSDVVojuOzaU038oKSmc2NJtpFuEtodky2xK0qS2mwBOnoEgY9Gx6ce9og6w0K431x6ietyxaz1S4nqJ6aQZ5jsbZOrgXMcDXGntk6Q4tpLOAWe1npZ6Aed9oO6ue9GyQ587Tbv5610PPG49V7EXpF7V0NgIGhJeqXsl7lrHd2p6GejGyBYmrcnux6P0AumF7Re0XvF6sChXs4FNmo2KeFaYI3uN6je6FkLE2ei3o57YCING

l7be2KAKKvmvnv56Nu7btAkhpVgW579uo7uAQ6YE3r97TOBLHPrNesXtcIjIdbud6tulo1Akbeu3ql6v0KPrXYPez3ssl8uZXpV63LICR7dk+lPrhYse9PrV7gG2Prj7jmOIF17lxC6nD6I+muxL75ehntRNMENPpV61zX3v97je4qwQIg+4Po/Jteh5nN6Le1nqt7h8Fvtb7Te5vHph++9ntd7127Ppz6iCcfon7cPEnkr6q+zxjH6F+yft2Da+

hno6w1+9fsX7ClXfvX7B+/qEt4i+mbRWI28J3qr6p+zSJX7q+/LmX6I+m/q6p5+hfqg718R/ud7n+/9r37LEGkl5aJK/3NJSIwm4qETJjdOLFb0AUYDBhVEWXkwA2gVUmwB9ANrq+A+gfAA4BVSL7C+AsFOjvBt30zROqyrKjJz959awcupgZwEEQrA/assDbs2/VGr763+ihs8rNU2rzL7Fe3yuG8zu/ErXLoc8Js9bi0O7tH8aSx7u3L9OoNsM

6lwjmpM7xbcNoya0qo2hjb5bdkqjASyEfAUxHOzyxc73lGZDzY27XcTKrc2s/3zbaNKKyZRrgkCo34wutWviKNapaqvw8+lXrKt+mxvvJ6nB/K3T68elzEjsPBk4vp62BpnpekHB1wdlchIkfuN6FwNcy37ZOv3mWgr+6/vy4ohmTpiHbAs/vP7TqZCrCHaYAyEaxO+rvp77MK1/v76fcJIJ8G1e+IN/7ihxoLYH0CI7kKGLeyoe6DqhnfrmzvNC

Rt4TUOkA1acMO8AfkaZjQgEqAoAAmjtR0YYgFURsAbUCNQugZQGWMOAI1EIAvsQxuG7SafAYeyLgPYM5C4wEgeIrYajMGCc10D8j9tSW1Grm67++GxxrS+svtRNdUhTqME8SkJrU7qa5Tq8T9yskrH8VJUQYPK7U4NonzQ2nM0+65ByNvmdMqgWrvLLbVLCrB8qjwh5Kg1RID9taQ/WxlqI0uWsEy6m0wbRs6qlWqsHbDNNNsGoK+wZ8G3B7po4q

CRkIfcGPB5+oH1EhrgWSGC0tgfMcIAzIY2BsGl/t/7zgQ9jiHne8wZSHUhv2y8DThrkf7Su+0Xol7Uh2XoP755JPuT6BBMoLpH0s0AqFHV7VdF65T+1IfqkD6DXoVH4CkkcgIXB4nrKGdesvppGf4T/q/7z5Q3rCHshzevQRzRkfstGjIXUaJ79RwFLqG2eys0wQTRgXofsKhi6iz6Z+kgiRT+Rt0cQQNRoUdQdAxn0clHk+/0ZekPRjboFG6oBg

YX6DpWMZrt4xn3ptHW+pMuKwUxg5yDGzjWUbDG7+tMcwQ2pHMcvYu6SMc97oxx3vDGB6FUbP6dpDkf57ixg5jLHV+qB1rGtY1kff7sxpsc26Wx8xAzH/e4q0LGV+gcYuHde7xwyUY+s/qLz0Yqkb17lOesdj65xn/SCG9RnrGnoQx4PqVHZ6BPrPaFRwDvKkBfGftsdnmB0dx7+RZUZ5HPm5fAnGFe4ghnGGxhbiHG/eu0eWibxh/r7G4xoMeBFP

xzvGXG7e1ceiz/xn2tPHve86krHue6sd8xQe3aNPGKHMOu1GSPQ8Z+5h+20eZHCshOpdHWeoMf6lR2MsYGhzc0oc3GCJ78dTGVqe8br70uQiZWp0JzMa8G2eciYOcVqRMYn6exwatonh6ZibUc1uNifqGKxhCZgm0UWmFfGTe98Z/htx4PvagqJmnqgYLxnHqdHgeEBjEm2+vKV9GpR4hDbHNzHiZbG9u08eEm4K/iddGLqKSc16G8BceahA3BSd

V7SJnoxsmVC+yFknZOqceXwUWZyZk7XJzLFyGdx0PtcgPJ2nuhYNJz3ognAuAKcXGQsQCdt7gJnBssmWIJcZ5GYp+znXHHRuyfywnxlcb1bkpkiazL/PC4oEBgvQVtAHuhyHQgGFKqdEIBkwiEB+xnAAmmNN5hS0EwBYYZQGUB5hMP14LOyjHCDRPQhZBUgETYYhOMitJDz95407OxKgXK4MmMmB+m/qkBOvMyZD7BvEms4H/K87tXKoctmz4Gbu

r1vpqATV4eEHh8p7tTNEmywskHIXLmpSqAR77pdQ/ukEZ6Rf4JJNzZlDenSfLeSoqrL92OhEcCLqmvNvlqC2utgVFla0trlKKknEd5yiR4HxInSe4uhSnceikcJ7yR/HrztZRrybgq4puntkhVJo3tLAXawU0xmCbOaAzwppjfoZHMh7GZQ4eJ9seZ69+4/q30op23tPwqZo/u/7UIKCa57DJtvRwmN+jEh8npJ3WtOHBewIz5G7+gWYS4YZxSbS

m0UMsZFmKocKfL74OHielnwuPGfEhGJgod/6aZ2FHonhx1WdxnGRsmds5lZkccTw0ZmewNm9ZnWZFzc6Q2YtnJMByZJ6yHLWb96jZ1xRNn6+4ulln4p0JUdnxJzCYTkTZ0JSJm/+xEjtmlJ+V0ImgxqvDDdEplYm5nUJuTWCnue6UbTpWZg7vZnMCeacVG/JjjApnLINPV3t1Z3Of9k68b2bb6CZrOjFnbJ3vFdmS5Evxyms0nweDUE9EOft5hAp

oZJCs5CH0ZHPTUJQznu+rOeARlZ7ubViZ+pOZUDuxkuQymgJmOf0zx5gT29H0WXSY4nMCEuaN6JJ2/qLGl5i8mrnYh8MfKLd542eRm4sRefS5rZh+IUj95tJ35m5O8+Y3mB1FOcUdR5p2tnnD5XUs5mWezefOSPZ/XoHmu5iIetHzZ34kHm/58rmtnAF3+fFDkO5C2AHA84qfIKehsLVXV6AVRDtQfsH7DqmEAQEskBmQFQikQ4FOUgT9syDVtzy

dnc4VhHs6gsUlTSYcmH4FBHVWzqszgenjAyXCKWe8p/TQOb/6OB07pWnuB9afdanhzToDbtO8kuiqXh57rBdXuqQZsLyMi6fM6qMquJunJFe5Ua8z7b3u8sXlMgh39Xy3kTasxUy2wMHfOgTMZzD8+HuvFMcU/Oabz8ituraWoyGYJ7FPQ+f6aFXc2bPm8RtEnYWNZjHrxi35/frJGPBynsk9nFm4grnse/xfsXLh02dbn/B9ucKKPZmoYhZgl+2

b8Gy+gId1nSZgmdCHGR4BYtDo5nTiKLwF+9gTmuex+Z/nMlt3IAL75yyROYx570YcdUJ3ceqW9+j+eJIeZrXv7nnMY+a8NO0nJaBZUE8CbmYX5koF7mbSLzIyVm5/JS1GEZoJQSX1pMZZlGoliZfz6W5q93AWFllXoL7Bo7xbZHOlhBg6WBlv7Tpni+0lRaWFp68dFGHe3zEKXDuqpYLrDx/IanlJ56Kennh8S6WPniJjwei5vFjxeqy258oepnv

+wcd/mSZsIf1naYwFfTtAlw0Ofnaghxa7Gal7wYRmoZySyhWYl9ha2WciledH70VoBfEa/c/lpGNpK2BYmNSp3oceK7UM0GhAOgCEBaBmAL4DNAvsCgHRg2AbpVIA6wOsAFBwiDqewVe+D9FOBtcccpisy4Shd4ACPRmDNwm41bURsiFLVgTAFZ1hY1VowE2c4XFO6SWCbVLQko9atpgQdJL7u2Jv9afWwNsPLx8ukpPKw26WSozVSBfP6IqwNym

zqXpqcDTbvgTTgl9GF4USqakRmpt+mTButhpBEexNPqqLFxqqsWr8p/JhXwZkpeBX0lg0oeXpesUd8W1l/HtqXbltpYGbD5/ccGXjlzOdo5Pl7/tYHwlhdIPpo16Xoi5ZlpaVC5ZVqBCGW7lt/MrXk184BzmtqRVZ8ga159i/mKWMZYoJ3F8TRrWNqctYahW1ntf5mKsftZaH6nXFdzLoF66sJXZGmrpi90ADAWBqfsI4BgAywUgAwHhgDMC+B5h

TQFURiAGEyIW+Cutb/qPOpbtNCHeZJwrt4wY0qGRxrI3VRrf4A5cl75Akm0LWZep5eO7FLZabJrnWimtda3jdTs8SBF/VaEXVKEQZiqjp/aYkHJ897pkGzVtKqjZFBnJpLM3OwNHJd8tUWuvi2M47l25ybfRcJdDF0IoC7k/Y7wsGwpSxdabcRqtvxGEVuxehXwlt2eI4MVlWZcXKN3jE7XH8jux5Gn100oqXA0UTNcXzkmcmjLZRxvASXG5/+bS

WyHUTdCWAx4We44pN/apSwX18+1ZiE7Buek2lzHja7x5NoFkuX9uqubbn2ODNYOGvOlDDim4ltNcAhGNoecTxW11PCAWylvfEY32+ue2RWejNjezwc5r8cHWPN04cpnDzXtY+YH1tIeeYlNy2yvYgt+3vSGejULa43At7pZxXCCySonWipmRoD8Z1kMWVJMAaEDtRSAEGDaAlhePMURiANoHiA+gAmlwA2AEG1o6wbIr1OFLbVgSxMPGzxwHJrG+

MkEbeptWR+BIhQTrW7XlnbqtJvlqJaVXbhp1ueN7hv9ceGNOrDL06EcxM107BFsQcNXvh41eM6pFs8u5qLytKq2nsmm8uUHr/SyU2Anp7ogdX2YOQKsnnGypsRGRS5EaMWwiqK16sYwEjcdkWmtHoo3PFjJQSWKR/ptbX6N35fX6GhiGZ8H1N+5Yi3Y12kaiWW5IzeGXA3TZaaXVkuue5HZxi/pAXGRteZrc+l3+07GIgjZh43Qp3NeSWr2qHfqW

j5ezYs3pU1zeXwS1xrk82LJ2Ue+DfNwuafbG1j8bOXm+5WbR39lnJZfHUdzCdxsGd/LkY2Od8nbhX7zdnd527ZtnZ52chupZGXoOqXZ3nB1w/sYGMlzIayXh9dhaDHTzbxYjmftjTnDmB8JzbLnE8fXfzmRd/zax3s5/ncv6LdpyBp2R1j30AG8V5p06H0OuBeJWEFmYy+BoQTAAFBMAI4AFAk/FoDlJ4gZgB+xsARRDaBtjRIE5WjEQR34FSrK8

U/RjgW9UppwoGharBywabSC4VNlxteUWBVLkWQuLJD24yvGvVnW67dbE3Y6WJ4bcdIRvDvLoVLu6AE2nnhmbb2m4q0DdEXwN9veW3jy1bdPL6Qc8q+6CzFiEtXxGVy04bZ0knJeUTNqfe0Gj0fskWQmUF1d1Qd891Z+mURv6YTAaQSfeC6k0iTJe3QZ7nNarO7DMBbqL7et2NFnB4J0I1r167lS5xqF2wvCz93KzNxd2dOyXtfUlSBLBDnEsAbtm

zGcAOdE29yPZHUsaEux7kG33lq4MZj/b+FJ7H/YKWPe+HAbMOsVu3vxvXB+s/4A7CJkfbJk/O1hxa8dzuLDYHb5i+EreCn1csGNY+TsbeQhZBoEK6pge8NEDqxGQOsTH4GPsAGzuLdt4wL3DPNLeU/at4X96MHqlWGjrGah1FVODLgCGhqjwP+rQg+xMlxMMbcgBkLIajATWhg9hQTgKmzudmBIshctIp6FIWRa2FSBUGiJ9CE0OXXFVjUGDQPQ+

RbUbRLp5Ch4MsHe4dyT3magaDw7QUN9hork7sL63jf8cqBsh13dc2a/hoclbIHnsn87cD2kUQPaoK7w4gDg7MguDzmPj6gOgBwhG2iehJScDZ9QZ5Dh4er3jBayMfvJ8bXOkKHgL6rc0t5RDuoSUMt7S/v/3FkaOxK93TdCHW6lD4eCVt12ZJ2OZobcaZksj3KyUbxWjy8RUPOjmXyahJQ62Xms37IMNB4L1m2XXY79s4DylWLBY/mQSoQNDpCEI

asP5Lkaxw8RCw62kNhHE1FSFKsl9Kx1jBuD7rfsccCOmFrIDZaMD0czIMQ/o5uveJMsRDgCXwxYmJ84TrqzgEUJa3y6SI6rBojn4GqDpcwU26s/j4fkayk4QfWSBRQkaGTgk2n7ml8P0dQZK9U4RE7nx4TpKkRPjgArh+4CQ8KGRdApE0TuFcUewmKPLgUo9Xdi6t/K9Nl84ZaeB0CQfSIdFkWEbnBtcEmMiFnuHPwWsbnZ4Ncs58Ih3qPAD6hpJ

Ym/J+ysRzDHut7wejm0j6PqggY/JZ87donunSnFySgOUMFgVCZQ6EfEO2ywYCV7YitcxDLDF9gg7/ayYFY+y41ju+OeCKCT3gwPwDww42AtTmyBAQK7dWRtIaQjrCyGG1l+1QOzg7e3vxLgKgXOQjjushOPfeHtZqGk2YsOo5iwVPCezhiDwueFyfJDn4tZXQYnmQflEklEm7jvI8zcnjrMcgwRocOq+UIR7kMHhU8W44VURGx484E+Ak4FdE5oL

DXiniyVPCeCEOeNO/27jm5mHgqBN+oWRVtJ4CHg8uID04bjvKEu3qjghuTphltEsAyc+RAo9TwJzwnNDoxrGMFnP7l+wnWO/LZbQOtfV908hPFrB0RNDQRcCSK0uGz93BGZCvLiJO3IBUWm0cqvgKK0wWxNh+VKwKgdTwHzkk+fOk1L+AsQbnGhxYsIcdvQZPNgO4+PQp7QNC/hS6n1xFCsPS8M0hS8zE2TgkCzUOiX+k6BubM6sj9FW129SU6ms

VtEqA8L0eQ3tXcufD/fGoKwS3mXBk/WHH7ha2iUI4cSwCk3t7owTgRRITTjdcVEfeNYZbly9ioIem5kdFpCgTgLDV+5DderMpZ5mw1tLt+rOsiDqU9XlBoWzHLA995IJMeROB12Q3SbMVZyvGchwS+v2ThwPbdxuYTG4nwzBFRJxp7ivIVGwTcuHRfd0vBuIhzyqbSDjLVdEOcs/lEODkRrbkSF0p3Ysjda2W+Zmzsg7bPVDvFjx5SvKC5MvFkQ5

2+Y4gRcBoI+vQ52y5uI2+jiAKfaa1LAU4agW+Z24oc93FQRNXoOlfeU/u0OrDgZE/yt9ec8JtqOZ8KGRDgW+iA85U/x1dOgpP5iIdLbN+oYF2G2+hYFdFwKQx9epyvAGhVTzxh4dJtBgSnZ+BXD2+EE2uMGcOt9fPY86v0SoOy46TwvCKzjS1Q5sk6rca5LCbXBDxbtVi0ZdL73Dug6/RyTuCDfOMnFA6d596pXvVC6hUFMX2Wg9ThdsBRPpBtJ1

nLBGnppUjy4CF+vZWwpdvDT3hTgy4LNpVZe7GBBt6dbbg67sradTj+iaCbOpLzk9tg7PwrnNOHUUb90EXU4gLvvk2sirZdAhYuvexuyHhiDJzdPvDIN2NCpSjMG3P8sI3OCPrVir0O3S8eMEF9rLuQLwTROFiH4E6NE0LrtET9Tio9TcdIVQqFwQo7WY6YMyDHPzkAt1wulueC6vqlk3ssZ2Xpe9aeBaBaR27TxqAhS/RmDkQuQ4QuNZiDRns+v3

lERoZmZKg763C4+P1ByBzSMWBfsgG8GyNvwDTdOCg2jBcxQ7dtc3mdAgKtTLx+qThFUj8H6QKLlyjhtqL+BCK0CZxI/7JOYuy5sho72mEou47hMDgYQyxO7bs1B0uzV7fDVw+sOjdFQd7d1pD08shU4CayXE1hjElLvrZTYArup7dBE95ES7e07iGyDEl3d3rzjNnBP0dBGSuGzMNS2vis3wz7vzgOjSwah78rhHuGNbD3OBBBXu5BEPymRXO2ka

9BHbjvedXUOBvceDKjv4j9e/RtNDLe/K46YBU4iGo3EsF8NWL+KbPRYbTgXQQer0Dvx6CaiOb4Fptdi0SPUKpKnQRneXNzEOLDx7e2YhL/dwVS5kAaHQR89gUohHQDjPYxJwHyvcxP4bGB6eE4HovbkgS99O+QeRLliYS2+W8dauqUtsLyJXIvElYjziQYYAFAjACEAoAIQOAHIoCaPlLaBFENGAzAPRfdc6neANygSB+kAg/fnXLMgysJKsU4GW

srhCnxHxT21buZwzIUxt24ut2V0a8aDTVIHOOMr5RHP4k0w/k7ew5Ve4Xxt7vKu6NVlvYW3ZtqKo73W9sRc3j0cs6bSb/h2RbdTmoUfdmQPjgZDPQt/DDa0X02jfwMcoe8/Jh7jBm3UOBk/Rpr32Gq3JKDXFS97ctmbIR/f4PRDpNWnAZrE/ZJ1Enu3j/qEIa/fmPxrLIbf3Me8wxye79nkIpJfa7s6/3f4O48iGM9/uDFPa2ZjbAgnhJOEkO5Ak

nSryp0nO9gPezg7ZIPxrV20iv12Eliae62NdFaf+vLTiYOkn5+vfq+A0g/6eBoRjiSoROGQ4tODrJS9Qb+kyZ+TgzbwvdyW/Z7SIodl3XD2v8x7GHFkPmr+Q8fZVuePczt7j4sk0d4Ctw4SSPD+g8RJneCsJaslwegTrtrRnI7rP8jzRy2O7DoS29PLbc6/ywhj5Q46O6NKGc/Ahp2k78POPSsDeZ3n8mE+fjDhgV7xPeCEbYuKOOthnBDN9yJBf

SsvtozwAV7xiAPMjwp2ZafDmMERfob/OtxQ2Tpw9rJmG7k7ylsXqI+kZQTsweFOQRZyQaODfegQMhudil5K8qXsl51O0bda4NPPQy/vZP1Trk4CtU8SIK9PQ1Enr9Oe8D3oVOtzpU8tPQz889TOfcWRXGO8DtoXsxpjzvhrPKj+46LPGzrLk9P9h9V/S6By4lCsSK6uxyhP97sOsNfBHY14ePU8VE8EEWA6Qqzb2oWs9teGzlS8s3fzp8+jsALzF

l5XfVC8S9eATndggu7ef3hgv/uNc7g9pz9qp3Y5rEZ4FOSdFiFvrB7iHFrZsHmi/VCDnH4FdEOLFLljeQneN9uuwIIi8Ed6/Ui8/a6jE4DfqCbRfbyrkpFgUYibhT9Gsk82IlieERMrqPrIUazSHhrFDQs6hKvznbiLf+TsZ/jc7mE4F6R3OxfpTgaQN+FQuuLBrxYt1DkKEdOwDhDxdOtL3tg7fpTtQZFqZqBW4yt93MkNrIy4XqjouFwQw9LAZ

wLtv8hCxT2dMuIRizh24R3tU9ZebrtiWzxup79Bis+LkQrfhF3rcREaV35NtMhMzgB2agczmRTfgeLs076t368ajLOezwvYJn/LvdhBFBkCR8OczcbPCK0sb/YdpC1nFI4vZL39S4gPOrsK/Rr5nig+LIHTtS8wOuPx8+PZDe23ktsQM5a39Ovnq+qDOVHpK5z9UrzO8HqW7/CriAAzuT+UeN/Qq8HP9tLR7KuZPxR/CcUgxUxsh1H4q4M+xzwh8

d3iHgVoJXUtg9Purau6XnwB5haQCkQOATADYBTRbADmGUxAUHRgfsBlZkNuHrlaoXB4mXwAbeNuFEZfYaul9YFQmU9AgdptCxKRwL7U4BqsVZyA6ZHLneF98PrxJF5azrhvR5G2uBwx/VX+F6bbMe290DSyRDphJog2TpqDekHbChx6pENwmMBcf+T0y774UTRtLUW593vhOOEOLyz+Voem7YI3URoQvAcntlHo+9XtsGbsGHqVJ+f2k1ORRwDVv

gQ6SfreW3weVKsBY/aOYcB/a2/0nwUVl2RJsp8/24Dqp82+BiNJ/P3zv59n4er3jS4x87vp/e2/tn3b47sRlV4NvOZFUvHieHvwQ5+/5mvg5B+kn9Amfxsng79yf79x55v8fgF58UN28WH9v2jv6M6/NzjmcEuPYoA2T/2BXup5clnmX3rFeMjhMCyPmISI6J/Gj+p/I5SvcM8qfIz3cWZnE65p9Gfl0Np57fYJ3N6nPNzlOrntLgYt83f2n0gj7

fsDgg9XtjgIvHZ+Rfrn4PCeftFFpoE2tyQwv1nDzdAPOPl04U308d2+7sU4AA9kPfZ9A9e+uP3X8gw09vc4fLzGqa81+nT694iYLfsjAzuW604q/Oc7kj5e/tfp366ZKBOl6eO/65S6Lwrb684MgAfwVaSlkgAoJtdEk5NhIO/vm899Ow1DuWhs3Icw3OBSyEdwT+w/plGT/I/vHiGuKfEa/A9F9nP6crw//P+ulAboUPHLXJV0/WXAtxP8r++vA

v8BuEbn4CRvvU73HL//vqv//pdb7e0rzmbn497+k/1v+r+XpM422fUK3bmXurnpv9z+I/yf4yU+HrcUbOQHqDn5eK/vP4n//6TYFP7dHfR1+Frl2meb/d/99xX+mjAjyePxDsNW957fs351+YjVht/gcriaxbrH/n38gOdN7K6Kf2jkDJe/LX7CfZ/4JYL0z2HUF5OHH26NPYX4bvBX5PKK9pXnAR71eISxRCXeywAlp7wAsX45SXc68NMsy5iN2

gD4OX5wAwU7YA4fSDxSuouXTgTe8dvTDPEgHc/c8YUGauzJ7FfhX1Gi50AzAGkApX5wVSSwInMwbInS07EAzgEMAhvCjWfpD4nWW4a6SvBCAzn5cA0n429UES4nX1IX1dAEc/Et6K/Z5ifCa2gpOAUo0gSsJC/NQGi/bgF74ZcBUCISyENYqwUcVQHy/OQFt4Uvp6ObZzLESM7SAjgGyAkQHG7INBb7RGqZ2YshHafSCuA9QEIAzvDkOFYgLPOVL

29QmYBAowEhbb1xipOFBtCe5zWA+gEaAzvBW3ehLN2ZF6WNL/4gA336d4RO77XDzqE1Zfb+Qb345An/794Vw4MLSQEm3ZNa2QUoHOnXIHj4ZK5q9bUKd/ezrZAhoHlA8fC7nFqzJ+SuqgHDoGO/LoEPMQNDglPU43XesgD4U37f/DHz94IrRVvLQyhqR3ymQeoFDA2YGJ4T9J/CFohR1Vl6DAt77O/XjA1DNe56AifZIeKYGrA/YHPMdVhmQU0Lz

HNDYzUC4Hm/Z5hGkBDy1scxCbDeuwPA4AGdA9YEPMExqrHKGp3xDtIhQR4GgAxPCRCFRzJ7TS7XcHfYlA74FrAg4FNUc5AgNZexL8EaAr5L4EO/S4FZcL0zI/ezDL3C4Dn2PYFPArLjqhddiNxQVxbiE36ggxoEmcFGwLPfC6NxGLj6JbObwg7EGM8J4QV+Q4B5uBY5AArEEkgnAgUDJn6HODLghOPkFP/WkGjscnZU2BshYcKbR3MGkHDAqUHu3

BNqhOBcQ51YkFggkzhdeFM5+vBcA1scUEzAxEFtUdsI3CFjoGOFe6YgiUFKgwUzULRC7e4L3JLLVkH8grUGjsObp28KG5Q3bvqagyUGCmPh7/PO16gPQLZ9PVs4LPfa7hvCgyyKBTCf1WGzjXOZ6hg/j4pcXGqDPVRTcxf25/MeMHkHds5JgoaZrOP96CCYuwZgkMFZg8MGYsX3qT2C3C4nYw5b/YsEDPC8TM8HU6ceTRwZ7cxogcTMF1glLgDnQ

URf2D2gZcSO754dsFhgwZ6Z1KxJ62PKqcWbmJj/Fv6X/czixQEES5+XMQfuFFxTgi/4p/RupzWb3BT2WcAjxFcHL/czg83CmwdWS9alOM9jb/Pv57/HFiOnLn5F2QmxsXXcH9/HFhEOEfD42PvgqzIuz3gi8E4EBZC+1FYgPHQ54BmOCBng8f4zg+ho9XERolQb1SF7HR7mfICHTgtcFfgksLQ/PuZFkEUIfgkCHi/SG6CrCzinFOuxtg8/57g/F

iyOAo6uiSQ73TPCFL/B8Hi/SUKfuLXDL3Al5oQ+CG9sCgbZnEqJYmYezkQnf4EQ0gi1eb5StWENxb/fCGUQpiEcOSyRPHUUJuWBiFt/TCpG5D95I1Feyk3SSFX/ZX6SWPkQKnNXSMROMGCQz8G9se9Y4OfkpbXDkKAcWCGrgqSF1GM4yn3CexcNCByKQzDjCMLo6w2Ti7h2TSEUQ7SGYVFSB89fH4NvLvgZgrSHoQ3tiWQVGwP1C+z9kABo2Qo95

N+QBychGKzkLMKGkEMsCsCMc4HfUJyP3WKF3vBW58iLYHu0PjaAQ3yGMQzCoyrLc5juaqrhbXKGmQt/KHAaj7GhdSFI1EhQ5QlyF+Q/KHu3Yi5dvAYg+Q+qF5QuoxVgfOwWvRZBYcdP4h/YyFcQ3tjqPE9CK3c4S3rKqiDQoSGYVK35nAMQ771BGqpQmaH57Z4SemArrEbZOalOU27TPQkG9UN86nFZcAuuKGqQ8LZ4sHGZ7ksSG6nsaRTEnK8ab

Qk25TPFA67QtDiyOB0TC/X6457XTinQnZ5PQ3tijAh6YyWCByMaO6FIHb6HLtNDiShVL5YeYSyFNT6FbQh6HIcMGG/QigzE+EITPCdyxLcL6E7QxGGYVT9JONA2TAnBExF4LPogwrGE7cT9Ir8IsghpLcTqcTGGPQ7GF1GDrDiPYeDtEWtjK3GmFwwmf50wsmGGtSA4L7QZB0vDGEcws6E/QnGE7OF8523aC6ZAwWH3QzmEIwnbhGkR74KqdQa1V

aWEkwrmH4fOmClgbUJv/Tjy5+VWHbQ9WG7UUvKJsdC6lOAQRG3WmFyw/D4jvQBoZJPBot2C2FCw0GHywk05JUQBoPlZu7czT75nfQeCHsNohUCQJzcxZkHROL2EJPR76+wvdjZXEITlwbExZDUOGQ/bZ7Q/Pdi3HO3gkxaw5nPcag/1MOGCHJOHXEYcp4NJNi1VD8qV4LOEJw2KC5wi9go2eJIY+NkZv1XwwQ/Nb6Jwm3J9qMErLXcrz/1N2bXqB

uFffcuHNwqeS12EERuUJyo5WUsLxwxuG9wv2E7OLraXiGXzL2Xg7ew8OEVwvtSDxdfzDnFDauvbvQrPd+prPWBwOnNaxnoB8oHuFyzSHM56rPIg4KHa4hRgKqwuUBmC2OLbgtULeFyHdZ7wcLrwnoT9xbneshJ4RO74HbeHnwjZ6+YG4ENbE24JJVOAy+E+E/wp+G7w64jVZVyzZ1Xq4bSP8Dfw8547wi+EXsQcbZDWVzHfVOAM6RBGPwi57Pwra

gWILL5awjLo4IqO7dwn2FLw/uEwIg3QzfeazTsChGLwvuEAIoW6XrZe5dbAITc3S2HnQ6BHkOV7JZtH1ZgIyaGlQpSHp4I3JKGVyzGiCoJxg2sFDg+sGXw+GozAxl4fgGQGBAsgH9wq+EG3e6F3wvM5XfLp6VPJswOnTwEbXJ3gDebKHooGn61POn4k/PeHzXFyyAOXx6V4YH7jw5J4Onec7Rg58FNgzBz8bYaArw5Pxrwvvh9sU76PfF+x9cRiL

zdWdzXBFgIDIeMr7fDH55PMJEXiU/pSXMc4XxelqdPHs7M/EsB7sKeF6AjjIWuFkGvzDAFuA8Z57sfiycXAByNmN2bTAsoHvuPdhEOAuHogsrwk6AyItnEsGUHZOGW8VOFKHQKT+CVxy5Qt2yRwhrZYREqKrzTnoyws6FX1PdiOnBewhLGX7QQieiMInOEBcErwBwvd4A8QBqFIzBKnw3+HyHKLYAI7PzzWPd5nBOsiAoPBEoI/ZGSzQ5FyBX7gn

Il7gdFLQ6WHcvLFkRJE7vG5ElkTOz3I8dqPIzgTPImw74FbMpjrSRrJbBz5kPadb3FWdYMAegBQAYYDMALoBGoJBSSAZ9I8ATABykdGBLCcGCELJYaZiEEo8PfkSDnO3ghCFoIxI1rZkwMs7SMYnxV1QZDV5ONBLIpJ4V1HGoGQQ3pg+LxgKpetg4lfR6TxVaYN7UJpN7a7qmPIDaD5Cx4HTD4ZUlLvZs1Wx5OpD7qyDRx6iKAsLAjRRZ3lD2iv7

O1bkKM7zePIsDcRHkLb5N1bXbD1Yb7L1b73NzhzfYGZSZZqpLfHxEWo37wLw0H4XfStpbwdH6HfBJF2aSxEAHaxG4nKBIwHTJHwHGBJRArAHGA6cjBIl/YbfUXJtIjsHueG1HrfTJ4NQbhEiwsXz3fceEhoh5EgPHQ6NeXO7KlBNE9wpNHrtOJFOo3jooJINFRovHbzAra64/IVz4/W8a5qQtEZPUKalgMwEcnNl4q2SnyZos77Zo85hmvUJywjS

Lg2kPb437PNElPP+jUfFK56g9M69o//5G9BezvSO+oFdKX4HDYyKR2Qp5w/Yp6TogRr8vE97q/L85jopdHtHAdGIYAj6ANIj59eLdHxI99y/7MKDhXPj7tnC3DHo/tEroyzCW8NySNeXjYGOA6SOo+H67omKD3XFezHfVyRUDG9Hvou9HFQBm5FWY/Kn7f9HLos9EvkVU7CXSB5l2daRvoiDGAoHS6w4bCLLuD46voxdEnoj9GAISk59WMO6+obO

rgYndGAY0+ixXJk7weBK5sfQIaYY29GQYh+i3HZPa/I3Q6u3ajG5ogDF0Y0+htXaQoflR84ZOIjETojjEX0bjwLXMszJ+eDz8Y09GJyXa7Y9QZ5fnZa4SY7DEb0NaycdT44FubW7xoyNE1ol8zw1d4Jq6G2QXnTXyaYwep47Nm5ZJI55K2FJ4toxWHRooSAafdRRnXCvwFiCNHZwotG7BK27EaG24NHNqzOYsuFtonBDNnDLp13XsH3sZxFZomzF

HyBe6z/ce5TaHzGJo8LFEIXc7TWBVTuRBVS0JQB7o3Sp6MYmaygoeYGKOAmxuHb/aLkdyFpMOqyLnKISdWFhIBQ4WppCaG48OIrHeuFFz+8BewXiaDhrFIzF+Yh+AUGGLgHWWuzLuOTShY1tHxY+PQcOQ4brOcxqsvBLLtYobEIMKxLDHaF7/vHopWY4NHTYzkIV2LX7X3MGJdZJbGuYurhDTQ46EafLTC1SbEuYrTG9cbF63Iz5HMCJzQIY4jGC

Yv7Saw3q7JHMvzNDI6I0Y9jHbUNPbH5Ga66OSmy9RNjGIY3rjQ2Ag7K2MbGlOP7F9o97G9cEhaV/Ggj0CC17g48dGSYteg7veMD5aYY7GidOTkOf7G3Y7ahiPZmGacAOptCL46CaP6Kind1ENPD3AYPVey9IPWzp/dCJk4oV4k/NehDXLBEuxKQolyUnG0/RnG4nYAhFZayS7iJWyTWenFc4oA484q/Sl9A3yo4puzQ/HxSc4qxHc4inF8Cckxq9

DHyWSY0HU/Gp5uohXE3ESgTbWY0KJHLKwuaV1GCvUXEU4y2h2NCIa5uZ4QGyYXHy403E3EZEEIvQr7D8CeryuCxAZIip4NmElHPLVw6gNRw4V+brZezPRHeo92GDSduJqKfE65+AIQQxYPGe40PGz0dbo5VM24+A9OTu48p5wHePHPLfPZvHJewy/Zq5xRD3EZ46w6DSeYEYIpfLuPBjwCeYpHqArNqYYSG725ZramxKvGGAhX614lpi+9SxqMXa

gHahZvE2ApDwz7NSC42WgJO8MQ6exXvHJAtvE/6HU5lHcmyTaauzj44QHjPTDBMA94IlRKyTsdBfElIyfE/warLWHdho2nBxFkRP1HPBbfHWxDhymcBhYClAOpyaVRFjPU/EfwOtEchTYAMvQQpH46vF34gfEP46XzzINF7Hofm5auY/H94tphiAjjLPg65LUvKbC341vGf4vFQYxA9rSPO3Q4zSAmAEpfHjSdUKq2D9wp9HD6b4mvEwEoYimNCs

LchS4QouHAkf4p4iPCFk7OUKKwImYnHyuKAkn4vAkH/G9TUndRSUXdOT0EoAlj0W46sw7xi0wAHykE6AlPEWi6hvPWy9IfmECEhglCEoa7T2NoQGQVJgBzFAn3425iMfMxLHfTEwE2CQmcE2AjxQp66aGCT7RXVjxsgp4HD0OawZXN2FCCFqzsRF0G+/Yeisdcnx8iAHj0wqbA1In4F03D+AVQrwGRcPm5SaRUHvfbQlXnO3FNHJmJGE5/4D0F2z

rHXhrb7WuxWE60F+E4fADnHcS3g+Gx0aGIlGgsEgTXXqxZtNyjogxqCOuEIk2E63o/1NYb8FckEZHVIm1ItwkHMBcAV2KoE5WGoFGnQTQuEhEFgkMR6lvF27D2TkLlE1wktE53juORc6yvblqSYJomXA4EhDTK4TGHGHBYeLC5TYKjxhosMEj8FaibA9jy12FoKsvJtyyI1ywLEhAhsnc15dossAKnJNxzEzYlLPBAiShSt7k2GRT2nTyJHExZ5m

fNSB55DY7O3AoJwEa4kRXeYknE7+hWJQYiaXKuw8nJyIDI4iofwZEFF2VEGCuRw5huAElQMf2FX1OtwEgyuoQk9qFu2TepkgxLpd3OqIIkziHJ/JElLSEd6lgBNoAwwuwYk88GmcQEmIICgaeHTixL7cE4zEqaF9ebEmgSWrwiFL56F2L87BKWkkkk+SbdTUJgJJK+r2NCebskwH5/0KeFl2EUIlRY0r8kyElQIb5bY9TP6zuPm5Ek4CGCkwBieA

xErR4xuKqyBUlwQ+kl1QUM6uUT+EKqBvKak1cHakn3pUeFWZzIJw4JXQ4lvE44l3EzBAH/CHAsTS2wDILonNEgCRBoQBz+xZH7KHV0kjEsPoU6KvIm3UDruKYYnGEsPoinRrxXCHOqcdTQmoE0CRdQurLSMdOCXrBQnv4wQl3UMmzrnTv7QlPqaxkpQlU2CuyHOQJwlWdgQAEtMmSEu6ijWOWagnMuwvYknHG44n5i4o6Q29fxwuWWNKtY+Vxy4r

XH24itYSXBUT7E2W5EE23HdkjE4NPMNSnATYZfYlN6gdYckm40cmwMdVhc+JDwrEZ2ZaeG7ECY1BAlgfh7SFLiLrXBHHbojclQICEElebiLSKJ3iY49clI4oyA0gEEQsdKIRiHLDj7krDEkYrqiw4L9JQlHWzWra7FvYgHGIYFGyS/Qd5l+C8k/knHHvSaiHYmQnKInCrGTFbbGnYl6hNWAYjnCQUrHAAwltYk7HGY3BCHbJPpVHcSFe4Y7G+Y6b

GQXJ4QmiW4SS9JipMuatEYUkjDS+MFrZE2hFLHfClxY0KZroPt55VXQIX1P9F5ZKbHMU6rKQXfqw89cvINFSikdYlYjaOUfjpsImws3JIr+TEd7H5Z/HdbN2zZYxDDULXgLNmGX4t3Jnz2QA17JA69hAJXDx4HH1YQNENAhYrSlAeJ3gEvYNTvBWLFhY5im7DaMFPAJZ7JsJnzCUwinuQut7GiUgy8NaymDY5ikBQ5fjPEsNT1vBTEvkwLi00Nvy

JJSmzQXUTiXkxTFdUOtZ+4qKEbWP4kFPbHGHkgRo29OzpfZY7y0OBdGpUq8muQUwGP3ZNgCWZi735EClpUgqnw1TVysogYTBUu7EgZZlG8BGqnKRAFF5TNoaXFDoaheLoZu7Ch4e7R4pfYfQBJUZkACgIQB9AKRAQgSoAQgYYD6EZQAHAEGD0AAUBQCML6hwJNSqnDxwGOegTg3WErk+R243AtE5+WIMFSrCNBzQfazDwsryImTHCAiOsisCNi7s

eJrxcCGvaCUcr5qrJTpTbfvKt7HVZvDMDSio6x7xVSVFJVGDZDaTr5tlBRZ3KJdDk6AmbsWXDSfAzRauddJASU5H7YNS7ZfTNfZGDT1bBPbcTb+GUpAzVWrYjdWpWomJ6SYAbGPfEaAXiQMpGY0JGMUnuGk0ggiXk476zkwA4q2C6ix4m74L2AvHp47p4mk9pb5Em0HOExUF28aKI7IyBGoIwTSh/TEl0k0kkl+J56I09iyo/YeZqw476wgreCX3

aRT/Pe55y3KuhIIs+GV7SVZXwVF6GHT0LfPaB6pyG565Ha9aCidlpTZKk6xBKkEkE/2SQvAAGqHWgKdMfl6BE4V7J6Q1oQ4xY6+pOeq6nGV4CxH1Q/IfL50vZ3FImeSZDo/GFpnWuoc4nS7tWKyQHOT47gMG16FnBs5iHAFCcvYE7cvc3DYIgCR89a769nTjouaHE6o4pE4FcJKaIIPn4bnHMlSUwAiUnZgk20so61Q4MaYeE/Erk3SmuKZl4Nop

V7B1FFDdeYk5xvMk6y4kU4i4kryH3QLgS/GdGAUmX4AoeU5LgXV55/P9oH/B0SZvaC4oY0JS2NP2n9EgOlHnWKb+ORUR+WOVL3MEnHWnY7iJJR4kAQ0KlmA/e4eUxt7J0Rn4FuEUHGHZsxSmBKHNQmU44xZOhk2YqwRMA0HRw+yAQfMQnjvTU5uaCN4p0u2Kf8eyAofVqFQ1KmzJ0Ls750rJFuKfdF8XC06p4k87SImE6giZaAcfWpGPnZOhBvdE

5VvIMbyPTT5KPDZJjMOylLkuSArk4tpKmYy7weA3yTWG2Z0oR4TgNR84tvQenLQJ8F71JLEJnctQT0gd7FZe4ENYLD7leX1CcdXIkyaDN5xXGC5+Ah7T6/erwjKQP4vsbKDTvIsizvOVKG6ZaCMfVuzMfEUKfldxR+UvvFDwnuloqC9EJg9s6oUugn3vEi65uPPAWffT6wnQz69YWi7hQH961CJi73wAc4LnRq7LnFq4uMm3r0XX96eM3LAPopE4

lOPixiNFxkAMsd4anOlphQTwHk3EfEzXWC7RM1U6AMuJmW0tFRrXfombXSxDpQKBnLvNhn2M465a4dNhgHEs6YEJlG/caBnofexlXncWl3ndKDIM807v1GGF2YL9EfnJ66cU/xQ7vRi6/cAHheg0rA0LM7i9lVWyxfDlAJAfplBwtyjK3RKCQ3CoIw3DGykGSZmSXWj4yXPPAKrbkEY3Y0SsQ1Zk0ffYZ0fduoNQYm6yuJY5sXaYlDEnBk/Ala6t

QU5kgXMm6XMulDxQ6wlaGKLBfoPeyM3UDEX1eKAafWT5kM0z6hYHm6obOtzyBZexeuF94QOAsRgfFfiJQSW7LESrwbrCkzxQSFkUw996ws/jDn1BC6a3FfjpyIy6siBhlmXYSxVQR26DubZwEXeKDcMmuwDeFyiClWzA/AcR7AeQO7P2PFlwfRy725dEF71RlCaHN35UXT37xQNlk1wvi5W8RrBN3UxIKGDEKw4eKCiM7M5ovKmyaYQc7T3Ae5on

OsjSs2DzYfcRl2dIbDH3J+yn3fkqu45wkKMs6mB/QSQT0HVkkkze4GsoYlGsw37nU1uyMoe+7sXe6nP3UOQ2spRkN5UbCOsu6lP3cI48tQFGJbIAYkPUFHdU8h5yNPqkR5dKrxaaoBsAO1AcAGADQwDYxngIwD9dOGRGoEyTLUtYBDw7rwAHRNp+2PVqw1bZ5jAlcmxff96o1FgI1ZFDbvAuurk8frZ6sasI+RCREFBJ0H+NPVJlfahRUgPGjiQC

r6vUgDbVfQVHmPHToiLKx7iol7pGdN7qtfaRZmdDr5OPUL6g0z1QJwEITDLJrwomLyw+FddCk0yXG4bO7yvxW7YBdF9jbOE1G40p/yH7N8DH7WCmv7OAqGY9CmhIj77oU1xG5Ur2mY/E77ns+9m1BTXFzk+n5ZPcql4NPKQNk8nFkvP9na4jp4c0xBmE/N2k2I+ALlkrQkIOL1Ge4qp6LBV5lxE904s03s5s0376Ik0kn0oFAlBAiUZOw6Z5X1JI

GL4nDk4hIWn4I4g5WgmYE4HEMphnMzGhHZ/G9PG4mlgp5qm0tWkW0oyEiI/+gO0kY5qHImGxopwmKbXlZovIw5G0kuF0opuHQsbY4QAkl7cRDPBa03ZEEI7H7ROC47loinzcccw6MY1NGbDfLix0nPEJ0gWLccVw5I/Wg6y0rw7H4IE64vGI6V5MzjUHZ57XXUzlM7TP4l0/E5MjJZp+zBI6F3bg43qUV7YPcV6U/Vzm1edzlJHHg5FHeuk0nco7

ZHVWl3PFyyXIuCrD08DnNHLziVHW/5yE+/5rmWemKnPP5zQncwipObFIU3H6vmCY67Ey14POHcj609F4icpqAn0204bHSIoVQMrnCckw7/cVV5OvH059eFvCe0xHGRcdLjJnYdG/pXso702FCSc4l57HcF4iTL+mk01Cr9IOZDccIbm7HMF4ObKcygM+s7gM547oQEtFucYlFXHStGfIObo/HT14mxNN4+yYOmHQnuwBHTOrz2LMn5vQX4VQY7n0

vM7k4EdBnQnc87QAwfDmckE74vakkiTZt6knF87YnX2q4nfgEEnCAnK/ARntWIRky/P7mOcvE7InYHmfIJemMnLN6ClORm4oMn4+cin5gs3k4t4wU7SlJl71oxV76gptFHvNdFq/REyahPl4KvVl7d05KmYVGJnqnaD55sbbjavOemeZZU55w6j55HQ5kbMxfAdoqY6gpFZyCfRDmifZiBVcwEE1c59hAfEy6MM8y5JnMM4P0445ONCWbp4QVkIf

Zy7eIwow9cyOnGvJJI3sU6m2sk1kG7cblFkJux2xWglzmcxntIjs6vcZOnLcrxj9LUgId3GhwnoMTgZAzs550/RE/7fs5FXRxmlXMc5kcJN6/HA7kBcK35J7CJwXPC+nrASunZkmc6ASHq6PoiJn748c4XcvN4C/GumW/RJlTXd2gbrO0mWbAhmVvUN7MI5io5M/U55MkrnEoXPkhvTE4F8z5CkyCrzgHM67cRQN4t05ckQlB0KdMx66/opWnrAb

7n/nW4jHBBZnQ3G9TLMj6FgQUHmzo96aAXcEok3c5lgXFEjSMpk7ZvL+DeuQuygsnQHI8lREYxGd4H0tC5fwHC5ks/C62VFC7E89C6k8g67kXTO6x3D359eFEg2MlqEf0n4hT3XQGz3UKb0oQJnuMxi7/vXeResx+6cXCcoqI2nlQfayR1kkdR4PWDGNxa5hPCJd5ofcBr71VzBiw6cAANA4ZiHIvAw4dnkpIuj4bXJKTIYvS7qOMFKqXQXmLMLc

npCTxguSbvooca5lrA296TJTWGU2dRm2XVKR/M4z7yfRFKTJXDHKw4c5PHNA6ost94wsz95jyNk7II8+HAVGagS8wlmgfN2hJSNy749GeFeXbPAiCxZ5iC/jl34NP4cCE25Z/MmlPMeezUs+M4dIseQ6nAWJPKBQwB4wFiaCuM4GQBM41cQK7xpP/GxgBZH+QZXlOXLNoZ1MeSsWH5o0CUJhnIWD4OXIVmq8t5jZ+Ag5xgKkGgNGtmYfdVliM3D6

qsmK6DncjEsQBK5ZMkKBuso34WnLK43U5F4bWaOwFXGahTwr/bkfKs528l6QVXFNHVXD94MfO+pvZG2i+nMOi30BpE1scDxL5PRyAcc3l1g69F48LjF9Yzq4ZOMT79BJ3lSfc5b2lIv6f1anKl/LGlb6ZK5LdNK6qfFGY1UJJEZOOBybWUDpJUXT4aPYc5OM6z443aTEKGFrFXBca71XCJxLnGLjt09kyXXWzkmctt4TUXc4h8g87ECmBC1/LuzU

5JQ7NsuCCx88Jn9XF9Hw3LpGd/SYnd/Bp4TUUpl18ipkwIHTEsdKbSgNQnLfMBpnEkhVIHSI3JacqyaV3B0RgikEQPXH9GrvIFhC3FCGi3c+ykGJbj989hGw3JlDwIBW7SXZW4VhclxLcNG5uHLfZBcbIbwIJ8HpwKvL5aLWHc3e5mk3C5kpSdzEYvNF5Jse27AYkNTLaCIVpGKeF/49gRcWBNpG3eFlPKH+kz2FKT53Tg4p3Yu5q3LFka3EJ64s

9u41ZDZLd3LKaAQY24K09k7jcSLFj3SxCWgkiAO3eNx78l25+GS+6lkQaxfKW+5LcP25MsnYoDEQngNbGlkmhFSCQqbZg8srO6X89NEpYNf5APTLF3OM8xis8u6KOeJLoIEsK3PPI73PadgP8me6D3fkVT/N86LuQBrchbSKr3dx6P8hMXCHF2y9QpyoPKcPmfpcpwWss+5Ws4rCfCPryHaPZx4kmThf8ji6cCWTgNY2UkrOPklIPaDEQPKvaNxa

TggiFfhwORdx1CNsUZtFB6iXdaS0XKo53/Nqxq8wCBDwTkEuIrc4l4HtzzWYV5yBRJIYkeS7q6auHKXM3oyRH1b5afsi2C6cXriwP7rPc3Al4LrH6ORGogefxwYketkCxRtmL7ZMaaHDfz42AazFVG8V59fry13JtmPiitkWvREp2OYIXp3W8Wfikxzogmz4XVOz74raRpgotLYQokMRGAbsDQwaalY0SQD38KRDCAVUgh7TAAdAeICVAa6bVbEb

oaJB7KD4Z3gMadk4BnCsInGEeKnABNpyeV05YMlEoBUIabnILQwj8ZFwAiDVRyc4WlgiDlFtsznQdstYbds3gb8owDYM1YDZ6MPVZiSxbZfDSDa/DXeLtfKvidffLxiok2i7bGzrMWMFo+pbkrqouGmJwbVqGnQKyPxK7blVfVG7s6b5ZtUJyHsrEbHs/GlH7MNbWo9CkdYtqR008FqE0nbkoc0DkoQYmkv7Smm61HmlIcv8DeSpNS+S44Kxo3qx

fsvKkMU5UJGY32ERSx9nOonG42cmWmeHX2Zdkj9nAHX56Rc6MVscsDkjkmXzzom2qCcg2lfPRrl2bWDms07JGJ4HTnahXPGJ0sqWF41DmVSjox48ynn6ghGH1SkDk+owziOvSuytcuOHQHBqWIMn166gvrnR0jqUIMrqUmcSPlXcw6nEoDyWTSzCrrvIjk48wozzS+DnXEKlmmC2lmJnAaWdS9aUXsGVk4fOVn3w/wFQc0pFgcHy45C9zqn/FRGK

EqvmW/c4UMCUPmHnIgF3S7rhPCvq7PorhqEcrfH3Syapt85EXPXH6W4EgdTkinZlUi32YcE86XHBcUXS3JFlWNU6VY8oAmuYEMUt3MMVN0rDlnSsN4/EEAWdisS6YypGXQyyZJYC1DEGXYGVkEqP5VWXqHC/CByVEgmXGM7GX70bK42SAbx5XJfgkkUMkunKjn5YMErcRCmysvaR6uxOEGIc7mWF4I4XJSikynCzmXYHNewXCPP6YaFgIbXEqEYc

lKR2Y2OEoYsOiYcsWkQiwZFrMWkXDwekXAnLEwMQ3WVpGGUXJ3Iu65ufWHww1A7Oi1HHFhN0WaPMeE9woQ4RitbFm0gF734UuFzi4Q5/RFuziA7M50y72UuyofQZKMcXJcmo7pCEkhcSsjm9WEvA7iiQ5VgfcXLPUjkXImIy4NRW6fS3DzRy85HnwmLk1UeR5/Xa/xl+fJHLmXOV7ImIweknOq6XE0SNXcBECCiuWBYQ1rrYwaybY+uXa0pS75yq

/DHAS3jQChmBRWQKTty+TkROIFh1xYw7+Obxg51U4UxytOUhYUvLFihJJMJC0q4QcuWdy0eWsWZk4x/EpymMleWpyvOU6bW45sWX1Tw2UkUPwveWNy35gNIoRk047OquSsvCrykeUbMbjwNkTjxwIs8JDy7iVXtPnHJ+aRRFtfwwPyuOXItec4cCR864edG4fy2OVdyrEiMwh47LaDXS0BMuXnyteUJYeGqqyd9zfKTP4QK2eVfmLeobcvH7sdLB

X7yorhUeUslI1RcQXhQhUXysniJ3a7iJAPKrH8xBUQIyBXPMN8k+qTGxzQhDymszeFIKx+VVS6sLD8FkR/1AoKicmKWhyynY6XFDaqgxW6Dy7Zhic8uGp9DvHd2AjHvAzDnByyhGp9EU6Z0vF5gnLhF4clA5TI4/CShWuxDEb1SMwXRUTInZ4GKp9pPBAHml0pkaWnbWWKk02XD6e9YqzehI1VcM74yxxVak3gVPtb/HkwX/FHI3/kDgyEkLcbF7

4XZYjxJdQYmy3xWu1TWFo8isxU/Rf6NMwH4LcUvJu0U06cI08GhKyngjvSn6X2QZ44PM/4qy5vA7vS+oBWXbghqGJW0cbK44uW+yNmfQHJKnWWxKtzZTwlA6xfcuEnoNqEpK5xU9GeR6ZuRwH2Y4YV1QnpUtK5fAnUkxQcdTjpJJZWWjKzcwBEvKUNxapXBA8Op5XVK4pXE27LKnvAWIXS5+8ZInahLZUPMSsA5+UE4ygxIHCIkpU94fIGDPQoFL

7bJWXKkYGVA47x1ErwmHK4fStEm1btEiYlvKnoyjA6V5b0yYE/K5fAMshYFnIB+qelCagCk3pXL4JlBdIj9C2uY6wDQnJUPMPgRT2EC7X+fA5Aq9fAzi9jqRnY0IcWASEPK4fQvA6RhnhCjjg3EZXNK45j/Am06i8+rKdw7xXGksZUiTbPxnbVOwj2RuYMcm0ntnX0U7c7LhUCckG9ucm4fuGRGMcnQV0g3EkZ7ZnlVnGsFiqgrposHd4UmSkmqH

QKhcqy9EqqtbiMkj9DMk5+zOQDGWzE7lUaqtFhck/Yb1vDzrqC4MFyq3lWDVHUG9cqOnFAgcEbEnlVrcQcYBCpcR12JEyngp1VGqpdgqkgrr0CdUlFgq1VrcD04kxa3gxcAoJtg71Xiqt0FmkwJw12J4ARzA1XqqmNV+gyMEQOMJit2VOxqqixk+qkzgBQg9zFkTgQJXQ0G1I0WU7c0wHjlDXDMwypHkzfyXlqziY6XEw6ImQvbF4ijllqn7hGXD

14pvE2LbiH0EFdTtXQ2K8QpBGq4HaBUH1qn7g9y1bTdbSC4BCrZEggidWZ1TMnJ8nMn9qupE4EY5UnHNmETgzUV1AxdUbqqsmezGskZWNdUNqqcwKrfkSJqFzlTivdUiylepN+fK4Ucf2J1qu9U4sBW5V5O9yG6PK6nqlE7u3LuxQ2Yc6T2H9X0NDu60CL56/CeMDm1dtU/As9W8YYWp4HbHo3A0zgeFYDVfgt853k8cp1CTO6oa3tjDlAOyV7bI

lV5HDWYVZiE4fViFbXHaUrA/dVMQ1hqQXefmClF9WxE2DW4kK5wD3OikVhUvnCypjVXcQcab8jwo9TYjV1GFSkZJQqwy+TDSCat/IbAAym13ChyMwUtUwaq7iPCEDEZWAJWypCTXK/WmgZHBsiGOJbqGXXwnMamzBuQHPwk88ayRCcdWvquKFPglinT2aqrAg29Xca3qjNnRkUY2cP7mahzUimXc5zQuO4PlbPn2ayjlXcFOCDnJWyHaAYQvc6WU

Dq8li+9D2i5soQpkIhdUWa36Eiret50vWuoIIrjX+a5D7zJfxzK3coURzcLXrq3thf3ZWw3XRrLKw9TVw89VjFkdE6LiLfJ6a6jWYVLcm8XVplrDb4X5agzV7oty4mKNYbHQumVtaq7g3kqGruwshrU5crWlnf2Hd9TA6f1bZ7yatYHtahrD5w945l+RW7LyvzUdqnJE3UggGzw5DijaqaisDTuIIcU04Mo6DWzapDjAiV7L7CsxEWq50HuatBFb

1QEFCuKGwOq1bUKawhGZfQ04kI7BFoHfTVIce9Yb+CUXbOEmI7a3jDzIfOzC/XqadHOVJA60EiiTGqwUmX1Q4ORjUZa64hr/UZ6iHYzZ5a77UUEXYYqqxcTypCFV9arHXzAwXF23dOCwvAnXI65iVTcjJJ5sWaXpatbUU6/gQsS1Sk06tzVI61qncJdqkFTK4podClJgDd3aiJVdQgwZwDQgZwCaAZQAnQQ0TMAVRBfAIwBtAYYA5xLAwG8DNnpg

arLpwDy7RcvG5USss42VAOqLiB+pusRsIkyl+xoY1R5WkUYFw4uGWcnS2klfE7qco5EACSrtkvU4SUmPUSW7TT6kSS+bb9slSVEZUdmnTKVGA06yxOPVRAuPJZKx2GGmz7PXAIyiPUwjTPbzIQyWurYyWGDHdlTfTfbenGErmLULoH7WyWns+yWAQIKVwU3PXOAfPVUU4CIU040RPk2jGSub9lRSl2bvsxskNPNKXE/XMnpRQaVe4oCRrStDlmuL

GUwEqGWMyxom+Eyonk6/iLRq044xuerXyuYmEGw5DjhS0NGGq1NVTYNRXhwo7WWOZFVaedTlVXZ5EOqyfU2yqxVaeII60czm5pasAAzyohUm0v55Rcgo448dfVPI3Q6pMrOQiHCOUSHbrFlRdm7mY6FKx6LjnQvZ2kv6g/XHPX1m2zermG00qVgMFjkX6h57+yWbkOHMEZLNaVICHao5P68SBB0nH6bcitEk8QA0lSzF6oEV441SvTmCOWEKRS/J

4k44unQ8grgLCp3xKcstEtY5H4c4uuncxBumJqAui3c0OnIvAFCd0/HnyhPqTVS+OkfHfTmsG12mLKhLk74/7lOc5E4AoKV59E/U7b08gnTvBJUSvAFAi8s+msvSWJsG1qXyhanlu4++kRnUUF8iX2n/KyQ31kBolu4w3k/0qbk53bSAQC2lWKG/Hqp4+Bnu8275n1Ari9SkGLJ/dxR2QqE5nnYYjQAs4we0I3m/00uz4M7RzBvDE7VvFSYFnG3n

FnHxSUMuGzN8hcSwId17JvBcFLJMiKj8qenK2fDCo2U87EnTw0BzDfnqMrfnzvUCTl84I196ugm1va+leQ6+a904pkD0l87pQY94mas96vSadGCM6X5tEdKCv8hi5/vAaxOTNRn70/jXl6tJmjvOnnWSIpVdUJaUlI1yzNMz06Effi6L0so2eQ+zrzIZKBCfH4FC81yAdG4Jkf8lFl89KFn9ZD96BuQplQCwjUSaTaW8M3S5R63UotMw9GbBfxSH

SzVk8hCjBTMwOH7vPQFqsz9DGsj1mPGtZmc8pW7xQHRllClj5f7TFAKPQM7KPC27h6B3kSfcNU3qLLBcC6Flu0FfiBKHYWLndhr7Ci43OYU400s8wWBKD6VPoyJne4+RmhC2VkSMuTRzghVLF8wtWWIfFC6891kXUwJTgipxWkkrqFMfOBz6MpqWi0gGWfnIGXno3j65q/I4jYHEVLMiwniaSE2QXaE3SfcbBgy1Zy7MjnZ1xFK6BOKmyV5TK7jY

HkVM3FQFhQL3maPFYXG0qujAs5fn83W+xYsZE2+MmLj+M3U3q3AYTKi5C4xQR6X7nW342uEbBT1G2WnoUJm9XPE0DXcbD2igO6Oi4EETXeQL7Cj8pJ7cOReii/mI1DUFhQIvkbXSk3bXOlCwqzrKhiyVmXkX4WnXf4WhxOMXKs1ezeKZM3lM3cQ9zc1kb3M+61c/qCcm7pmDE2M11i51nBKwLXvndvkoi8OSsNHg0cWBjScdYZnOA367jMgG4+xX

GWoPcPWpQQU2D8zxzhyD0llwh473kKU2UirG4Z6I8WKXQBy2ivtbdQikWY3W2WhxYCWLiUCVpYMR6c/B5msi8ORwCw+kpfJAWJQVU3fM1PnpzIabINXgJf7QKj3kJfl83XTKnsaPRG6/S7fqwzC83cQH3mlWxf4J804CoFmwyxFlW6uTTfg3S6kyl82uBP82Siu3jgSlDogo6CUhs8FHyVbDoVAVQBQACMSH8dAjQwOMBIwXcBtAI4B1gI1AKDUo

C4DWrYsSAOoPo4X4vsbuzeI+L4yrQuxu2awiy3HPayPHODIG/BXgNHGooC2+4k6dgRnIW0hLTLhb8SsQCCSp3UbTESV9sqSUDs3Vae68S3e61HLiLMdmSLfvaIaDbZD7Wyw8AYmhzs3cIJwYk7SPNJgomWQo+FKVXDLGErjfAJ6TffzrmS0dwBpBtjhPANaRPcjYE06/Lk069kDGnXKXkmvUxLQDlAHZvVaZDvXsmutpO1bvVm5WfUpq+VW1FPjn

g+edw/IzTn/Iwoo8Q1/V0ck54sJDrkHkn9ndqWl4nc/w4sGnIrEGwHlMjOzQqGzk4E87fZ2acQ3jA2V6GG2J7AIZrlOGjV6dm/y3AIYw2Tck3mVGa6j+8/bn2giow4tVum+oS9gwJXI19Gud6EG+VzF6jrEvM2ImUC4a0uU0KYnU98rEm3M5U0nyneKRoVyIqxlTYEa3TYuU1jClT5KmtOZokLHHxS/KnTQBKFPSy4UOm+CJ5U2Kl2YXE3x8pKDn

Wg62XWv01JM6a5Z8nxT7WxHEPWyM0gZMdUxmzlzfsh63Zmo3q5mivWQ4m8hTMnWV56GKkhU6s1Iirk09M+sl16/9mdQREXfo2G1lmpAieW+cmtmn65jM/66/RDG2fsk5mT8s5mgXcm7s0iaWZ44qDgWmW6QWlvWdSim2pQC02IXLW7sEt6Uks00Xbuclm9lPMkwEuM1l3NGWJm7m2jYfM16sho7BExDmVEmcV3s+cV5E8W2NYac2bipk7WklNWj6

+TB7mzEwHmvK5K2vk0q2wBDfmk3Va29pE62gdjYvGbTKHJezmGSjyDgig5G2reTR/amUkChU6W2yUllqVgWLPLvEMzUWlQq0knm49y7SCwqx1WmknO2mqTKCjP4l5MaxjMRlUA/LmnH6lwX42NwUmKMRWSYbfWyw3Z608SILfKJd5l1FqmCaZO3CwmfURBJ7JpZbIaFggHjy0qfWp2wpTMy1IWhApfjpyRfWCHZfUP0aoU20JOV1CLQwmRGKWN20

+jdWTkKahL9wHfEuT12+lGHci+j9ClClrOKsBleDu13sru0X0UazLXAR5eaz8rT2kc2z2reDSpUNLvXUmlt2Fe0uIte3cRBraHbdQalo3e0uy/e243XTHAij3g9zORUz2XYJb1YuywiqewOiU+0+w/e0wI+zHQlRzGSMn2K329+3u3S4R6q01VOHV+1L6ke1+Yc2UeczmJw7EiBD27Z7726f6j3Je4WS0B0N28B3psRnX0XGIXsCf/Wxmv+3oO/0

UZYsikyWVB3D2tOSRij2Uxi6SL4OknjFYvMVFWHhyR6Gh0rkX3r4qxQy1wm+2d29B3xQ7XB/HaIKVPQe3MO0uiv/CtF3kzE5MOrh1L9ZuUP1DbH7C0h3wO7h17YzxVD8a1bqGhfVCOySDnYj5Gn7K7HyO8hpoGyk5CcoA0H3PR1323rhuXeGzEQ8P6OxDR3I8Ed5tWb9AVKlnqmO/e3rsBID2yggGBUbbnYYOB36OtehPZO2KZ3NU5/BUOK2OutS

FiRNpucfH6n3Fx3oO0YG/I1qxiebZ6xOkngO3FkQuat+V/StEi+Osx1X6b+XLC4nX6xPRXT63JYLWTuwZ9VXHjTESLFOiu1X6C4QLifXGnFIVC6msKWlO78GlolA0b4uWIWKnaH523PTkOGewFuPkRxpdxS5276F9O+aQafRMniAhZ6/Y7p06io2XmaJ8GeIq3Ghgop09Ox6ETOm+AQggVb+CFk7SMUk1e2hpg/1Ar6nc6mxGkqO2kk7ewXrQBzI

vXRY6mz21B2u/Th4+ty04nsoXOrElXO4crWrVQ5ZfKbkfOiWmcG7PE4Gng35414nK21yX2Nfl6TyqKkPlS20j6yF21eY76OHM3ADuA20DPG23WaWRwB1DLom3UuzrEsVWYu+KaVHD95D8HFya4dF1Dgol1C3F+WC473iZ2Sl3W2yF2DjQsGX4iJiZ7Rl2ezZl3dWDy4XMkNRXRGW2xEyonvAui6a4IQpLJONF80/yXCuqTUGycOzgquQleuAfVgk

CgmkOagnmkwW1j0QsTIvAJUlqrykuM1m2uhNpX9lTkonoVMmEypQm+oGol2dL3BDKsm3u8+m3uEi4SlhYNSoVObXIc8qXf7R10HMezCrK+Gx/vGdUM0xG3W9WIGnKhIGl2l6IM4nsmvETQ4I9Y7wGSs01oUgim1oj5mANdfz9ApfILW6zEpuz7L71bOxJytyR2aa6mX/NvxJygbxKU4fA4qiQ6unQ37zBbykk0m2jaQJ7KPE7ZzPE6FiQ2u7HZ1K

qzUOcnTC/DDEXWkKk3+FEFCuMElo2qcxrSnp5LSJvxLiNkbb2UqzAciaWWNUkkgxLHrLWVJgqqlLgTu6O2MwVgTaq/kq6q0REczQK1/0QsQygmSz+OO/UFDY932jfiyE1eBX+CH56Qci10wE4X5dIzXn6g0i7xBa92gSIW6+pEdx1uHI5hI5V1Sk9uIlkFyimJMhUIcoV2wMEO7f0pq1zIXa2gkYD2AMN85JG1HGLWFJYAI5D2gSM4xW0XsqzuCQ

6VYKD1pEkBiJ1EqJkea4JWTYj0VExBgEeSN4rclZHYenUk/1TQwcheFVJsSwKMcrYlGQdyGTAu3RxpTvVROLj0fE0CSfCK8WYnJVUvEi0Leq7j2iey+4HacuGyHXGIg7GT0iehMbrdRd2pYjuyqe7Pm+pQsm28WhUAOTj2Gq2T0JjMWGGHWuo+csd1zVK223EoCTxQ8W7K3ENQCfbT3Ce3T1dqhI1evWS5Cekz1qe4BAVQ5Yiw46w4HuYz3qq0z3

AIKdXBqe3pIna2jdcWz2mXXT11xSc5V07eoFSnz1hevz2YICa7M/YsluHFrFsBJ50Rew9VdvZswZWOgKFezBBiPFQYKiFIK+HQCRHO/DAtkw3QobR8Idki5bcI7IkVrDT6d/ehJ+WPCm4cjZ2K0hcndTVLj+3PeoFHXUI1Ozr1GQSgTFuADV4w3eRhOzBCLk6I3UMnq2EqJb2IIb8FImbGZ0va/hHLSR1Hk0DU20L/alkD4KHe68nJXdywjuGgaL

nBxwXe0CQmNUsnjWFjo3Oe70z28B2BUD3p4NU0Jru972r2z73Hk9iwcWdNh+Wf7172wH2IQqMF1sPdzg+s+2A+9DXDq9G5PKA70fezCn+w7cTxA1QqEaU55MKlBEL/CyD8q71KJ7UiHeeqeQn6y55uKf8mT08HlY/Ejl4+v+FU+ntz/1QXqund10DsABUE+3UpJI5e4zadd3PgvkI8KpcQkYBCkGy1Q4PKFz30+huXPwkjDxHdyLk3Scl1WW+jEU

jTnVXJZAvUWjUr05k4Te5RxRWtX3AgoimzMz5X1ueNw9LFX0b69RkG+1jW0U6mwcaoa08y83036xURW+oaZ7e/A4Ew5lXFYa/VMY532YUmSFsUh66bWJ5lTCx30++ktVOTZIAjw+SGyKT7le+0P2ac9X3+TSk7SOXPze3PkTK+vX3PIxP0WQOtFPo/kS/BU81Ykb30J+g326Q6hkYKpY7oXDP2FCrP2l+2Sm6ODZwHbCFjF+/X1++1iwiang0aU6

v2q+2v2YUj05iY09DXSoAUO+zP2W+vv1PZHSnrSFv29+rSm3HILipMP2wxWbv0W+331aUhpED2urLTXUTjT+sf1aU7qwy+ByFiHRO1x+0f2r+xDBKasELo2Ni5QKgTbx+1v0HkL0xig8lxhqcq53+mf0CNdUKDWFikghZT0j+mv27+gRoRQ8M6tnJKmv+0/3h+gRoXCe3rFU6w5qjN/0ABgqlXnddEn86z23+8APZ+3UooC1tWtEIKSyuZf1O+iA

OuQDi0Y2WZnaRTiz4BsP0YBrqjEB4uHcW8gP27UMJQLINmwW13ahs9LarqXMBJAeLTdgYYDDATQCSAfQBNAIkDhEMMRJAI1D4AV9LYog4z3ZPFH3rWupuqmRTVBER56SwK5TWet64/X4So1Nx1tmnG3PhU3V6sdM1gtFVneUXiW17WsQO6m5TCWvhZvUrcqUld3Us4SSW7TX6lGrXvbjstbYD7ZS2XTYfbQgbr4jy4E4UwFNqoAIs1FNV6ZHoN/7

sNfhpGSlGl6o9fZmSzfblOKi0Z6ywZZ6mwYOWrN3LY0KbrWxMXjRDt1gEfG0Qc2vVRuzG3WuVvX7Srxbfu6tKy2zl0JeiPRHOgF0ck8ZELOwBVV0HJ1r2nJ1UIqbBxW3/VK2WnwHPEI6H65PSf6pCnf6jZZwGicXdYpA0UGzp0E/IEIGHcrmNcpA1lHEOmnc8M1S+YF5zcpw4c4jOkWcnl5tvLrxLBjK1FfOTTkvWQ1+csEhcG947qUh52dk2g0l

HVgktI+cZQ83K3ZDFzRxcgQ1xak4PpHRJWw8pAiFcztHFcsEhvB9KWKGeQ0WG0+nrHAQ4rUdLnz0hay9ClhmaG5n7aG/5alW/2leMNzTxGgPn/HYhAIhx+ms/VPHTSzc4AfMkkR0o176g7XleKIo1EM/sHeGuD3G86bkBG0aIxGv96hGgMENnAO1dYbvmtvez1tWntVYh9KApG8HlpGxFhJ8/n7V0wxn9WxLr9G2hmJ9MTgYM887H+7DBGMnSkpv

CtaBGwhmhvVOB1Gq+kLGzynf4Lq1Mhg4WlGo/mnvbDRTo/t5g86X7K2dKA389+mVG5KbL0mRlr09KD/8oBkwfZSm9GyUNzvI+l0Ew43pgg8J54TTXuUryEBCCTR9M540bIk1oQSeo3H80zW3W3pmoC9ZlK3eyAbGjxlbG0OTkCt75rGiyC+hmBnXB5wkMC0E3tWHT4+QMMPrIs+yvG0ORwmvY0Ys+bUJhn40a0xomYm7QV0s4E2kMkz6QpUOT2Cj

lllhWE07GtFk8CkMl3G8IV54AqE8MrE3Nmt40G/Wk32snyBdhxD5OC/xRZCis5+Xas4+QBIV2slRmhyf40SPFj7P2ZaBLh3y4UfQeCBKZa38fHXTOYbcN6MioVUY+Vy+uroWSfNXRxau8OO8h8MwmwJSjC5T6Km1RQR6D8MKm9K41FcPSam5YU+8g8XeMhq57Cp3g3hmYnGmiCOEacTTXWl4VRM8PS2mm35h8iPTp8gM0pMnxTHKt003W76VhQAG

318yplokR60Z8wM3LEJG01mwGVw228OfWkvmSab66jM7vrrOe30f4OiPRmyTTjmpc3Ui/DyERiplAs4818igNEkRhk0+K+lm3m981gs5Dj0msG2Mm+lmM2nFneY/DwlmjvmSaJ00p209AyRqiOo2yTS78jm378pcAjYRiPj7P656BxKBem3qY+m7tzGR9s0sRobAhm935hm61WYEbQPY25iNmR6TAV2Pm0Ss+DzWRkZkmR8ZnDK6eSGBp/l+RnQP

uRzPYKszMXxi4wNQWpgP2fFgO86kqa9UgXUzGYgAHANoDMgJoCkAbsBNAJoAHAMhhjgOAD1AUpC0rGPaZsi4Dx7Ozquifq4p7KwgDnNyyaGIvZv/VGrhawmo41HiFNHHhklORaYBNT9b26wS2O6ymoPDYx5Vfd6k1fewMhkb6lgbRr7d7WSWz+P4Yyo6dlyo7sDdfBjLTnIQWw0tNi60wb6hB7gDqyJsE6oxPUGLffLmW+IOW2VnI2WzPVkbRb52

S5b7o9YvWvs2K1uW1iP2otPGaevy2VWl/pnS4jmFFMZ2kwxciGcq64mcvIX1WnBCgG7KWX6xcjoGjF6PunXLrc5TlUGm3E5FbYPvcnRWrWfh50GsLktW63pM8jLmwhkymwEP4O887tFqZQdGHHRENRnRXkAJfM6shlbnER9Hp8PURqih6PkwJeY31vRY1hMGBI5hld4wCoBIcWg5nSXcmwTWr6NhYOQUgfSaziC/mPrh5Rk4xmKCnhyxlBWm03HW

u00XPUqn2osk0yvPJneh0WPQ2lG2lmvTJgW2DwIsiC1QR6SnFQdSPCw5gVgx6eQORvllHorinOWoKO4w/u5GBouzzFSik3stlANmmX5Nmv+4ex89lex+TDDmucVwh360Duu7HqsXE7q2xAVveu63vWkKlAWlDHG6gy4uk+OMpWy62WXGgU2XEJzr0/INNkwBAh2/U5h2kdxBu7XGCoWO2mnNRQJ2ihm+WuORV23K7pCyBpu4uuOFKZu20BJcThMR

A202j6NxyYTH2wj3j0aMt49xuw0hU7HpVWR86BUPKo3XTV3ZBV65ENZDhHw16i96mAl/494W4nEezHgsTSGu+egmnFN6a3d87q4xGUMy1eOmYw54JWwxk7xw5KEipW4BOXC6+kiA7tR//D6ygHgvsH7FyaNqNI8FBDsi+gSciu254sxUFPxoSCQOoLm5uB+O/vL+M4IDu5aGRZrroMW3WgoBNHyS0VYOm+64O7DCfxk+TpYjf5ZY8BPl+E+S5Y0f

i6JY/ISaQBOQJh+C5iq4JlYhmNCYUhMV0KrFsOgsSMJXBMoYuhMinXsVKmrKnMJxBNXwUwEMW5cXX8H+1hzWhMrkc8XSWXrH+OLhNkJ5yTuO2UP8OmbSSJiujyPcBkly0px5WwV3f/bhPDYxL7Z1MbGmInwk80zRMIMKuUMLG4TLuPjHqJsoGGJrn6UDJOX4XCtzUJ47UaXKxO+u45GXY6R5KugxNSJtPYfPBrkmOixOdA5xNA4hV79Q9xwhk4RO

GaDeVoqvMWh0MJOeJrHh//FK2AAhRPM4qgSOHJGojxV+XJJvJ0ipH+UlsoXH+JoYFWJ66npsaFKG/C1xZJqXxN+DJM0OFu1v4593p0dVj+WdBWNbctRXxyZ18HZUXWyQ4azxhSDLOy3Hh2Vs51Jk+MNqE53LBzK3MM7DDvR0eOdu1hUb3PBpy+bXKB6VuOz0XAHypP3jDHRN0txz12eS55b8Kht7ui41xuaZZM/6evHl+JfamxI3EI28uMtMbF3k

uXNhImA6xlx6N1T4kl0HDCCEsidTHe6fOMN6ml0qsOl3wq7uOFBkekE24fCP4/EELWPN1nPJ5PFB0FNiw7Z6ZAjLpJwaFMgpo2LhK8D0sUwQTIppnFoEsM6JJEfgQQtBN3kb5MquhQGEE7s4/MyN3Ap7FND9E05qu83DW1eG1FBlFOOaR05Yx+4Ogxr5NXJ55M/wWmgBHXV3pwDoOSYRvXBu+uj8WcwFLPSwFpezsnEpsegqEvKoDWb6JSexlNUp

guNqQSqMWU8wk1sNRRYp1VNOu8ErvuV12n7JAlCpmVPW9cIlfuBNw2Sdx46phvVp7LIYb+Zyjm4U3kmprlMwpn+CkyanI3OA7TivdOTCp65PD4aombWWxz/qw042plok9A9iycdCBr/wl1NMp6lM/wAhRZWUbGKmvG2up5lO7MMYlf2N5JYeWXGmpyt3JAZYkHaS/XHBvNOSTHYn/BvnmTMUtPnMM4m3Ag775aMNNNuxEVW8Vt3NIxtPf0W2pQgn

9lY2dtPHUUayGndawXmhxMwc0oMhUxEpeRm2Rq/VQ6IemiBTJ71H2Gt3ox9eJK7e5kGuG45PIsE07buHKq8NL9xrp7ZPwHP+gK3LkKgNAe5yaOdNwcsdPAiVWTQ/HNjDxkTTrp4BBXOAhyiktXQLctEjnpiqWoIX93Lgf91YeaRQ9JzaTznJuwpXcnyITA10VBhq1+qluwe4eDxDJifEvu6haDWYjT9TH94AZn3raeKax0Kpbrmu4ZMgMb1zD1D9

yKjNDOYIXYZ3ucawL1LfbEZxBBiej6aTA2G5UZtOCg66ZN5hyTArxi6hMo3MRonKawzfMsn1J66jYvUgxOetF6mJBjMeezEOh6y+MQZ90YRklewB1P46aXUTONg6G5W8UETTdUTOsWEJ7CK5q6uy8DN8ZxFjLqlmO28BjNp7NZzOSSxrXBbeNSZiulAeIsmF2Nw7LxtpNZe7jzPBat4N+nDPwZn0bshOUOeGlm1WZ6bruO9XRONfC4ivXTO4ZoyA

Hgx9UtBeBL2u+dNjpghSNZBY5ncd0V7p0dN3Y5m69yjgRl2CewsYrZOpZ1BCMwzxGmKlWa1x/dMLpuqAzi1JjsCJJI6uGPGlZsdMre5F5rehp0xZi9NpZkxo2nA7EZXFN6RGh9OYIe9Sj8NzjJHfYZHJurNtZ/Pb90jhmgIy5Nxp3VNbe+YHf7bGYeOSsDTZlVMNPe3JVRzix/CcDyGRylPgc2bN6OXlZgnBVNdHYG2/ks6TeuKePTdL87CR5TBv

WjOMhUuqwn2TkJucFQbpB4KWX7P8ngUq4TV2JlDv1N7MX7IKOxgad6Mi/RU13f7MXs2X1mAzez8Q8HNBxiyCdR6HPgOKCOQLIgowWnnWrZPnUpRo9IiIQgA8AUwAnQS0zQwEGBjDaoBGAEGBqEZgCqkdro0ZZXWO8JRPf7KrOirArSigStUNkC8KlZevwZId4Q+4dKx6A8Oz9AuVbQZYmMWvStOl8m3Ufrfi0DRztmWB4aMTbUaM2B27rarIQYOB

qS1OBkdlyWv3UA0tr5LRxSVOPXGQKosGk9IQUrPheLG7R1EreFG+LWkfA75+o6PRBkyWxBlPWGoxJJfI3fb+ra6OBrey13Ry1FbNMvVBR6/Kexj7PO2APOvRmqi5B29llwkKXIVUbMibP62Ce/uHhJiqC5Bgr0qyuKUJxz6PVYB+VlHXKXpSj1G+leK2c3UK4a4mbPGp8rAQx82mX68aXTJraRzHRJNBRhVzR57w4HBu7nIvSvOxZ9POxc/g3pSg

2XkywQkyTePYTcukMbWHvOSE8t5onPPmV82X5vSlU5DGgAXAM4fPIy6BEgmrT5Fh3zVsZ8CQKxqK6vSwK3gSFCPPSjawuA7fPzyfs3LWYU3z5omX9JQSOmnWnXxa6D0780ln6Rl26pSZV2uYH2M/3BM7DLNdVHxtiAhxkOVRquVXDMKOPwC197o3cLbRq+REtSfgUdy0a5Yqu/CVx6y7Xp6k4wFqYUNx1mXpC9pkszGp276jJTTChe3b1P5O+zf6

P6K7G41/OmJ1/O4W0HFOUM+yn0wIOWXVBJOC12Kk1nyqgsKctIwP2/LGw2berBB7hXMFqBFmy7Byyiy2Wyczn1V3ZBPX3G0XBK++VC+mNPlipsUZ7FsUjB5LjCFwLBPiytn/it8VMF6X28FmMazYqF55cm4SUKlgsxjMWGZ/Zyh1/ChzWylO1YF9KYPYtyRPY7Zzswwb3Lm6FoBOwRzeqXpACPJAtX4AhRq9NRywK1+WeF6BXgA4blgvAIvnJJXH

8FFnI/ZL1X/5orhTOzpOS9HdOf5qaRW3YsJ7OnI43q/LVf5jqTNnLo5QlJryq2JIuzcZ3hP1PxyahOmVr5qqWl4mqzl4txm1AiosPMSyrvAlWxf2N2G0Aw/NPtJqx/J6yT0ul3O3S9osuKmxUiGgk7YcKfM2bOFMuWdEGIpq+z9F7kxwEuXwIE3kJn5ko3XmdJU2rU/Yy+D0XHxjzMLcWlNwpdV0a6JYtZOpqhaAupXL2BpUDcmAH1J5vANIsJgu

uVs68Yw4t67Owmcnb4TfCVzn1Fw8wlhL9xa3ajhbXR4ud4DT7uPV8X7DNotXFnvChus4Lhu3dUfF6LY9uHV4s85RGXF4ZP94WN3aReN0dK1vOtZtcwKrEBUMwOOlcKyzZ1x3LhjA1ENuSVPP3Z9vN74EFU7ksFUBCSTax5yks14JYlUDItOaOAfDF6yPM9GKt2n7RrLNma/NF64PPLHZXoBCZbQfA8PPjwzkvL4e9SaOKmzhMcvxOIwUuVc6XzmN

dyLk6cL0sbWTCVeLpFPHILiSIyokMbflXYI90Wz4u2J9sLLjw1LkECBXkH9NfFGNxPLHsCEQpOWiPMuW5UGM6kDPU2NRxBIwOMul20GgexawPKUFIEljks+l2CawegfO/06UPKZPKn00m465FMkMEejdaxIg60xlkzh7dfE6T2JNge8JMuI4lMujsT4SU2Ktkj8DLpBLb9m5lwUxMoshbW8EnSLQ1VzRlun0ETDTN98EtWXrWZjEpzOq3HbkLL8Q

Jzui5iLF58jjg1FzOqO23itltNMFByerqhA07kgr+zD8v1P24xuomnCrwvCBsz0c/TIzF2CYzigWLLXEUJJ3GUzP5r8HtxWuGCUuxzLyzIvkcG8lwHRbOsSxEvJqvk3gFzCpE+4iH7G0fHeKeL3Dg7iGi+6F4S+2oNgFklhXw/+xReu467tG8sW8klgqQlP1SfRiLiaOoOkEfv30aQf0iNB4WGlVfVmQ9f36OTf1PvFfVEquoxGatC4mhg66C0ng

si0zqHdTRfak09uGuSin2GFuoyzQ3OoLQ2bPMQ//3WHS911GYFkZM6D7iAn/XnxgYPIfDhyofP0OrvdqLn6yGPgG406awzmKjPcTp6wkA1CV8vMiVluGlecMPlhwCVEIMvMAvBsP9whbVL2JbU8YwStZS2SvqVg5GMfDnlCx8uFs+MYMpclp4rIvxHsCZCmxfMyvjiiyujPKysXCZm7aImexVqJLkPkyOUENLah3axJIPambQ48B/VeVp/U+V6BE

afWhGXsehH2Vx/VhqMKtoIxOpyEk0Tcg63gxVkKtxV7x1TUe9b/M9sN7B4KvwGjKsrI6hZWIAO4Q6o/V87No7cc/LlY65K7eME1rPg6HjU7U9i6F6dMemi9hSaihw/3YjQ3A+naVV+bFtVvtTY6hjS46vgmbF6LJzB3xNwxvtRVY1v5qHVbRoGoqXzBzA3XEUwHlwljot1AR5dcGvMno9y39wlAVt21QYUfLHjbVvNG7VgBGVRn95/J1Ljb2GDxE

vDYMycjajdWJrwj8OaGn1NYN3VqA2kvDaijWBZ5TcjI6emW6s7HT6sPV1rhuXR0Vv/JEw/iFi0qc5GMXsOcFcOThocCJYjm+KYP4K2Gt9qQLX3Tam6EaCBnkGjp1o1zKvA6tx3b7EI7+1RGoo1/Gsw1wmugkaolo4pbqZ3VygU1vBVU1lZG01ldD01gXNM1xGNbcpBgADCCXAo5gPo5sgpsBuCWrqfACqIfQBE0EGDEAJoA24KNoE0JExmgHSpug

cqNULWxppuyQ6PnWIKk6cgY180ESw4yj0LHVGqECmP40y0gVthW4MsE22li50wNPU9tmDRmXO/rIx58ol3ViWt3XK5qaP1fH6nq5mx4SLOx7So2DZyooswG5+dmRgWu4Ypo7bWkDQa6S6uUMeJGkmWxqqBPdGmkmFrFE1E/IhdZIM3Rk9mbkM9m+5y9lvsvsvilnuGSl5X6OZvPWKlvyWvMwxOfgF6OzPCr3QzavUh5l36besmD5B7y35C+ANMVq

uajl9uujLJKXGchQwA13aW9x9g5J3KB08HTEufpzKVRi/Su6IhvMCcTysFVyyv/FjsZ9VvQvnvemXbF2w4fVyAEycnNUgVxvNO4s52wvYCvhoqqXYG7g154ttyQqn8u59HF5oxqzn71s+sOcvgF2Kl4NP1uRFUcS2v0G8LkXKuZUOvRw3enZw1tc52XqKg47Cg+XmYuruGiKzVUkhkdG7p0BuLw2Bu+vUaUBvDQtQFoiuwTJbkPHemOUFzQuYNkS

a2GtvNfwpQuJvPbm8hzW54NjBvSFwaoEhsUMGFrQsQnDI3eZ2E6BGTusvI0fNBGohlkJqvDsNmK2CmTkOcMsw58N5itv5AUOtG4Ob91lH72cxaV8nZaWSN6WkD1pVVXcdmM30+ZBr6GjlcVv/XRcG0OPvCTpv4TRv9B7RtfvWoubG7o0GNwLlyirzlocdJmxM+nl0ygLlj10BNmxirUQCviu5hjD47keI5ONqxsuNtvRXG2Y3ccbxsF3ZxvPsUsM

DMpSt8cYJsCFzzl+NqagSXQWOpI+j7XPGStqV07UrGk7URcmetpNoz6Fh4M5ZNyh1scjtb0M+QVMMshz5V8YOApvtRNhswXnGlvAVNxytVN/uFzhnwUucReuVN+DgtNxwVkOIYOtVu1GlnA8NXSz0wHiz8C9N0Y79Nyaob5/I7Zc5quO08ZuASUU3dCtXQUq4uhjNk1oTNuaq/h8YVKm5/AwxirnUEICMlXUc4jN4EQTV4x1TV+5YwR1E3NXJjiL

VyassZ6vm75063h8v8sHWs6vMVBCNfSgk0+yZK07VputzVDCPJMl62zHAg18BdiPfW9vC/N06v/N+gjgtxLPt4SA2710bnV8viNmOBFvrB4GvIty36iR40lQaiqCIt6TlYt/6XI2rpmqRoF471wltvp2TCuRpiOmRuytrc6GtIxqVMXLY/N4i+dVwvRltXHZltooLZno3aU0Qy9vAIxyg1ctgdTMi6fnk3M46o1mGvctgAqX5kf5nHJvPMGiZNkY

PU13msFnfoBVtH18ZPX6Km3wylvBMG4+vX6S2PfQjGVG5BEwguq+v4qPSN4XR/MvHc1uX1xOlfwCyMZXaqx2as1v4l2qW8Gn4h2x7O5X85iCoxrOnox+/lr3XVklWfVmD6ANvaK37MtyV/Onkxe6jG9FA5Wt+uEqH/OUI3dW8U1+vOckLPzNNW0ICoB69mppio8r4NyGn4jnmzjpt2hNxEhsmBFtyl5nBzAW7u7AUm6ufA1t3zkY8seQm2hswGyu

DGj4Ftvo8lJyUyogWx/WmVkvb+thcu2ktSO23ECuP50ylSGhc9lN0nFHNJbQWsu7JKM9UsNmpRx4oUraGBxsoQACgRRAdAYYD4AaGA0gfQBHAfpyVbfXNSBwZQrDHh4oCpez7OszWmJOqPkDExrqyEIRX+p4AG69L7ixqXn9ePL6ct/H6FNcXNIZa1gWBoSUiW12vjRr3WTRuJoQaH2t/Uv2v+67XOB12XQ8AHgoh1zS1xockwHhSEb64C3NsZV5

3wOzxsr7XVH25tGkGom3RNlippJB0jYe526M56+6O7wQUtX7UsuuShja9Zr0oxSsH5XuvTM+5u9ncdkHb11u7N/N871S21eO11igPRW7Pmzl+cknNfPPHPclp9l6euFNivMlBvaVx5poztNxptCyoorz1gMZr11qvnvD9ONS9aR7N4A2gSIku/ME6vw/JY7pI9TuMlrEhQtmzuA57DnqI/LAEtkblRYKGW/Rml5Stqg2YTbztud9fAXBz1tQ2WIb

j6ynZvcwNuP1sfUJalxXCGkg0ucoLCY61I7k/RJWmJVpFz6u8tubTGN3B62tYsV8vZd8ZUtSwq3gjd+qZdkK1UcIEPE/bvO2BZCvL4aEMIlzUWR2z53HMFEMAqhcSNB8u2Su7FU88kXPdooJw1OnrtwVBQ0QhzY4xoobuKCm1Wy8rQ1RnbrC32hUNTmDXmkh/rmjYBbsuq/vO+G0w0YgudJSFhdLYNwMEX0yiuMN2CZENuDmF0yK2MVjhtkN7tWJ

GkJ75KERs5vEUMperc4VqR7t91WUNPc4Yjrmde1SNuzkcpkSaUh/PkV0IGPHCikkonJvlNZ8cpJBRRvSNgHs7c/UNQ9tO4oIQxsc3Yxvi/Zo0WhudEV0ffVaNsI7RcCUMaMg/ndBSxuWyuJusbcY2BAlaXEJUnuxN1ziqN4MNqKXSvZN9WkqN40Mbo5nsqduSudQ1+mdvd+n6Nq9ypN1ntlrCCF89vRvfN3TRadyOVNNt/Iph9/laGZNawGhyvS9

6LguhuJkM8maKzNqqtjHUgg8x8BoF0NZsnZ3ajTGg9GzGhazKjM5sYGi5sHIp41lh2ZkBB5aKW92GMPNsbV1hkys48JzuLHGFvDQAsPL5/JsYeClsjcqlvDQKsNkhBpMYtpFvB9nyA/tollQzeEpA1yPvwcGPugfOPtCt6YMyt0s7J9sptc14VuAd//r+soh4C1hKNC12SqYdMqaIWoGBHAYYCqIaoCkASoD0AegBY6UgD1dKABCAVUjKAdGD9IV

WvkDUM7pO8OtDEVbliFaQpPCFYgUceymImMtlpOl+WSHIQoII2aZeVZjsLlVtlmB+2vS58DvWB3tlQd6S0wdxwMs1eDsuB9mr+1gPWupOVFVbPET81RVFxJQnKtWDWSBBhQwnbeMhKXA8KqLBOt8ZMy3ilab74gpDxWSlIPmor3Malpjvelv3N1UpCoABNNMHKg0psZyZrxe9UtuS5aqYFh1X36TPNxC7qS3kkJtyi7PltSDzvQGkap31rl5Rtmc

O56jel6GiYGGnTarggsEPVcyEM2ls7ufpm0uCN37mQDufmI86ji4Dh7jahjmO6hoZrRhvCv51maHfvTo0hMyAdq9+xtsDwrVuN2pnFM0ZoJN4ytJN45m56sa3+a0Zq+9gFkKfA0r4s4D6/t2F7Bl73s+QGpu0s/U5F1s74l1pXleClXnogsg1B5oAdhIocPHSpAJ51nXnvGvXmfGryUV1i9iDNys7udetxGDkJEhl5iqLN18NsW1wfWDsUxKfP8O

qfCXvl1kIcHNvT5am0q7fCnQd8BJ5v2m8PmJD8CSfNviw+VYIcOD6ghwt8e4+DnyV+D6vkqRlEUFD97O6D1wKst5ZnsttIfzyMVsk23WkfgWofHBCSMr86AplDgHNNyXVtW659k5D44LGtnaEYy5oerya1vO3PpAgBNweryZ1vMs0Q4dDi9koyryPN3HyNT2OYcmDyDBFik+5ht3qFF4YYcjqWNt+x7VGrDoofrD7s1QPHYeTDkdSptpBtHDiods

QVc33i7QcXD3zBJxxttky7IdOxjIwdt+rxpwO0s3DjIzUC6Rw5xkex/DpKSu2/DEcCkEd8CgOEYNzaNxPJ4fVYSQWLiTy6FWG6VRDvoeTJPQV1ZE67jTJ7W7D54eWC4w6qyLhpxagUvRD/ejp2hgtlHIIX2Dj4e30Qu36nV2ymcUziQj/egMYlf01XGkfOl24fd2xEUDCie1jXFkf5C+e2DwPAtv3aALwj4rAl+XDyTWT9yMjhUtkj9kw3Ch5QIc

CguCj0ZbKYuOyg3Lc7ijhUejLJvx6q5m4EvL/ZA/CUc1UP8aI3T4VbxtUf5YTRHyy+gsBCzjVoj2kc43QEX43fTGgi94dcjg6SU3feMhPGs29D50esFweF49rm7Wj5Mpqyp+wayprwBjr0c0iiux0i4kI/YiYe6j1m4/xzzFcimMcSl44dX4EO7GlfK6U9Zp7Jj9Eer/ALHh1g97BYsMflYfUXIOmAmkj4sf5YUSb31Pe6WNRodOj2McX3TB1iFn

B1FjwMdT/RLGui/EHaqysc1UQh3YJpjzDjq/DCMAvbwPYvbnDlMd+iih2sc1HETjrEiPCVRypitaKZj4uvZjrEgH/MVbdYk/7sl00dX4ehOG/dh2MJFcfnJOtaypJrGjuA4p1j3sdhym/7pVycWcjrMfcj3TQJywewVBZYhHj+cfli0RM9Yq8WdwvEcpYHh3PhLfJqOAR2Xj5+hKJrxgqJ7mIXFh8ftjmBhk2McqG6PfGRD5Cfvj5MYjYnRMRDPR

MwT4R2W8N/7X1Fix1ZIieNcHQtzN+qvyj+sdgT6R0UcVuX7Cyic5yYwu2JpfLuOYfnYT7ccfjv7R9vPuVrRLho6j+icV4LR1b5HR3uJ1id60+eXkRn7HXcuEf/jmqjHKpZIW0kDLHl6Sc3weGsOOz7Vs9ZwaBatizvArhwp9ZwZuOj3Bo45Q4Y40yelearGCiTk44aA0ra4EESBOtwsoYxquMd2LAJJv5tiXIaQROtiHbPRJLBKoaRXy6nFONYnx

3YoaRAeZgSJOruJ8DjJTeFtJOw2cnSSHUycs4yA5s4yLimT5+Ww3QXrKirKf1xHKeZOpFSLtwNnF9ldsY55KPrt7HPQyfCg5RgUBp+I1A/FVRCKIbLaWgPoCSAeYQg1K9t4DGQPhfXgDULDJL9wcrHFwk4xuO8zNuwtZwiNO9aRtyznkneftqPQFvPWpPaPUrvxS5oS2y552sw5fgZRNCaMe12DsdaH3Ua5lr7uBpS0yLZaOodpfwaW28oW0BXuT

21VH64Lx66Sy6ItWD8pbs+nL4bM6NerO9xZh13OYjX/vldB6P1ujIPIRUFsgD3stUp3uvL4atPc0uLt1GMuvHd5oM8dsLPJonv236oD3SuuXq09zmKTCyaowDzL07LLXv9VjZv0EBr0B9hPvSc/tsDepoO5Ld1u6c0F3Opz5CtB8B0Zt2xVZtiy7CF7iYU80rvsvXH34Nrn3uEzvM1d4ZgIz/mcHMYXN7E/nm6+q7tUBxBDVWoBu1Wim5/d2WlD1

hklwN1Btr2JWeD1ozsHd1OnDpw5Ko9t/VH6pmPJeqPmvd0evoDou66eoHsT582cxN7CqqhxkNQ9nWN+i1Sus9s0MAU2n3sOV2c5Sl6jo1OjUsD8kEP2cyvS9nTufCPemehuVIQsBpshzrzuU9zd53pj5JS9hA2hzngcboxQ65cp2kHFFX64VtOer1jOeANLOe6N0i5K+vOctVgudQzVxlBM1MMDWfQ4+J85sHiozWmnU3uoM2udGOq3sHilAW7vC

Jv290Tie9gAE+0ksNu9uQe9z6zve0gkuKD+nXQtUef9z8ecqD3KsjzyKUDzhrCh9gcOB9QPs4DmjAlNiWPmXNefkzvY5JKh7T6D6jj6nXedSc/edLNCqHWEbwXdN0+fBF0l7Um2a1HSkk3eHPzs81h+dZnJ+fzWxTmU1pGPAgk6lOD6cOLJ3zs/zt+dNrS6WeD4ZsHSNPsE10TSXh1k3XhiFjQLlmuBQKZuS+qlrpWu7mrB/qCoL1a0pYA1v+HLB

f16AIfimqbv4EDBeh0whdoqLZvbW78OzcC+uXBuqUam2IfAR45t5SELu4GttxgR3YXXNnX05SeheetvA1hQZIdoRuhf2thhf6c101x8l4XkUvfAzT3YMR6DIcHaLItQoKLtRttt6kRzCMvWvAdaK2afoRya6aLoM0MB/KZlKZdtdU1gPwW5z6Qo0YBdAJAbQDSQBsAL7BdAM0BcB0XVfAZwDKAVRBykGnPdT4i2umfAm0CQR6WIYR5nrKTXkSm1a

RcAhoNhYhR9zrIavZZ9aot/ZwrT/sJrToaNO1yr4K57aaCDFrQgbEVEzRw6e+1+S1H95DtA0px5bhK6fKDYf5sSL+Nm58RjQjJyT61+NIv91fYxB8jtxBr6dfCn/tZ17PU513PV14UCf2omusMlwmMjp+zvDLj+xrlqtHnsjrE31mItXs5N0cQqlVAznbHAw8u1WFsqkRx+uGSOsGfoN4eUENzqpDLthvgB/hv5YMPOizWHvXXT0zbLmWYGzujnW

yEdqF1ixs+NsnvtBUcuzZ2iDezqGPv7UoOTuxLnBz0KvU1tqhbuzDkVV/Oc8chd12Gn5elcu5v1znbhl1z8AxL1K1Pu5Gc7kJBe/ziLhwr/YNato4PUe7okL6VReWc1uw4rt0nMQXtvfBugI6e3vCjt+dvkrtz294Aq2NonbPSe2ld8vONMgh9DlzKxnlq4/GOs8i0L118Zh0XCQ2kDwOnsrqlXc8yYkVpgbuTexwuLO4XmUDulV0hKVfUz+ahyz

514uGxVfddrZ2WbHEOQN+subPIbuar9YDLd+BsPHdVfOmg1c0h8MumGhmfrDluu0x+j228vWeLIh73unWgcmduH1v28B3rADEPtWyhu8z6hsncZhtfd2E5+r3Zeiz9YDWz0G4hr4WlhrqI2NZtIXjlSTv3+zSDiN7HuJr9/36QZger01geI/YGNaz2X6E9/I3OzyUeaz157gsDgdqNj219185fKzjevZz5AOmaqEU3LgYPX83nsPvYudpx6Mp9Bt

Hs9BlEhy9ro3qxmqi49oxs9rzSAiDid7KL4hJdrw2cXMPXv+h22cWy7g6+azufTMl42HvLApYz4sOmQGQdoCjZnzr8etLrjMNcfdn1uZDddLruedMC8bgfLwF7PvPsPcChE2e+kcdXruIW2QLPs7zkBZC9n2emQI+d1N5TtLj69f2XK+fmDnsO/rsA3Prma0fz+42CJzTt/L+/46dgNBEmz+d4fBeswbrmJTAmWMesoOfK95OdTAjwcrh+tyYb2K

uobkoUsm3LUGMgjcvj5/VVUHBeEOHLllzmF6AcYhfO88BrpzujcKF8z7ULr8MARmMa0bmidsbuq7MLo5vaPZMY8b7jl8buCBXNpq68Ll6RmdzF5PsFWOoRw9wHSGTd12b5iKL14XAtJ3sic75iLTzPmGLwqWab8zvmfPIf5MqzuRSuJdVUYzc/WrwvTz2Jfom/PAJL5U1Tzszd2bn4U1EspmA2/ZxxR1HOmLvdK3VMvuUPaXhIwZkBGobsC19tGC

jAIQDYAegBHAZMRfYegBCAVHSSBgiXLDXqf8MFAWOHWP5lmKgbvZamAkLD5PSOPUmZ2VqNMeqDKapV37eipyMmBvi1268kBgdqwP/rTcqK50VE791XN792aMSoxDta5ydkKS8NidfIErlL9SW8AAKxlmGEociIIOPTob7kKGKz+8SjUJ6u3NJ6vzof9v6bMw6G6dLujvZ115AGlHieLWp0tMUgbJTWkGfJl3VdrWg7fgzvbMl57DBZB4hCWdmCnc

UzCkoEpWMn9W+thW/Vc3+t7YizsZcb0Etdy0uZfjwmmllBDdfWNxXxGY/7ejBrDewbgtHns0HdNVgzujHOMM1JEHeNugXzObyzGI7q7XzSADuqcq5e6+RVuGt7HduxMRehdl3v2DA5ePBzNsw8/tqk7ofoyG4tt1t42avLhvX0rrk4Iw+5erZwEOCz6xFsrguts73Q2Crg05vbtTuLuyFf3EuVdWGtr2XfUrPC7hvozdymN4h8FfzpqXeIIRq2D5

61dkYKAc8et3nzpwulfu3jt1Qb1cUNoSw675FcRe57umzkh1IrjzMOzqhnxrw0Nv5MuusM/0M1GhN5tJKzPw8/2dZrmhtq7suthzvjVehzDje7hnuLGkMNG7y3eIYIueynEPeL4pQnLrxSs9zyPe/SuLCHrm94Tr9XfLz29fwmjauucMuvgbjVnDh+Pcgy/cPgLlcPw9o92672aBwL0jeVCi3dR7mAk9yuVVQb0utWZ58NQmpjfZtpGeh7mKAcb/

8M4z1jZl1hxlxD1hf57sgmkoNe7cLyTf29IffpkoRfybvfMxcSfcVksKBqbpCPt7mvcUsHTfkR0RuN7svfZMiAW5Myk0wOgK3b7uzAObx1ffRo/eBaxElqOrffG7tFQlD567z76DnFQGyO6Bjl1fLvaWK76olQ3XEVD8woLfL6O28txc0ym4f0S7v/ekkzc3AXFkVgXeXdwcj/etDg03gs6A83fD/fdDqUWIHzmlgHhSNWmz5MgH9/f/70Yec2xl

dR50A/0s6YdWRtA8CO6O3lb0M3x3N/dC7yg8+tn0W81gvu2fIvtQSkvt+b+BYbtiPJSIaEB9AaEDxAeYQtAbsAcAPCi5gTlRwAZQC/wYgDowYYDd9g+0VecjNT2eJJCreFdpAg2SAUuek9bFwi8y3u1ktcwz6OTEqN14mp9RyXO1bh2vr9hrcRNLVbNbvae79+Jr5LhDuFLpDvdbnXO9bpx7z5DDvXTtzoUcc+xdtGpf9Th/v2NT0JPqt6fBFD6d

Lbr6c2uGULWWt3OZ19bfdLzbe9LyinQ7jycXNDZffbaGdwD3GcUr/pofb5wbRz7DffbORf4vOKfFd1ldxahjY6z8BnRvUapxz+AEqh9Qevr4lnqD3DdHh1EfnSE/cF0CTs/EVGXLD9ydRlt5t8TyW0jmrc7Zl2vMo8MttXl7SJ3Y4TvQtjIxFx1QWw2ZSvqlIw+30NkcEB4+G1lwY/lXHu1dRPQ+Cy9OjdH/ei7H/mX92gw9bHzrn2+kqdO7MlJC

tTHNVTyAYQAdGBfAO1CSAJGAcAeYQJ+GACKIUYDKAEGBdARLwXZL7A0dQi01bUbp+LkO78leY4HfbiI61/vSVA3uzZDVuzL7Ji1oAPI+1syMDrC/a5yYnVK211admHtfv1bybab92wMvDFrdDsmr7OBnvaH95w/rbM6e65uVGOFAbdIbchStnFySMWsbcuLXaPhCahmnnV2LI078rfTVpeO5yjuvVsxYZ12jt2W+js9L1I/QRO7f9NK7e7bl2UCd

k5ffsjdxjHkTus787cFd57fc77U9dd502kLw4GZHj7fkHtvWcV4dfP4s0/eu05t1z9uewrqzNdeV+eoGold+ktcb316LsEvV09hk1+gldhldX76vmvlol2Nd/o5zQ0L3a2yF2jdoEH1e+usqUgEFi7mM8p5+0Yy73EPaPZPMcrwBibdkw3NW01caRzVdSa1LPX6Vp2wMOhusxqmcar3Ja7DCt4V88/MHVGKVQMRHs271H0jmqBgMD53fwMHJ3WTP

2da+hfnRSu9mBuOo/Y8xb31ng8js9lAPB+5usjnxDB9rzxnur8OEHGiQdFM441znwQ6BuAJstzvs8tnx41dzmZkHvAAu32+oxJ7iJgixq0oHnzecEs0puEgo08jJM89gLsj4QL48ObnlxH1GCve7hqvfg/Kc8xQQ5tWfYne8YTs+BQYReHnDuQczhJn6LoFt6b3A57dwrC77ik1jqote54EC+fo2SNakgM8IXqC+g27SMGxqNexy0Wef7xZkDmuG

4QhdC+uBLiNAHwbiIX4qD1Dx5kECii+pQOVvZB54e0X1qBwHj81rrqX3+ruFnGxiUXU28nuyYdE9GxxE+WmpC7YHu/BMXkTADDx6HWxxi/EX3TD35m1u/XFc9JPWTS9H1u4Lhjs+3n+TAhR7MWKX7Z6yaCs0+sjb2fntiD7D3+48hO+avbxrBXDnOFhxlVvFnxlD3Dr8UPi3M9523JY2kGhblt8JiVt/AL11l4cgW9DHpn0VdlqSdtDt0gUBXuSO

CoAEfWXb5S5xsK9iRwVBgj/K4EYiden1ql0UVyAu7L1AOG1BF0PmREfq69hosdcM+G2iisLHzP4/porvMVIM8UVgkfBXGwUTnmz3ZXiuMj9uO3Vx8ry/iErcX0MjGPlGIVGo70+hErzD0j1H4l2kS+lndq9bwN8k5XVAv5XZuNYejGdtxzkEt2zuN6OeWazXrzAnHvu36Hhi+SzUa+4/Xkfj20a5T2yuvQewpT9xzXCDx5a7l2R084FkUdzCwmwX

Xo/ftEbBwyYzYV9TD5aOnigY+4DYUHXeTFGLznUmLsqdmL1dsi1hC0ufERCMAMyBQADoDdgVRB7AVUg5Rr7CxQAanKALz79b5Lc4ojsp9Tgri+1QJwV1L7F3E7akUE4Sw4OYc6bHphZTlQr3zTqRiNj3e4LiFsfwZYDtt5fxB1bjafpLkk9NbuwO2H1rf2H2S0FLzXPQbYpeB6uVEslBDZqSlk+zIQmy7cXs3+H5rhg9JyTING/x62UI95JB3OfT

0U+Inetg0d57ZdL1IP/9rI/RPfpcAJGTuzgVHfoUlI/dtKuv4i37fU0pHdWZBAfRUqnch1Pbv47yXsobpytmnpd2cG/hccLtbhArvqRUr/Ltu3xXcenQBuqrtrkB37d1Gr1BuF+3Ej2711dDS6vcJ79I2fdjw3Br+O8F7mb2Q9+NfwXr3eu7gtf9GrPeu7wPe6hh/dxk3qACDsxsDr7O9H76pmQC/iuosQ6/f/AWmDznc+rrtq880xu8NYc9fafT

ffp4fmlxC/+dThxIWEr+u9lA9u/YL3k0W83Bc93tu9xCrhcomyTebJma+vM0e/16dfdYR3q8tWGe84ty531enI8NQKofCmwq+RXWAcfMyuxfMvkVR3rK/MrhqCkHmQICVXe/yYFS9hiqVmue3z3Z8l2NKst2NfuQ+/vEt+/C2rYedxb++2kobD6Xn/l33q+9QYocX4PEJ6xXplWyaKy9Q/Gy82e+uvqscA5rmiezKtpB9Jn+TCTHy83THiu+YPjM

81SL4dm27tswP7e+CodK/C08EK8rrB+Fx8OoqC0q/h2sh+tdwVDVX6wXEj/s6kziIIUjgIVUjv3icPoTsFC1GfBegR+0P0+jtx2oVt2pVOCdsR+j2rHp7HgWUD25h+AuwpTCj2YVL2/+4ir8K/ZBL0ydXKeNyj5R8NBueMBwheMfXHe1aPuK/ZBfUdH2mIXD2Qg8yPwh9L0V0d6YkEXEzw2pCd6EWP2ul7P28XeBnjx8RjhzFh0Ij0WP2B/VMF+O

GypMeGPpUlCQNMf+3LzHDX3GcePwUVh3Asd1sASpCd6u6BYliz13GXsVXjJ/QJ9UU3AxB8kzjJ/Vjuf7LFvJ+yP5Wk73L3A03g+7pPqp8YOpsd1Pgu5ebpdv/X3zfCtTg/VTiQD0AHgApheIAUAJG9GAb4+VAVUg46TABIwQgC5gFoCmVHxfgn4iVWTGonYmbcTv8vG/+oVWTp7VdBZ7GX40ovfwajkG6InCrz6Bx4C11pJcTxFJeO11Tpy5l2tj

R0k8fUjm8Unr3VUn+aP0lRaMod4fZXlYW/WdUW926H9m4uMbfFfUpo4fDa4txV/s/ld/vGGT/ul2Mau/TnGnWSpqoAzt7bxyRIeOLQ2/xp73MeuvLOOLU8uOLFK+JgxxaEF1g461FoMLdmAnxyfi+ynn2RDr7tcrlwvWONi2d09xxaDxD9eqd+l/YDzYPMv/BdHBtF/FH2I5ov0lcSvNF9M7tqXldrbfEDvndSGxxZ2rsBkOr0o9dYUs+vd6V8Rr

rE5bb9yHmhsfkQ8tV+53v3eOLQMPlGzmMkvvGLh7nGJ6v9c/EfHF/brxMPJNwvUkMnKsXrnF9dNnsM4v1o+5Cmjai06jd4v78/am+V90oYPknWlIe+vwbCWbsQc520i8Ctwl8sXqSNr83W/KYbUXddpunNqBg+VbxxYbD0NuWs0AcL6+B+JwzUXNqHB8VtxFOaT3CDBXs2vx/T0c4Tr/CUP2OV/j0SfYYcZR98dauGCsVJFvsvBwF+O2tXlt/nrG

q5dXgA6JXct+8T163jXlmVpCqa9vjgd9p6J4Lajs4JaGZ4SdvquHtXHjEANdAv632EhglYa6DCye115ld97Wq6/qPv5OWDxSe1v2EjvXva6yYrYWdv1ga5ryWV0Tx8edBleH3k+v73Cm98oTrTwb2t67T3be3+co4+vvg5+qYsG5abVY/+yIG4qYu8X/v8kuann69Ao9oZo58qfC1ixeitcqboADoBwACanzCH7B1gaoC5gLxeIDaGBNASQD4AFo

B2oOsDKSoi0LPnh7rAVuEY2Bo5pZF4InGWgQEEqpcqzEHGtRnm6LuHWyfuJxqUya4xjy3qGjTWL4CCYw/L9u2tconhZBVeXOs3zJdK57Jf7Tcfze19re+646eKWtcKUZJx74S8/uxtW6YuIWdw/vK4aAvuCbR64JhGp3YOK3pOsUdlOv4qsnlI9eKz/T+lzIv43zLkyn5BhTPZHj83AW26TrmAqnqdlpfKgnWxwxcLJ4OfoHqRcWMALpXuUDy007

DnH3hybAL+YaIL+9IPkbKHanLdW2sdRw6k6kTlQbLnXUI9Bi6nl5AmZ7cUL8jKcL8oY72Lk+gLPepdz8Wg3ezFZPI4DCQSx1X85KleONJMTlg7fC3okVPGH1dbXx+Dr+a67/EnTX8cpwYwrL/IntJgj8PaSJfDPZlmYrLGvAb/P47L/Df3PNIpPPFW8Z/0zC7mY1i8uDNXfkS8X5+iJM571d/b4VXnDEJt2TLMWgwPrUMxz+d8Bzrt4Br/SPdhos

Haa/BdnPwlUgOzTaMNcl+UBHL3B5S4eP94WTRi5P47jkrNv2b7ucEa9fldAl7mvDxHEo5/XL+yeIg2auSM4I0+VSevmS+6mi5bOG6R66w/hjISUyb9tCMfqWSbOzQXEvJH695dw/rH95VHH9z9PH8vZvEl0vncgiHA8K0BEJ7w+S/qahYZtCHO3S4C4uh0/zy8HOa94hbLpGne8rw2nK8RtNhg1f7Hn9M/rV6Dj0DGImO8nZcxb+ZtUzjfXkYGg6

1LBpf2xwAOOX8S+Jb90kpX/D6aHGrOKvL0WhCA7flrHEorKHPA4imDwJODX+N/63NuVKm/rv5pMABsoHFN6DPAsTnh4uguV1dwWcS4T7uMOowXa9Y1VErUzcjB5L2GL/W8CHB95z9ugpTjryEoF5nfwL8R/mdOZn6P+Z/SA7C+hlunFNQaHuWc37dqgQcdPPl5XREgmnTi7rHDay5/8N75/9yyF/kJ4vHBi7KHZ78pVyv/SmlyQsfSiXMQHd6GHB

v/C1Jv84EN0IHhBjwANSz+1MR7+wBxv+pXbCYZA2MFD/vFub4JqwlOd9zgNSEvM8G6k+qMwWgI71J4kef+EJjIHL/jdW7ugr88hFDHMzXfGlgP7/Qva89tURsGruX4Rt+Fu5/cyKnMR6H/Ff9csipc23iVzv6YcwcZl+VxCo/so7vNnblEGkV6Gq4CDnM3FDBkfyisP/9MaR24VEsMji7sbdMR221efH8rgHLMHjU1sX3qUpxraFOKPl4Wf0HJXK

xwnEx5PglQPAtBVVUb8H5/RsxBf0pyInlvlE4tXENR8BHeVL98fnS/Iz04oXPqar9SsljOPEh9f14ma3hNH2GhYW5YwDUcX2MIcB3wS39CaizeZgRnI1Y2LOEhCmtkfep7phVeTQU6NB3ET9xD3TV3RO5G4kEEfMEHgw+4LyNBZQ6saL0En2B1DGICXhTBM+xXOSpvav8Q3noSfCpNYXEA6E4orCJ/USYW/zBaEUIKwmKbauxv9n8EMwYuWVkgfv

83GUGnfmUe1gS/cy41vWF/PwCpLAH/QIDNQmCAt2hQgP3zOvM5ulOVRQxeGkFKHtZwzhxcPkQyIQpIad01/2jBaEpD2Do9EZQywk2zVc4D/16QI/8Pyi2/NcN64gYNOv4NlTy4a/9owU58PVUT2CnhPG5mbiD9MLtZIElCd45POQ1ub9gH0XszQ0djSku4N/8y7A//CoJ182wcFqwFTg2cGNcgAJqGEADRbXAkL0xx3haIEeEC2xH5TkEXp3gAxw

hQh35KWA5AkQE/IjgdgLgAkfAEAPAkVHl7yhiFCxoUSFL6cm5LGh/TJfIkh2tdENRaBC62b4VPhDAuJ4CsAN/Peggl+RRdeNIFxDZ+OawiAPfbNyxAqHAkKjw/LEnFd/lZflreSewhYwy4brgrbnLMY9A0cQOxMtcaAIxsOgDoQPnBFu5wRlVsIfgy1zJaFohRni32J39ch35eUA5nKhcuIgFJBXYA3NwaWXAkbjw4ETYlfYY9njrWA4Zj/mZA4s

JLznDqf24GYFwufsEX+QEAt1Fs9kGserg+3haII1oi7A4EXtdxQIaOSUDI/yPzR+x9ThZlWqp29EncUA4QYlQBHtF55D+iaJxv0ifsXH5wBThdFClV3nHKergLEFV/Ib9KMUJmGQD0MStAif955ETqat5/7EqWVsd6UA0AweASrH2JEnRF+XjHbIkg6k85antbIGbObg5OQhJidyIbsxwgUYFtcA3WWd1T0WzwSMDR6TdsXWw4wIagfiwmTnFODx

oOZQ7ufokEkU/KAdRUTm3EbGZDnEJBDDh5un1OYsC3YTvzXRxcAwPCdogSPhMA1uwvlHMAkzdjgiGmFVglnhNCfoFs8DsA9ywHAKaxci5eNi7xQuE9nkqjDGwK9k8vDECxwLrhdUFc3BQ4ZP1gTmc5HwCfgxd+SG54EkJqJNg8/lkFVGw1wO8AwlE/flJxVIsNv1tcYwUQgP68JrMAC3Shdqwq9kgOTvkZVgyAyc5eAlORF/MqZUxOe9xPU2MFV8

DCcnfA3J9GZ1PdbSJT2EOhBu4ZqCKAtyxdLl+EVzAGkS3EdB8+HU8FIuUvcD1sex8JQhszD2F8QUY4MDd3bjt4G1Yu7BckclQeXQ0pHG8AYWzwPCC6gMIgqEpYBSmZCFNi7EOcWoFSPg6AsNskTF3keYF1bQcqDLow12Yg94JOgMsQNQC/zzfOabpZwCsQEDNXmG68PiDWIL1Vets96mP/OhVT6WI3DgVM7HimQnIkpAGdMr9jvxaxJSDhgPUGUY

DKZXyubExutW62FDhGPmUgkYC1ILHkbgl1BjscJQ9mZh7lJ+oVnHkpVl4MjEnfa1Y9jkUMEP5drlmA1AC9DwyMb5pZS0/4H9MTpXM+byDqBF8glyCkpA9JPvhc2GNKSno/mDCgpyD5gO7vXPBPaTJcFuwHtivYNYC/XGoaHD5BuCvOauxliGRFLxVsoMLTEeFNwKL9LepKkWMOeqsoOFKglktyoJ6WPsl2XWjsIBw/mHqgjYCQCx6WR04Wx0UBHO

4Wvw6g3KD6EmSFRNgEIIXsPNg6oMy+HKDPbGGgvHhsrhpZeA4JoMU+Q4C+PyZGQ3Q1j13dMnwZLEMOHqs72AnJJGoHYjWg6mMr8H5VWHFUAK9wb3gz2GSAXj9DoLMFY6Ci/Q09JW4W6neCZ9cePwOgutwjoPKuYosHyiKsPP4hiGWgm6CPoLugnY83G2VsNXRjORA4a6D3oOOA9aC8eBLCf6YLqXaODes3oKOA/j9YYP3oPeMAGk/qIm8soKmgsq

CuoJgQHd4bv0HJZ+oif19dNXR8YLygmBBSvGnuX1J7phJ6MT4KYIaggmCcbhpg475YwV+zX2YHII1rCKCYsVZg6j4CxUN0QkEuC3zwRKC5gKVhFKCr8Fq8Gtg5CUyscOwk8G5gnyDnIL5gkgsBhAfuQvZarjggMWDeYMlgrEgJCmv4P44okUrqHj5HIPFgvyCYEDAhSuoerRruAktbIDMg3SDVILcfbIJPAWt4ZepbCyYg+2CsrAsgp2D56CgDUE

RliDkJfC4dIK9gvSDLIMBuC0sRWVJ5adxg4JORR2CKblYsG050UwOjNA5PYNjg7XAfYMOSSIJQOgWxOqxnShmoVOCVIPTglKROiwiYQGF2Ola1AuDvYNVlMwEGBBzqQa0SPkrg0OCM4JQQeI4DrFARPTxIy38gRuC44IJFRnVviW5BGs0Y4MLg/SC9ZWCccmxNHC3OHD4h4Krg+BAR3iN0b3hqBAO+VKRu4KLghO55ukDsLRUtYSmBFeCR4KeaVw

5UuFjAPqZf0WngpuCIWEbHBY4TQnxOC4CT4J7gjsdlblA6H95JYw5lHeCw4Kn+Ny4hiEBhZkk75WZNcyDT4IAecOp3IgfKad9t4KGAkODb4KeaGSJ6VX2JPDFn4NAQtODd4I+SYelG6W32DdYeIJfg5uDPx17lG2lBRBY6Wf8nIHQQqIwisk2GYBlq4wbguBDh4Nfgr5pH/VYOahkxQhvg1eCFOAxiaV4t8iWOSyR6EIQQr5oHsWivP4RQ3hAQ6m

wwEIYQmBhKTnRsRFlB4ynAghDAsDZOMy5INQPCDVt84PIQmeCFOEluM/Zlv2WudhDKEIheK25py2fBEdwRYLtghRC/4IU4AB1dbFOKWOw+EN/g8BCjC0S+erICUyRqCuCDEMsQr5pGPmhuGUdJAO9An+CHYMEQ6TcJfjEZEUVj8nUQjBC/tGxeFIJzbnr8Yjsu4IcQrxDpxmj+B+ZUTUmJWBD+EPgQjRDFNl96Q01mYVNwAH8PEIEQjhD0piIhAB

xhfk0eb+CJEKm4EisZ8RBiP14AkIhYOcFc/AyheW8Odn0QxJCKEMCQ0y4PelqFK6EBU0qQjZhIbhYCYWCywkI0TpDfmD9lNQZi5VeLQy5ikOhaKlkDZHo0fgoxkMiQnJCUsAIUL/0f5Xq8FK4JIIv4NXUrJjYgp+VbyTWJWPVYvhI+doCpIM2QmSDfmCGmdjx6BBHsLMtMhUkgjZCugP/oaO4POjOQOGwzNRCgpyBDkNuQgSD7kO08Z31lUXlEHD

cbkIvCY5DBILCLCKsDtkHsPikUOHeQwFC7kISwd9Vzv1i/UUDeII+QrZDkWmqFKg1MxRzpa5D1kOhQz5CEsFtqbCI73AKQ/5DsUP4glFCtxnmBAckxrBrdVKRKINLeaiDgnzJ4R05vlBXQbz9sNRmoWlCCIOfBGiCvzDn9dk5+4AN0W2D/53wgh98iIKK4KxJINV0uCHAUNg5lDlCRUO5Qsnh89kJybstekAojdlDagLpQrlCGUOH0bPx3HjxqLc

EPHjVQnwDOUJ/eLVCejH9hLv8a1WvqJiDZUPqA+VDtUIbNGhw1byfsVEd4NyNQuVDTULcmQB4zTgkOJF47mBtQ+lDU+h3eDxoZMQ/dPLV/UM1Q1PonslzZP2xBkBCpV1DhUNtQj1D18BZfZ4lIkQ7AiiD1UONQ0VDj8B6uBjJ6/jUcCkwM0LdQxNDU+hIWegs2LnouWF9/IHDQk1D8uF3xQw4X7EJBeKZkILYkVCDNswbweq5O4jZGclUifwqhFC

CSgNggmzZZKSeUax18ZyigRnVigJgg9CD18BDua3gAfBnsNRQpgSggttDB0PvMTQ4YTg+RclwmIOXQgdDp0Lgqaf4UDjE8DjI68z7Q1tDd0OOYUJcCDnccSrwt9kMuHdCp0IvQ3fkoANqxFtDJ0LQg2jhmziWOEJxw/mweVKR70PfQ5vBS+iLIS9Y7Jxc3U9C30PbQoghKThScb3gywiTA19DoIIAwoghNFVBiaw4lDj/QidDEMMgw3vo4S2QA6n

9l7zsFTDCV0L3QvfAUBTWceV12TnJ8BDDiMM3ML0wC7HiBAsRHR3HQ/tCH0LsBCAVD7EbAzo4OZX/Q7DDDzGoFOBx1FFynE34eMNXQw8wGsSXyJE4vYl6LEKARMJIwmvAKoRtOZS4DZU9XcDCsMNEwvpV3bny3Fk5dHBPQ2TDujmxeC+xEanGHFTC9MM7wMj1+oO3sJTlqMPPQzvAxU05OZW5qBE5CazDWMKaBbqFoHVNOX9I7mFMw8fAGkVV/Jg

DbHDtDGTCiMJsw8fBpfGfCafU7jgiYZzCkMJRVF2xeXDSyFCl6vGiw3jCuSzsxQe4MfH2JPRDVMJow8Y53XjSyXH4g4g5lNhNM7AAg7IDKuQkuYdEnlAKCcxFbIGKwzICsOETUNcxpS3lER7VMTBdQl8D/ajfAsrDwQRLCfEFo7BJ6PLU6sK6wxrCsuDJsXQEVAILEVKQhsNKwkbDDOB6uN5lraDHOAWI/wM6wmbCPwMFBZH8WTn3zM8IisJ7FEr

CsgNmw7UEGAOm6eGx/whQ4abCDsPWwkzgjcj0uUA45oQY8O5gLsIawq7DR2Gqya/xpumu4Uc0VsP2w57CgIMGqV1UaoIqAqE5vsPqwwCCF0kHGBAUahkkeMuwQcOGwl7DbQTdCVMYGyCX4DGUOsJ+wsHCZJmndDq4a5QySWHC1sL+wqcxdIWysMhYvGCmBJ7CMcKXYJTNFsP4pZ/k0cNBw7rDrsN6Aq8QLwn1udAs6cLhwgnC4NWoWZekE3H7FUr

I8cMuwznDNSw9OAv9rALUcAXDfsP27Vw5t9jaOCmMJcIpw1MtjYQaOXkUV+CYg8nCGcNjVYW51KW6LQ2QNBX/AwXD9ux/qatVJrFkUK3h5cI1w8stIwKKsPlNmbnNww7C8yxMA8xo3YQ2OZY8QoHVw+3DyyzYTM5AN7xlXL9c9sPpwj3DTuzwgm9RDTmT2ePUnIHdw+HDTuzMglilGLlPYdxDI8KFwtqh5Hj6mZm5sETWrMnD/cI5whdIjLi3OSb

Rth0JsO3Co8JEmCqFt9icaYuwAhDZwxPCc8O48L+x7ZW9Sfkt2cPxwhdIe5Ul6UBEOBAn7PXDVsINw9stwSnYsbIkfsKLwpPDEWB7AlilnzkPCLvD0cItw2CYxHnkCP/E5FAfKIfCF0nidG/8WgIuOJfD5ywDhLst63H1BKbCgtUS/GI0UuFhVONxGE2TYVHCdiWyJG8C0hSPwyd8kji3gn7tasP3w+ICViCPw6KCzrnzdU05DLgvwg/DbwJA1Tu

wsNCLIJCE1cKfwq/CX8PoaDhwFXkZgVq9zsJAI7q1qH1HYc3EuHBU1c4RnKBgI68C4CKbeNa5rxCCdMRkrwLiA0Ai8SXoaE05CcgphGq5T2n8gb/Dn8MIIjCFSDl6CFqx6yEew2AjD8PxYMmxMbF5CTExHDjwIy/CMCPxYMCEk2ADsKbQLOC4In/Dr8PxYC4QDHAHw9E5hCKoI+Aje3gTg4k5TYUfWTPD0COYI98tUbE9CQURxSTQOSgiCCNkI+k

5W4KsFKbR43mkI3QjfyzWsOhVo7E/qbR4TCJ4I7iEIoUX2A+x2PEYIlQjf8O4hOeDrxBMgu3QbCNUIpiEKDCi+K+ozzhW1GVYXCNEI0ggjcjehUDoprlSrDQUQiLAIsIjkrgwA6Mcl8jQI/AjbCJ0hYBV3yg5uUSFvCNcInSF34KTYALD/bj3w2IjqCJ0hHU5+Cn2GGAoMix0ItIjFpRyLFVhHP2txHIjQiKc4IUJGl2T8bdwq8KYI3IjFpTZOZO

MMoPrqZoi4iKc4HtwPjhMLX/9Z3xiI1IifCLchIhDaAPl5ZQjpiJ6I7CsHsWHLX1IaBhN+GoiZiOwrSW5KRRuEA3whiNKItyEp4Sg+Bsws2nXQQ4i9COV+FAVGMVS/NYYgiK2I5YjyoWj+MkDc/DNhFIjuCO2I8qEiIQj/dx4j/UuIiU5YgT0ucOxkXABI0LhuphzZfUFKAV2wkoiriLh5E6ldmQvsA6Jidgjw7oiWiJmhbpDNQjP/FOwuiNhIkl

g64gQ4Ka8A1T8sMEiPNQsNauxlxHsaUkjhoW6sGFJvSWfsc/C0SOGImaExYSzacFVQ1Dg3YIiliPRIlittXSrLRQM7sUfwvEjyWEYnPUCl/2AI4Ujdezn9D+EqwXCQt3CmSKOIhmEPSVkA8+wzuHxBakicYSvONXQlDHQVS04uSM+Ip4jlfm/BCoJNrAZgM/87NX1IkQjmSLqMLcl3LAPeO0ssJ0tImQiSWHvUZbNHgIuZS9YNSJtI9bo/QJw+fr

lGSMlI405neBnhcM4kTirQ+UjAyIa1C4QhFRhPLIZFiINInki38mRBXgJ3HhyqDjISPkeIxMijSJNOGLgfsRXsFCkvSIORUrwPOkOhCoCwMMzI60iiyPnBEb9TLgNkYojuSMrIq5E5fUSJf247jg3wvOFEsTMiGMDHjnbIyuFc0IgcBGslsMYI/XDJcLKRPA57U2W1D3BeyJbhEhYYhWMxYf5HSOrwh05IgkvYQX8SyHhFSfCA8OLw9PA4rRIFVS

kT0KXIy+Fw8U0lA4Zo02nIjRF94Tckd9A/xWQFQ8j2Pht6d80LXjLsJjCm8J7wy+FjHDZRKzkyS03I7PCtqFcOJOwInBYpDMis8ObwragrvShufylynF2wkciFcL7USSx8DnWCAdUasNfI0cjoEVLyYw5l8j1A7QiQKLfItBEejj9HLbChLHPIlhEf6naIDa4gs3DIx/CYKOnwyWZiqwsJEDML+GHI7vDUKParDu4kvhEKDECv8JwolijBq2gw7m

Ilnjs6KtsUKNgo/uE5umRcBU4EkhZEGAjqKMDwyWYAoUpRQdweHGQou8jpq1mJcaYpuWidYCiZKO3IzPtuPBNaA9wBE0RLKijmKJEo86sDMKcrDHwzM2IoyWZKozMvcEZM9gVvH8jQKI2lZZ0aBh9/amVrKPTwGa0UKWh+TojYR1RI7Sjh8IawMs4FVD/qC1MwBUgg4LCXMLhrWOlUNjkpRv4OMG8wuGs0bgPeQkCy/GQFJKiMayIRWGx4HQotZL

D1MIARY5UNkkI0EZQkJ2ywkLC4azMpZH4q8g38drDMqOabMLDuM0SJHu5IqJYwmLCMa3M9NTCd5WYws9DoqL7UbQM47nXQBNxUcPqogBEFVn7cOOsZ+3youTCiayPTEBUBBGbBaajn2A+ZdP5m6kEESmwlqJvYd15bvQ4/G6tWqN6o9qj+4VY/ZyQutnLgPai/cMCo+DhjqJ2os6jlKIVIuEjSzmuo9j9bqOQFVcCvAMO1EVktqN5WG6iBHmQooc

DZwK/2ecDriCeo06jfqOQFNsCVAOy4QjUrNyJrbajnqLBo6sDdhVeLa7h6wOBoiJ0gyWlxDaiZqELA2sDu01Rog6V0aLWo6MFmZjvbKMCQ7EzA/CpZ8J69O6DFqJmoNMCuyJYQu2Ib2Dmoh44FqLNwzSBfQKEEP0ja6hsHFmiNdBqGdmj9ICdAy0D5ANdAg6U7MWDUSajFZkpQYWi5ALVIgXcRGQlosxony2HeGVJTQPsOO44b2BCBUZ5XAOhCFE

gdQPVo/UDfxGqJDa5qdUcA2tcCPC6zIQD2LFVAg6U4sK/OIaiPeBouRkDeQMEsNvcjqPto1oJ4PgxlFX56sixMOGxbE3wqas00Th+zLDRYXkDDJEDUkRRA5ahOqJowlEgwQPItJicg/mfYUmQDqNKAzSAHgMSI54DKnhjogVUmqN0uFqiM1xUcIK5yfH/OZaglinTgJOA18WkBWACyFnY6K4BlqCqo3qZRvXdoH850amAA1dwVgNBrad44cVBOH5

RG+RzqCYDWgSmA1rhCxDwLKuwC8gHovoDJgIfXKagEiX7IRjgKHFdsakgSJ1Xw9SEW7mWoFKibKk4omrC+HkGeCoCPLiqAlOit6PRA2IJd6NyAmplUgOkfQqj68V7Obu4PFnWAfwDp/wUfZahYqMRiCNxEK0foyICAgMlxGICNpSGmKfDE1GteFwDBnhqsStdzq248T+oZrltWCkgd7isA1tt8KgRIiCFK6IAcWoFp/lJ5NP9+HyQ4byiR7Db8VL

h/KPV5PQC4fiD/DXAVkUvnQXpI0xkUXejS7n0Akhj0/Q2lOD5AlVzYGgRFAKWA139942BQuahXKIrqA2UPKNlXK2D3LGguSQCyGLI9Da4+LDlBSjgxAMEYm39i7A2oURiljgCFC91ueT+OHgD6LQ2oKLV1nBqsILhAsLJgbgDPGF4Aw9gU8Mfg2gIKYJPwBgC/MJ8/VyhFu2B1Bz198wm/KyiyAKl/OBUbTgeoqagbiITIlYgSSDrRXADE4TB1cE

1pq1GsXsoIlR12Xc5i5xbufDCkOCZRGgQQtUMovEhQmLpCcJjCf0iYzTDmoW5BLcRm207sSADO4n//Pid96i+EdSi7OmzJB/9Ifx9WBsgX/zkoi7MLkOO8fK8/uV+/fEF/vzCRWmgBUMF6CupMFX9bKZkd/3FIy/9o+zgJKG4NzgVOQHht/2LsXf94gQ7WOjD3qJxcYoUO/1H/bv9r6gVoh7Q3KQvcN/4rJG44Ev8dDhz/IOp4OCU1KuNGIkKtRv

A1mOz/cv9NmKx1KeFPLloGNiQu8AOYsv8TFGOY5HVTmL4sc5jf/3j/MM1w/0u/LHU4SzxVPQFojWeYsP8nP1ZEWwCPmPolYhNYXk0RN34ff12NLHUCPHq8KyYa4VmOFRYTFV9/d2iAETEoxW5OfHDOJjDQWO9/ZTCKYSx1TRVK7HBgqSjjf2gxB39PhSpA9qs2TnrIG2RavVrHM7V/ET4sUljoKUGrCli3JHNbfalNf3iBBX9r1jlGZFi+KJruPw

5mYXZYlRCdf25YyWYpNU8OQhpBKPc4So56f1WcezAJf3arIt4xsU6yX7gRfzaeBn85WN+BQatFWIiGZViXN1YSTH8JvzJ/X/1RWKAwgGjHAK7wEbFxvwR/E+UsdTYo38F4VViCDRsgf2sNFcU1cnarT9DqbGRcByjG8DJsFv4Qfy+xLHUPWPmQIp98Tg6oQeFE4M+/N9sT2DoomtgGKLwaMNj3vz6sBFkViGjYxO56KNFueNjRZgyOMawSYOqLLa

hSKIKwqM4hxyzYxr9bv2TxH7V8KO+7D2giKOEbWgIWoKhuTjxo2IsdcaZOc0keaQ4VBk0gvwo3LC2odCjq43QuHNl22MO/LfYu2LUvahFe2KJHZmFC9lW/CEZ1v07LX7ge2OhHRCj0FRGoeMddnQvA+djoEVMJSGjOwNE5Nb8puTnY6oCO73Ao9FjO5U1g6cVV2PPAg9iW1n/I3qxAKKgbEsIZ2P3YqxAN2Nu1DB4ESjGmFzcH2LXYq9iHTklCGL

1ZUhuEFdi92J+UZ9jD2Ie0K+Ek5UGZX04osNkVYDj12LA42aA/xkfIisxNlVg4x9iQOM2/Z9ggbki4fgo63ALeP8Av2MvY0DisOPquRCcljk/KTOEL2NnY4ji3EXKCckFTyP1Badjv2Jo4y+EmrFl6Xx5+rHrhODif2MvhFcixgk04AKw9EMI46jjMOL3YViwN1li1BgQ8qiY4ojjROLzhWciuGmcoBcjd2PQ4+DiwmxHedaFmkXW4GTgqOKfYuT

i+yNP6AcjjS1kJGTiROLX/PdhOyOjAxmiVtWE4vTjzOLzhS+5Qjg1lDXAOfy7hbjiWOMrhZsjzjTCYSijbOIw4+zjK4SjQmsiD3j2cUzi7OJfYluE3kWasZlCMQJ049zj9OIa1HMjyTSUOUi4sJz84tTj8PnhqJuIboS4aO+V0uJ44405oyN1ZT0w4yLC4/ziIuJtI4MiOMlDI7ZwvZV048riEOK6oRAjfSO0A26FYHXq4jLjdqEzJY0IAGmo4FT

jmOIS4m0iJLk1rF3hzSMo4+LiAuIa1LeplNjuOD+p0C3y4jzjNSMChcaYJ0QK6MrjOuMK1EsIQYmEKeNIe/jQ4gbjJuKVI+bpnQNFo2oEFuMG46tZxUPWOdgQekRs4jriCuJxhaUibmIOsOUi3ONU4h7iGYSZQvu096mJA3g4JuIq4t/IGWUYyH1RjjSwnfPYZv3tA6OwLtzV3UYFKvGvEdP4qsJphQb9jvDm/aHjWNh5uZm5wqQVSD3BK8HB4u0

CUeISueb8aeXfVZax4VWH4ZHtPoWR4yyRCeLR43EhxqLCYNDEb1HZbPHifeAJ4qHijuDcdZLUcXAicdXVpv3x46nj2eL2hKSxnSRADdo4+eNZ4gXiRv16oaXxBAP3qYH0ToSp4nL8peJFMWkiCbHpI7DtxeNm/GnijuGy9BK5jz2tkRLpNeMh45XjhoW4ZCIly8mwRIyEZLDA8D4CZcIu4ckjjuAN0dHdAIWt494CD3Dt4kUx3cW7SWQlIzhIOV3

jPOhA8MzU7uCYzIkiYMzs1Vr8bePd4oPiRTExIsYUgKM04P3imowD4jr9vOD7eUDF/SxqqNsF/ePa/D3i73jEBRWUGiN0tSaFs+Nt46Pi73m48JkC3aNPBEvio+M6/NXcESKC4JEjGYBRIl3ik+Jz4svjGoQDhU5E/hAy4KaxE+La/Uvi6+NY2S+dISNAOJd1++Mj4wPih+NxIGVYdsKxIjHwFYPBKAfja+I84H4jtNVCYaHti+Lb4wfiPOFSQkr

VGtjQwifi3eKn4jzgXiOHqKoF6kIj44/iU+NC4YJDMTETlHRwsJyv45Pjc+PyhCX4TFFV/e4jwthr4k/ij3mcQ8kCA6LdhI/iX+I747CsTiKT2ejj4PC3+H/ib+Ie4d25+4BYQ/EEUNS345fjf+Ie4LRCCbC5+UJgErmAE9vjp+MM1XYiS8n2IumVn+LwE+nspENIuZnDGblwEnfij3lWIlu51iL4hGgSV+KPeJhDXRBkUPU4n+KX4yfjYBP8hR/

0DfHRuGZ0s+O34lgSHuDmI3ECFiOYEtASnOETuZsx2LDV6awgpBN4ExaUf6g39YsI+5mEE1ATlBLMhUYjk9iTlCYik1W4E6/jX+LMhEVYrhBn7GLgreJEE6QTeiLXuVtVMCRe5UgTaBJgrPojDdAGI8btAthgEkwTJNXVCLL5IaWy4zQSeBO8E5X58xlK1ZQ5DtFFApwTRBKc4B3l1CX3xb/sUBKCE0ATJNXqIvKCfIie1KISbBKE1CgwzNTFSEn

lagUyE7QS38lnQvc50pw2TJQTghLh5DekKiI/KPpAb1UKEyoS29F0hb4QmzRRcb/jrBKKE5SF8iKzaCIYiiIqE5ISuhP7zHoS40gCVI3i2eJN46SFS8nzIwVxEWT0QlniteMF4sIiMiMwRMxNE2DGEyXiieKE1UD0z7gK6TuIweKavCXileM2E4oSEiLPQJIi/Gkp4iHjxhOOE5SF94ON1AdxGvHWEo4TaeJswcIizwkiI001agXmE43ibhLh5Lr

xqwRzYQIikeKuEjYSXhJeoPLdII1INbxhceIOEhYSJhLqMCDiXXGFqeAUSSG+E64SwRNcgP8YIKX2cJ+4nhNR4o7gsRKuEHETOLjxE7Xi2n1KnNg9YP1L7bp9HjxoYXMADGlzAfGBTADaAIwBxAxgAdGAToB4AOUhqgGiSWnMKP3QOHBwXWxZOZ9t4T0duH94InCvzLnMLjBlAnZFlbjzg0vY9HjxPZJdNCm5RAkoe2Ua3ST8bD2k/bvZZPzyXbm

9HD15vCdk6TynZBk9UO3kWb59/unKQAJcahmhpaOtJt2tIYG4neRM/SF9HvE/7Zkl06yujOI8pTw23KDAkj1c/Tti8rn6Qxyd09l+Yi79XCxtLfL8D6Ii/TF0XlkmJDxjofn6ac7iA+HIHXZo62IGsVqDC7mcGX1iev29UUH93XzDlaVjuf0Z/QxN3enhY8FjexVDfGl4s/2uYkhwIp1z6XH5hmPFI5cFuqgh/ak4ofzKY6AFnzEyY3/9smMTUI1

8+lVMaPI5fGPZ/IN8a8ARuAX8kCk9+b7ZzGO8/Vz9BrG+2PRjDf3T+G0tIghd/Ush940EXXPVQzgD/MiVDAPY2VMsq/zPCMXDKxNO7b+jn6P5lG0sL6JSAjf8RYIY2aGwwv0qA05EbSyaAzbM7/xqPW+pB6MhpEKFo7QY2RYCUDk7o/eohmmlwkuijCJNEIZpM6LOE7Ojk9iGaBOi4hItBdo9qAKFcCQSWfhTEtyFqPkcOO5xls1mzUaoXaNDoPk

CFJ0xfXUpLaNl4lUDh+VGqA2i+CQ1o8MjRqllo1UjUrlQkm0idjS5o7QDmxIUHemirOIpo0ZocaLI4lGjz3kukCGizAMvw/sTkWLsaYcCHREcA/MSAETeo8VZJmN8AhQcKyMWqQiSMTW4o98Dqe0ukPTDRmhrQhoDRmgIQyZptYOVgzN9/Bzxg5mCrJjwQgAcwoChg1GDPoMmaa4DPbFx+YWpJmhehJITbxPSHQXwgQP5KQJxDJOr5GECLwmluP9

5OknxA7eiiQKWeV5DzJNYwGkClLgneTgtJmjZAoQoOQK2wyZpRrCWPYUC7k33E1eQZRJ/hOUSzJNjfeMCMpLlAg5ovdGuPSCVndgBvCqc123YDGYw6wFUQJoAvgDlIFoBJAB+wGoAzQBOgbsA5SH0AeIBnADNACPwQTwK8FLdcUT6nattvmg7iG9QFILhPFQZB4RqFZ/1qGWOGWmgfXEjOCvxZ3BJsZwCt9lb/NwCYSiVEi58VRNE/RvYtp01WHa

doO2VzOr4PWE72eT8jpzklc6YTRLcPOVELVk8Pdko5WO3lHfZ/D2YEB/sfeAyufGxnRNMlEU9zP06OIUM/Vj+nLW8/+wY7JSTgEn9Eo78LcBcsFz8O2LBkwMTJ71DzaL8nP3DE1wdQZOHYmGSe0i8/NX9JN38/BP9XmOC/CAIGzEP/Q+jIvzzsdGT/MJEKcuwqv1do3WFR8GGRCxjXP369S+YSiNrHDssHxMJk+d0O7C8EszU7NnxkqMS16WO3Hl

tYRON48PDbpQpkvCT3aDpxCEIoZJRkn3Ab1SGiVqEavypk+ApE2KTglNj+hPwEkA0Sf0NYpZIY3xZmRXjhv04YmaJ5f3kCRX98ZTREyXj9ZN2iMsTsWMkOOLj3uMW4qsTS/zv/WsSSG0lk8r9GWIiOBsTF/1mZeIFB2Lc/LSDnmF3cc0iHCSQpAH8KBjTEwnF3VVnow4FWxJxtZ/8XuVDkxNp0xIbY6FV18AgAnsTM5SUuNhsw5J6sFyhI5KaoVO

TRoTR/WbcfZGu/HNjOYQ5CXH8wmIJ/VACw2OzYpr8RCnLk43ZBxNZ/fADkSgqgEuS65KHqV8wernuOYcTELgTYkuwk2JHQuV4NgXpgA38GCIPfal9uv2B/XMSA2IoHARjrf0bOXzV9WKtYwOwtZIZ+IhjA/2MUHQ1rng1k61jaqkr/VCojxNbbVViZWPF/ArU8yzPEwf8FH0FY7X9Ff2T/aPpygO8AiL9pMNGbO+oOWKNk69Z75PKzcYCvxKvqaO

1PwBN/bGDLRzPLduilgIAkuvNMWMxsK2SkWOV+YCTDCNckMCSV9HHsKBTlAT9/MIj0AMgkv4D2W1xuF5i/mN75WRt02DgkxqMyHHhqXBSLv0guInkyQP9orCTvhUpuB2SNmI07a4i2AMpk1mV9WwvWdZijmMYUuHliJIlA4QDuJyNyev9LUOWzU7gKJLFIlup78AEUi1D+RBskA/dLjSYkrQCAwIB/Gl0F/w3WL2ToSio+Iu4OJNjAsl4hmM9kw3

51FMXzEGJt2KEk2pjA5NeLUy4kOH+ojBkJJNMU/eog5IsU9ICTKOyA4pi2xNKYtGwo+xEZTNC5UJJvRuhuxILknJi+AkGgmaDGsiOYJACqf0J/QlM5qick4wTOZLH0JuS8AOF+JZJ8QI38e/5UwxPwccSKAMnEh2NSAjRAtKiV0CxAxxj3Iml/FxipANhbCKTAqFb/bNVClInEmX9slIbkWKT4bDFSTkDJXhV/WcT0vxzo6ggkpKFA0zNJpwvwVp

SMZKOOJghT+llE+UDe8BnEgZSOlOOCI0DkTz6QSiTR8EXE8eTRW15WQ4Thv2+FSE9Hzn0YtRi3QMN6Dm5TOHRsdNtWLF7hBeSxDl1g6lscwP94PMDQoX4Yo5SJANt/O/NgvV/BSsD+SyDvNcSJsLKhHlsxYRRcTo5mwNLZQkglAPYY1QDd5B0uRcD0gRBImXkdxIMAxpcUeG3AzcFSDGKyJwCaGOIY4xRQ5hYuVU4HwMxOH/4buERUzeT7ehRUq0

p7wM04DFSMfBu4WqsRHEntfh9SVBAg78CzvQggsSBSVIdEclT5CTggkfsxzhj+LfJU8HpUmP90/093P89MILIaBzo+3zpUhIAMGMZUvZd1hxIgjECyIO8YDlThVLJU2P8xVJd+DiCAGi4gn1CZVNT/UVSeVL4vDSDoZKCkbKT1gE5UzBimVKsgu+obINr8crw1VJFU+VTNVJwgCEFTFVig6KxEgLgYo+T0eSSkasIyWjMSS8QhXBu4J1SLmRdUvH

hmoMTkjBwDdh9Umv8elggIraCR4kVEcMDLAOdUisxBrlBgzaxjhW9Uw8TfVLjU/mCbTk0uOOsGYKt5Q+TU1NmgwG5dzgNgxrIfcGNgnNTRcNbbGgt0an9g7OwPLhjXENTjxPgQLOC9EhocYsg9VOWkqVVQGKcOU+RW4NJ8CJguSit5EBi2/2sYz+Yqk3Hg2k5OBHmoec4VpNcAsBjT5Dy3aeTXWJdQ9tSE2k7U/Gx0EE0OD14mRgAOFoJgGOnU1d

Th1LuSBIiHlBLlU+Fd1I7UodTz5HcREqxPTEp6SYiV2FvJc9S1pPPkKYT4HguA/H5nlKnUx9TZ1P/gkrVLJ2AQs9SV1IvU9B4DWL3kvbhP1MA0p9T0EByE5e56NBkdX2Zl1NWk79SBOHsBRRwYM3qQhDSZ1K7UkvAhQgfNFbQrIQA0xDSsNIE4PoiTGPWCVywwNIfUiDSkNMBSJBD7OhQQ2RRYGMo0wjS11IE4EVYixI1YydSmNMw0ljTAUlUE7B

C27CyNAjTuNIPUwaJE7mTYW+45uL0QjDT91J2kahDW7FoQ1kQhNJk0wLAmENCTVdAzhLzOcDTmNJE0xrhhEMxsbA5aJU40wdTINKUQ9Vlb5PNpJTSgNNM0nKpoUlcoFrEl1K004TSdpBOImxDTkTsQozS91Ks0mBhnEMz+PMFpHl3VaTSvNO8Qu+pfELlSfxCB1M80kzSbahiQ6njwsMN4iLSv1KI0m2pUkPBZdJCbgks0qLTpNzyQ/8sbKygbQL

TMtOnGWIESWM3jYNSuNOU0kpCpmTKQ/94EOAy06jTpN1vdI3RHBUs5WrSktOk3CvjyfHhGEIRr63y0urTpxlGsPNgRQghpCnjLNkc08rTnC21LGZ5WXl8eFrSeNKXMd3FvlCjBa/g0GNG0oLT4p0mQj2EWvQ80xLTZtPinIDw7Om2fBiCHNLK01bT8sAdudKcAjiH4VVD71OM03rTTtNZI3ZCqBkIUmbSdNMWKM5Ds9mhYq5DrtMi027TMsG+QhK

5fkPGsZ7T75DhQxP8EyyB0vFCVHAJQ2vlekmJQFbSCtPc7asILMTDofRw7nHB0r8wmUOn1TuMETAo0m7TWtOZaLs4L6kqeMrscdO+0vHT8sGRBezMczhaCF+SetLJ04LsAnTH/Hv91SIS0qjS6dLgqU6CBLidQgmxNNOO0+HTgu2jI7klFrBNaZNTcdJ208RVBfBNCCVlijjy4OHSftLgqN79o0NuLJuw0dIaLRziyvDTQ3qYVdPIBTwEkklUUZF

xBRBJ07bSXtMHxMtDmzArQ/UEQzll0tnS98FdVbeVvlL/dS3TedLl0m3T94TcVLEJeQkN01nSxdJnQm3p1jmWuMSEtDC10noxZ0MiRFUtOjg9/UkgndOt0mvARcI3QrfJyXDvlWnTvdP3Q/8j1kIW0jNUg9OvMUwkRMg1VegRM9JTk164yvFH4DuI21Kt05PTHNh6ONaEKnj4JfPT90KfQ3sSrJBl0qPTy9JrwA/41izMFfMjThST043SP4FmkmD

D9qRluT3TtNPy4JlEFjg9BVSc0Gy+0o3SH+iKyYWodmIxAutTm9J701sY4CQ4wr5SMhSn0r3Tl9LP/NbF36jn+XcRutLL07fTZ+JZOUJwflB/TRjTRdOP02Yl9BPQuJY9a9NIwq24hxPkVRAkH9PkwzTCxOE5AnTCm9Kv0h/pAmLuOL55bfh503/SVlU7iM79jMM7hbvT8uAHOVBCWsVs0ugYWdOH0szCasgswk1ooaLf0w4EJriKU5xjc8VK0kA

ye8EgY84QVbDrI4AzSdJb0zAyAGJ/lLfZ+vB/0sgzt9M54sJgAhGT8KyQMDKaoT/cf0y6iCBxH6mteXNTQ1P7wNG53MMHsZ4QKNN4MhtTugQnJPMVrcU5OHgzy1L9UkYEzKRXQOxCCtxkM+Bi5DPeVMLDq7CghDy5E9PrUitTx8DfOJypEujv05bSU1L4MjYE0sK4zVZxwRhUM2NT81L1/PydNlN5LR3TRDL0MlFUPSX/qRClWREdU0wyxDJRVeS

4ePHLMW2CY1LzUiqCmqBQfCD0Nvy/cHnSXDLUMrkt5gUFWf2oJak/o4IyzDL+BLepa2H2pLoVStJiMtNS/gUvecBoSBm9wb4UUjN8M4lUOy3EAoRjnwRsMkIzngV6JN+odbFVLPZ4SjNcM4lVesOYBYoCDnGqM1IzgeAa/FGjJ7TeZPbgDVI1U/NYxsOUAt39BVgtUuVTuVPzWB/VT2BEEO9T3TiGMq1T81nmwtLJFsISBQYzZVIZU5YysuE8BGI

UdHGxMODDJjO2M6YysuBcrZuwtYU4aJdSljNOMjkEsRzfqMl1MOXQYqYyKVKy4Ev9n8R4cYiEKSBuM14zBQU7/egtyfErsFzdnjJOM34ztQXn/MzV9Tgh1eagfjKNU7UEIfyFcSgSANWOMrlSwTKlBc4VRbQVCBaw8uFhMhVS4NVxsBtiSsRY6TYz1VJ2MwUEEbjfqX7NCQVdw/VStjNRMuEzXSzpJOrIWiCEKFEzDVLxMzUsIOKZHU7DaAjy4bF

TdxKhUtFgSFmt4asUzBXv7WSB+TMhU90V/uCucIL9RTJsgg3ZVxPGw8YzzZLqgLrwvZNg0pExh/3dOJUyxjI4Y8zgbsI/cO7C0bG9SUQD55NuU45cxuVXEw35IzhNMtZSFlIMYmSZS7lBM1JhAeHGU0mTBlKXYA8t1myTaBLNGeScYygD+WS9Mr4QfTIK4P0y4lJ8Yl/TELhkmKdSeemeCD3A680ksSn9EmPLMSJTNSyliJHCKGOLEQts/FOfQgA

D/sKxwqoCbhAUAkldczIb0/MzCcOhsYnDxyi8YXvBo5Kf/DsTwcKpw6XFNOC//esz2xPcU8HCmcKhsHFwpuRnbAOS7FPMUqG4ZJkQabotVHChqLf8OmMbEtRTn71TLWN1bDJrsQHhO/ye/Hv9ZFJIzaXDchOq4zho6/ykUxv81zJI4B4CkoVhxRRkzjmrEx2SK/xuOWt4PygpMMEl+SxwU0MTYv3+4WV1yQX8DZW49HDhYsFjoFLQmJXCt9kpJbV

oiWPt/IBTN43I4ObpV7DR/DxptIKRQYligLORucN5LaO1w6QpppJaON+ShWLvkkCyjcMz2E3DSLj1Yrn8xf0Z/c+S01T56LfT28EtY+H9V5I+Ocjh3IUOhXRwdXVP2J1i/WJnkt1i8y0LA7Ld4pimQ+iycxMXUn7g29ONEJ44dbEXw0WYlZMjYrawE6kdwhVJFHALOazkhLOTY4eT81XiVNQ4L8UeAmuTS2NzYhuT81WT9CCE5CWfCREgt6gTk8O

Sc5O/EWaTLhCZGFiMdLLDOK/Fs5MLuckSbjxAGRz4iygQ/Cvs5QBQURoQ+gGGASQApEGYADgAqylVIaoAzQBS8OsAKAGwAbvsNdD0Aluo+fFwKOj9SZBQ2Q3wPjgghO9YaZLaU3z8d6QpvBChkQRSufdx1dSFcdlFqtz4lcHIAqjWmMT9bnwyXaw92b21Eo6T8MhOkhw8D+3+pPm8XDw+fVS14NnU/JQZBt0a/SDUNfkCDV5DuTwI0A2UCcU+mQU

9UaWT1FW9vpKhonVINb3m+eUptbyBksKSprJBkl2TjvymsQXJ4ZPIUuL8cigSsgZS59z0pakJK+M4A+cgGhIGEjppkZPK/Fs1KnH+4xrjZrKHYo6zXJRL8WuSy2NJg5ylDrOO/Y6zugmdYwU4+vzB/Fb4HrL8KJ6zX3FF/dVjef29sT6zsZm+sq+B5sPfk1RCRWIOsuayvrKuswBT6WNwYt2TlSkBs1s4rrK9/FBTEWPusqGygbKus0hSHzKT/ft

olrMi4be1zfDPMhhSHOy1qAmz5AgPcIGJBFOkU6bR5mPBSCmyufnaZZRTOmLUU19FGbKJs+cY6mPsUhjR2bOxkpz9ObNBTSgZXFJs09xx7P35si79BbJ5TMJSUzKtPSOwObKps7Ql4lN7ks4JxbLIUwmzFbIDTfpSPTJYAzHoFbOZsw5Srf1uU2Rj5bIlsjWz2mW3EwUocVOD/NWzcbKZs7aQfDIQY22z4UMpsi2yj9OipfWz2M0vk6IDULxrwNa

yPTL8/MPpV/0vojf80ZKsQRKzMZOFDfein5JQxAHj18H9syxjlznSNKIRmgPXo/jhaghJkxOzA7MKNH+T+gIGEdoJM7LnE7OzCfTOAuujLgONmQuz0v2Ls2KYfgMwA5m5/gJwgFL9aZKrsi4sI6PmIlCSn8krspKyvO1wk+WSWQIrs8Oz1rNbsnhTlQL4Uzz9B7IDs1uzaJJdA+myIWi7syOzaw00U8mjtFM7sieys7IuLeR4jFMEkr84YaKaoBO

yi7I3s6ST1wJPA1ezGAPXsuLAVKIACeeyk7JqA4tCA0NPs5uzu7O0ZOZDkkNRma+zq7LMZGYDwoOVg05TG7P3sluyKWEsk1aDgYIfsiOyb7OVjDoTVbFAcoeyKWEBA6bRgQMDhaBzJ7LX3AVVfJMq8fySkHPPswKBclOx6TEDtxEwcg+yKWCGuDECKlLBaMbIM7LXswhzAoAaUs3BktQ9oAhyAHKRte6lO+A94SacGHKfshqA8pPsaUZTf2Xfsi4

tqiSTY4tSltQLsyhzGHPnNAUpzonVosOyz7Kocwm0QRKV4ykY+HPeZWkUQwK5Bffl2HIXsym0ZEyTAxuJT0Q0c8ByLY1STC5S1FHA8W3d47KUcklkHlIrAq3humILSCxyGoE+UtkYtfxbuPmS37NEcjhz5MGBUjxlQVM2sfRyP7OnkGFT1dDhU3uxFHPcczRyzWSBOMzjB7D8ci4trqXe1K8UsEVcY4097HKgxJkZohGjJV8x/7I8c7/NCySwggV

Sk0LccmRyxHPkwCVTqglAaGSxMnJSctiAlVKEsPAEJDlCcopzsnInoYSCxrHS6TDRQjOfoEMSXbPtswVBtVKlkgxx4MU9swVA/mVGRYyDYZPsGIZyXbXzsPEldVQpMMwZnbNB0qWyB2GiggOxU3EbmELF+Xgusx6yKKzSgwawMoPIcnnwkbOR+B8w3VO3EbvpekWztMXwjnOBsreRTnIysz1TaQmss4qTbjynWWCVgb0hRLyyoAEZAaQ8Xih2MLo

BCQHq6DoAmgDIANRJ5nyIlHh5qJSeAXkyKiOR7WGpAtV68AxxcAwG+HiRdFNUU/RSTnyhGNyT4HI8ko9gl+xuGFfsRPwsPYk8NRJKssk9DpP2nIXQltlefE1Z3nxKXOVFcgFukwbcCGiZHU1l/DzxvNdltVXhTJpdSOwW3cI8oXz+mF8zCkRiPf6T4j0msmU9gZOjwTZzfZPBknH0YfGuctjspXIDE/e5xnI+szGzkbK4CRmyz0AWc15jEZI4qTV

yVXPJss2zDTj9bOxywnIy/AezGnPCczBBIxJjslk5XHL3wLJyrXP/aEWS+7PFkkzgbXMK/XhoYdhdcjgCSYhPmbmTbXMxQhrAzXnjEo4sbMC2slhTlxNsCDmS1ZODcuMSrSITEmNFdZISuVUzb+kZktbsJuLOtC0If+OAwveRYPGJgsuTjWPKWZNyWOhB7cNiPv2TY779lQkzcokNpYIYsriyHHBrck+QxvzIs7H8EbNPPJtz7K1Pk/CyJ1wO/aV

y2ZR3lAkytf05YmYUx7DVc1KjlRkAsuGzYLIlkrZzwZM0DAXxLZNQU5HYcQnHchdy1gyNct5jlHCzkjMTo7XvM7pz/mOV9Hdyk5MlpK5jzzNuY1MS9LMss6O1JFJXMmRTjpHMs+tiI5L6kVFyRmNscpeh83NLk5r8wSFfcrpjvR0/cjuTXbDBIAczz/2Dk/9ybrNzYyNYhbMf/DszPEUVkgeTlZKK3WmIf/38UvsT4PIjYmSzyCNuYGWyq5LlswG

5y3MHk454sPO8YnuSozKSU65p63LesyegMlOKUmg9oyhes/1j+v1eIbWzE7N1snW4p5JdYqjyO+hUYxwy+AKn+FtzSf1dsI/UVKRuUyozLTNLzXeTyLMY4hw1XlJVMg1y7kgE8zWSpv2TPCFS6GKMA85JSLME85Tyf3TpM9kzrVPVkkDSpPKNnXQzYjIbHRTzrWOk8nD0l9Ik4QsS8LLlYwxNu9Js836zZWOguMhMkgLOCa8ToSljcn6y1WJc8uh

VYEHvEgmSIv3U85+hcLL+s/zzk7PumV8SDrHTs7jdDZPBs/LNc7MmA5OTexni84VjNyVAU/8T+Lj4nIdywbPS8qdEorzLs/YCoHDS842S3FDgU4w5QJM1DErzh3I/klb93Q1rs84Tk9kimKdyzfy/VLSkveETo+ISoQOBaVrzHf2G0tuzkJOjo3ry6WLa8q2VV0SoUzCTh2NHlaCzp3Pa8sPdmFNFkuJYL7yBCPrzSWIG8kezraOguL+S61GQUhF

ioWVyWXhNZlLEUzWirOyXcxFjDvOns+QD9zMgU/byKxPsgTmiFFP65A6RUbLu862THjSXsjMCV7NsOTdz/mOwZGsCeJJ81e5DQ/wPckQCfIAEkjsChJNO/dWy8bOWgKxSRwKBorcYQfNB0v7zo+0PAiZiNwMJ2X7ywfOCo+6iJpHYUw5jreLbVXHzLqO8OEmzbQgEsZaBRqLwXAnyaxPtySIchUKogrlDxPJqoM9zYMkp8u88WIKBQhuzZ6BmYoR

SYcJ8gcZDtUL582myBfLGgYyTOoNMkthcRfL3MwBz9oKskkByzOQ9ktFzISxH3bD47JMnJDl4pzL0U1Xzp90gc/azZF218lXzvZMX3LFyjUTK8PzZ3ZJUUt9yFFzN83FSQQKYPNqkoPw6pGD9SpLg/N5zLFxDEJGABQAYYZgBuwAmcMhgVeAwWAmg6wFVIJGA48iG6VG9pA36k/hgDJ2Scen52LHrYDZ8OPlHOQXp3LGiPHiRHXIMc0rcrSDcvWt

hanPlSVVS8XNK+Aly8rNVEngYIOzufNm8yXLKsilzbUmOmENoFo3klVw8D4h4AbbZ6REQ2BFwNDGy4g1Cto0j1LQY9o3ZgTYVHLg+k5W8Ijxt0FAE/DzGs01FwKjFcxI8qX3n8kip5XLljYHx9XMe3fhwlHIBstVzjnMR8H1zmQLlYrfy53Kxs0TQQ3ITcsNymAmX81xwY3JSeS/yk3PkctJhHkzlc7fybnPbcJtztXIRkk1zx2mPc59z3/LDEz/
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

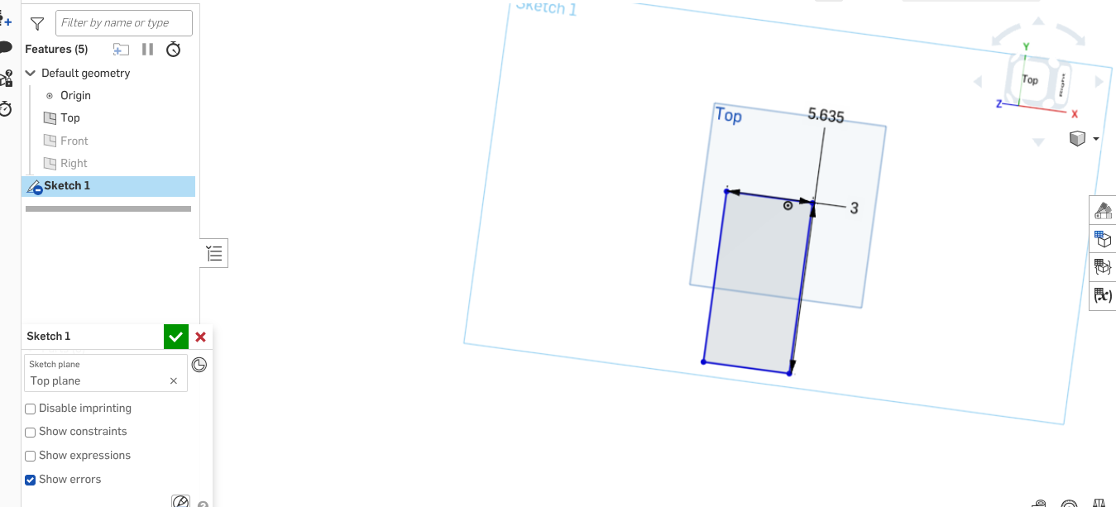
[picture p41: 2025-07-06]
journal/Pasted image 20250705194907.png

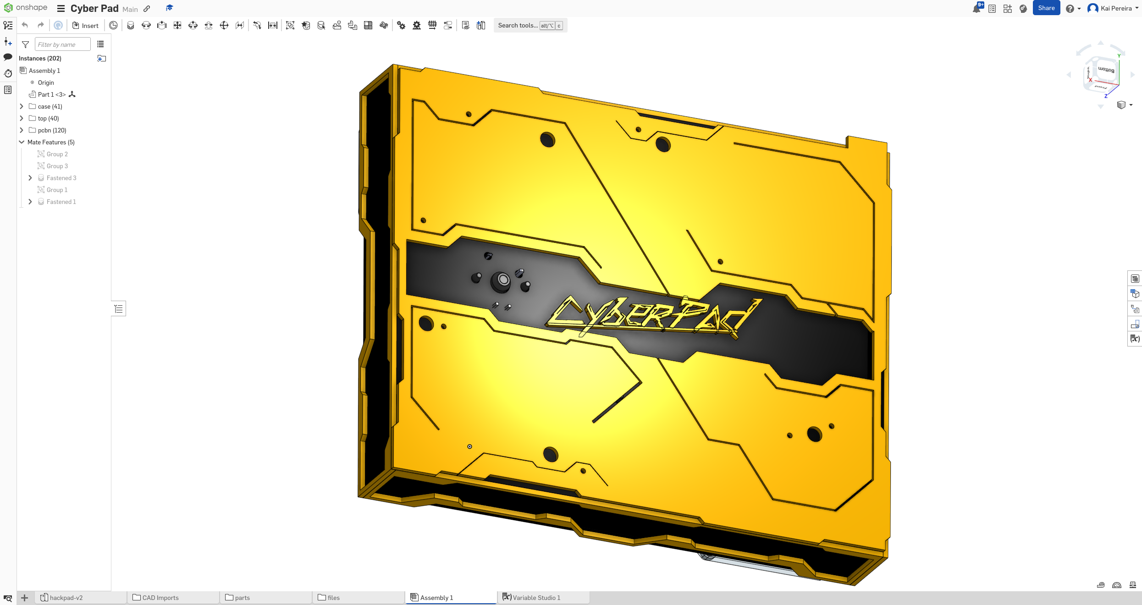
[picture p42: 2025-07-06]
journal/Pasted image 20250705183502.png

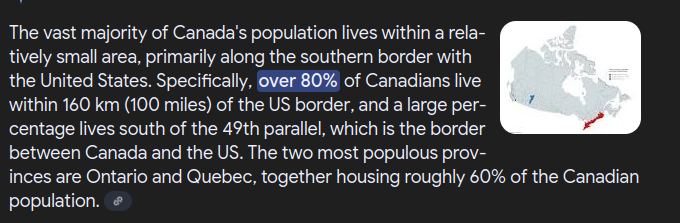
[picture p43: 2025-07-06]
journal/Pasted image 20250705222120.png

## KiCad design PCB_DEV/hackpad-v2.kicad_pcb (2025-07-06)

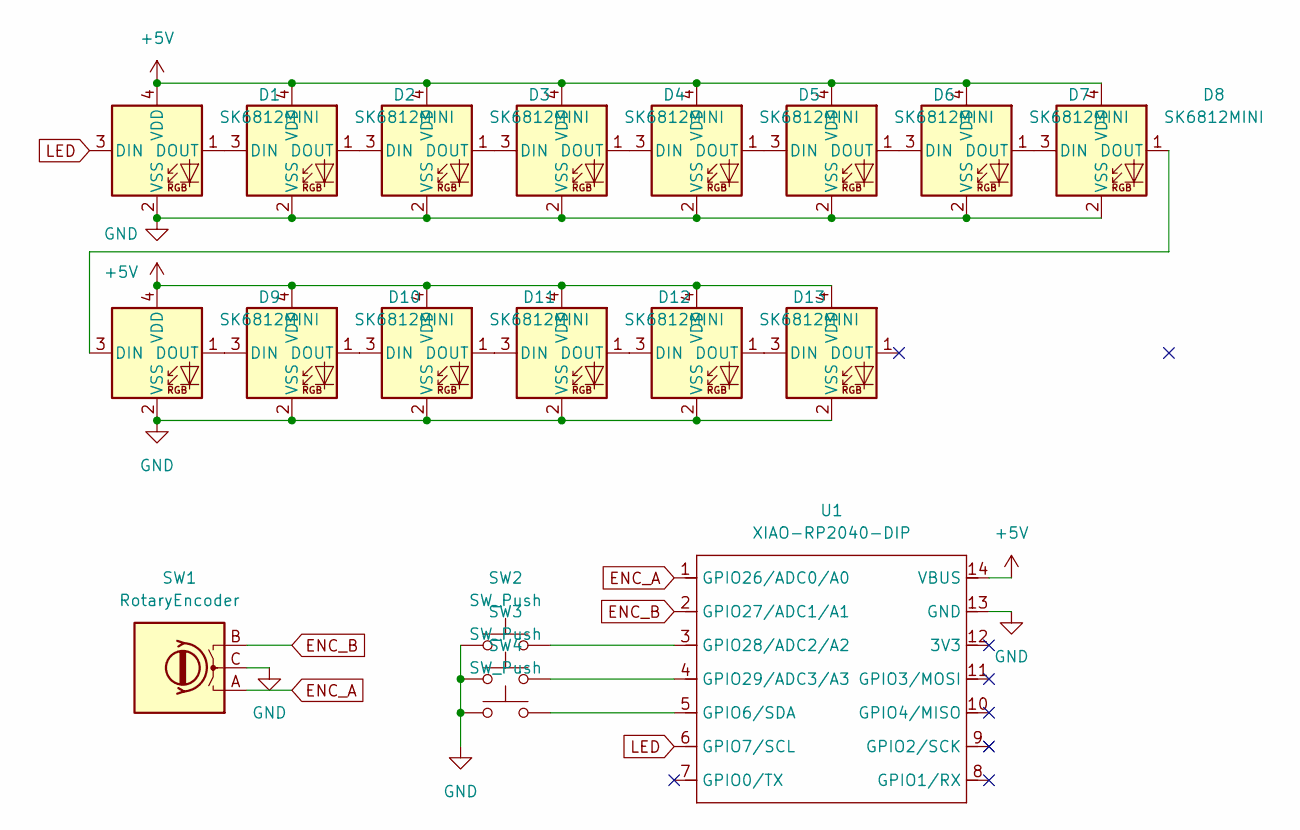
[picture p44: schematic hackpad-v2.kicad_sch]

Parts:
D1, D2, D3, D4, D5, D6, D7, D8, D9, D10, D11, D12, D13, D14: SK6812MINI; LED_SK6812MINI_PLCC4_3.5x3.5mm_P1.75mm
SW1: RotaryEncoder; RotaryEncoder_Alps_EC11E-Switch_Vertical_H20mm
SW2, SW3, SW4: SW_Push; SW_Cherry_MX_1.00u_PCB
U1: XIAO-RP2040-DIP

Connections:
+5V: D1.4 (VDD), D2.4 (VDD), D3.4 (VDD), D4.4 (VDD), D5.4 (VDD), D6.4 (VDD), D7.4 (VDD), D8.4 (VDD), D9.4 (VDD), D10.4 (VDD), D11.4 (VDD), D12.4 (VDD), D13.4 (VDD), D14.4 (VDD), U1.14 (VBUS)
ENC_A: SW1.A, U1.1 (GPIO26/ADC0/A0)
ENC_B: SW1.B, U1.2 (GPIO27/ADC1/A1)
GND: D1.2 (VSS), D2.2 (VSS), D3.2 (VSS), D4.2 (VSS), D5.2 (VSS), D6.2 (VSS), D7.2 (VSS), D8.2 (VSS), D9.2 (VSS), D10.2 (VSS), D11.2 (VSS), D12.2 (VSS), D13.2 (VSS), D14.2 (VSS), SW1.C, SW2.1, SW3.1, SW4.1, U1.13 (GND)
LED: D1.3 (DIN), U1.6 (GPIO7/SCL)
unnamed: D1.1 (DOUT), D2.3 (DIN)
unnamed: D2.1 (DOUT), D3.3 (DIN)
unnamed: D3.1 (DOUT), D4.3 (DIN)
unnamed: D4.1 (DOUT), D5.3 (DIN)
unnamed: D5.1 (DOUT), D6.3 (DIN)
unnamed: D6.1 (DOUT), D7.3 (DIN)
unnamed: D7.1 (DOUT), D8.3 (DIN)
unnamed: D8.1 (DOUT), D9.3 (DIN)
unnamed: D9.1 (DOUT), D10.3 (DIN)
unnamed: D10.1 (DOUT), D11.3 (DIN)
unnamed: D11.1 (DOUT), D12.3 (DIN)
unnamed: D12.1 (DOUT), D13.3 (DIN)
unnamed: D13.1 (DOUT), D14.3 (DIN)
unnamed: SW4.2, U1.5 (GPIO6/SDA)
unnamed: SW2.2, U1.3 (GPIO28/ADC2/A2)
unnamed: SW3.2, U1.4 (GPIO29/ADC3/A3)

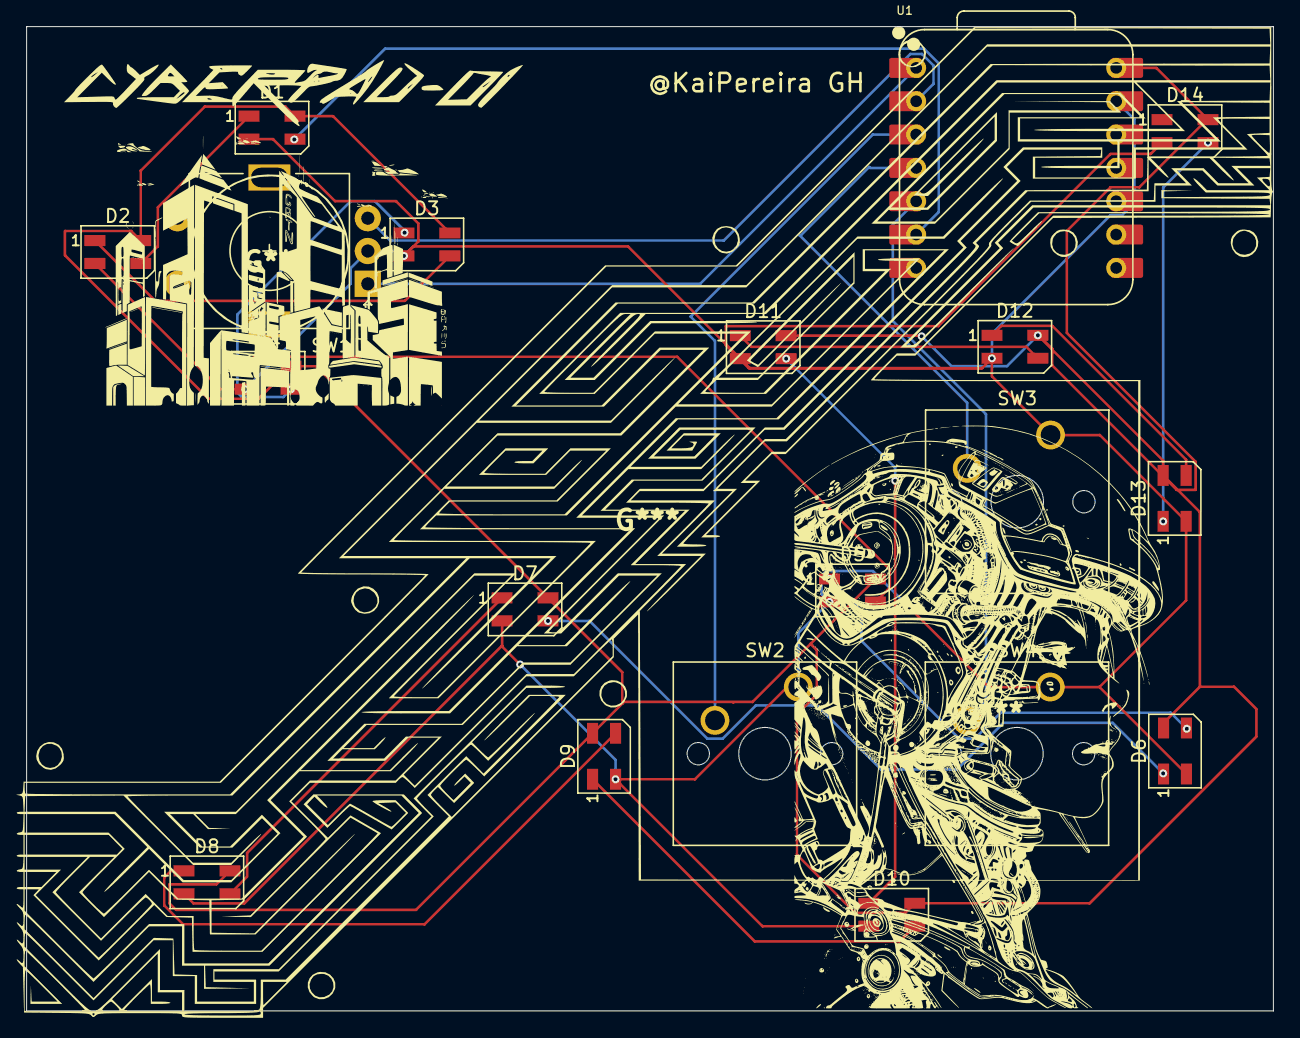
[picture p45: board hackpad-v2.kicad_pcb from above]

Board: 2 copper layers, 95.0 x 75.0 mm, 19 parts (0 on the bottom side), 21 nets.

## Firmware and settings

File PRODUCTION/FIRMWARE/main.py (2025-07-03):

import board

from kmk.kmk_keyboard import KMKKeyboard
from kmk.scanners.keypad import KeysScanner
from kmk.keys import KC
from kmk.modules.encoders import EncoderHandler
from kmk.modules.neopixel import NeoPixel

# Keys
keyboard = KMKKeyboard()

PINS = [board.D2, board.D3, board.D4]

keyboard.matrix = KeysScanner(
    pins=PINS,
    value_when_pressed=False,
)

# Rotary encoder
encoder_handler = EncoderHandler()
encoder_handler.pins = ((board.D0, board.D1, None),)
encoder_handler.map = [
    ((KC.VOLD, KC.VOLU),),
]
keyboard.modules.append(encoder_handler)

# Neopixels
neopixel = NeoPixel(pixel_pin=board.D5, pixel_count=14, brightness=0.3)
keyboard.modules.append(neopixel)

# Keymap
keyboard.keymap = [
    [KC.A, KC.W, KC.S]
]

# Start everything
if __name__ == '__main__':
    keyboard.go()

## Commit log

2025-07-03 added all my files so far
    [hackpad-v2.kicad_pcb, hackpad-v2.kicad_sch]
2025-07-03 adding firmware
    [hackpad-v2.kicad_pcb, hackpad-v2.kicad_sch]
2025-07-05 some more blender stuff
    [hackpad-v2.kicad_pcb, hackpad-v2.kicad_sch]
2025-07-05 updated blender file
    [Untitled.blend]
2025-07-06 some readme stuff
    [hackpad-v2.kicad_pcb, hackpad-v2.kicad_sch]
2025-07-06 added my bill of materials
2025-07-06 all the journal and production files
    [CYBERPAD-01 Base.step, CYBERPAD-01 Top Decorational.step, CYBERPAD-01 Top.step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]
2025-07-06 ADDED BOM
    [BOM.csv]
2025-07-08 update journal for highway site
    [hackpad-v2-B_Cu.gbr, hackpad-v2-B_Mask.gbr, hackpad-v2-B_Paste.gbr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]
